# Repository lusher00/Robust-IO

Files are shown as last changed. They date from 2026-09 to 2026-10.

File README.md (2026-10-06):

# Robust IO

A rugged industrial I/O board designed in KiCad 10.

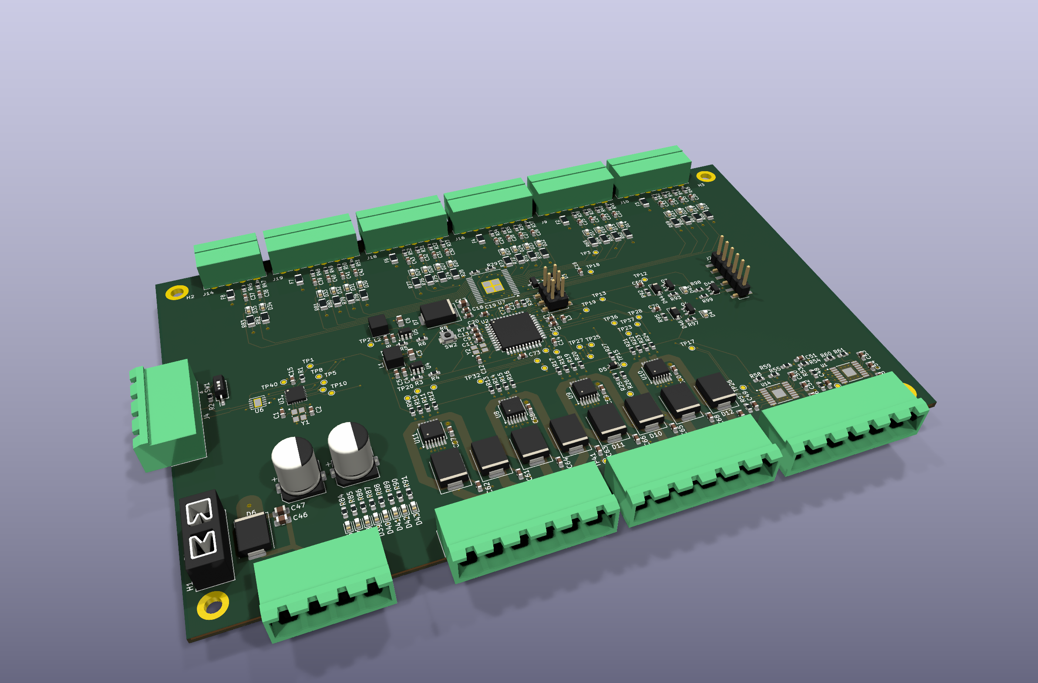
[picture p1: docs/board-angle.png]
Robust IO rev A, 3D render


## Status

- **Rev A:** released to fabrication on 2026-10-05 (JLCPCB, 5 bare boards,
  2 assembled). Not yet powered or tested.
- **Schematic:** complete across four hierarchical sheets. ERC clean.
- **PCB layout:** fully routed. DRC reports 0 errors and 4 library-mismatch
  warnings (J20, U1, U14, U7), which are intentional local footprint edits.

## Board

| Item | Value |
|---|---|
| Size | 160 x 100 mm, four M3 mounting holes |
| Layers | 4: F.Cu signal, In1 GND plane, In2 +24V plane, B.Cu signal |
| Copper | 2 oz outer, 1 oz inner |
| Minimum drill | 0.3 mm |
| Supply | 24 V nominal through a blade fuse (F1) and SMDJ24A TVS |
| Assembly | SMD parts on top side only; through-hole connectors and fuse holder hand-fitted |

## Architecture

| Sheet | Contents |
|---|---|
| `power` | Two TPS560430 buck regulators (+5V, +3.3V), input fuse, TVS, bulk capacitors |
| `processor` | ATmega1284P, MCP2515 + MCP2562 (CAN), crystals, ISP header (J1), UART header (J20), reset button |
| `inputs` | MC33978 22-channel switch detect with fused, filtered inputs and status LEDs |
| `outputs2` | Four BTS7008-2EPA dual high-side switches (8 outputs), two DRV8876 motor drivers |

## Connectors

- **J1:** 2x3 2.54 mm SMD header, AVR ISP (SPI is also on test points).
- **J20:** 1x6 2.54 mm SMD header, 3.3 V TTL UART in FTDI cable pinout.
  RX and TX have series resistors and a TVS array.
- **J14, J19, J18, J16, J9, J10 (top edge):** 3.5 mm pluggable terminal
  headers for the switch inputs, each with a fused supply pin and ground.
- **J15 (bottom edge):** 24 V supply input and ground.
- **J3, J5 (bottom edge):** high-side outputs OUT_0 to OUT_7, with +24V and
  ground.
- **J6 (bottom edge):** two motor driver outputs, with +24V and ground.
- **J4 (left edge):** CAN bus, +5V and ground. SW1 is next to it.

## Test points

41 test points (35 top, 6 bottom) cover the supply rails, SPI, UART, CAN
interrupt, driver control and sense lines, and ground. Positions and nets are
listed in `fab/robust-io-testpoints.csv`.

## Known limits of rev A

- The BTS7008-2EPA is rated for a 28 V maximum supply. Use a regulated 24 V
  supply; do not connect directly to a charging battery system.
- Reverse polarity protection is the fuse and TVS only. There is no series
  reverse-blocking stage.
- The input polyfuses are rated 30 V, which is a small margin over 24 V.
- Y1 load capacitors (22 pF) have not been matched to the crystal's
  specified load capacitance.
- Regulator output tracks are 0.2 mm wide.

## Files

- `robust-io.kicad_pro` - project file
- `robust-io.kicad_sch` - root sheet
- `power.kicad_sch`, `processor.kicad_sch`, `inputs.kicad_sch`, `outputs2.kicad_sch` - schematic sheets
- `robust-io.kicad_pcb` - PCB layout
- `robust-io.kicad_sym`, `sym-lib-table` - project symbol library
- `robust-io.kicad_dru` - custom design rules
- `DRC.rpt`, `ERC.rpt` - latest check reports

## Documentation (`docs/`)

| File | Content |
|---|---|
| [robust-io-schematic.pdf](docs/robust-io-schematic.pdf) | Schematic, all sheets |
| [layout-top.pdf](docs/layout-top.pdf), [layout-bottom.pdf](docs/layout-bottom.pdf) | Copper and silkscreen per side |
| [assembly-top.pdf](docs/assembly-top.pdf) | Assembly drawing with reference designators |
| [board-top.png](docs/board-top.png), [board-bottom.png](docs/board-bottom.png) | 3D renders |

Regenerate with `bash docs/make_docs.sh` after saving the schematic and board.

## Firmware (`firmware/`)

ATmega1284P firmware 0.3: UART service console, CAN protocol with host timeout,
output current trip, motor control, EEPROM settings and a self-test. Not yet run
on hardware. Build with `make` in `firmware/` (avr-gcc); `make fuses` and
`make flash` program the board from a Raspberry Pi wired to J1. See
[firmware/DESIGN.md](firmware/DESIGN.md) for the pin map, console commands,
CAN frame layouts and settings.

## Host tools (`tools/`)

Everything for talking to the board over CAN from a Pi, laptop or robot:
a DBC file, a Python package with the `robustio` command-line tool, a terminal
dashboard, a browser dashboard, a bring-up and end-of-line test runner that
writes a report per board, and a ROS 2 driver node. All of them also run
against the firmware simulator, so they can be used before hardware exists.
See [tools/README.md](tools/README.md).

## Fabrication outputs (`fab/`)

| File | Purpose |
|---|---|
| `make_gerbers.sh` | Plots Gerbers, drill files and the position file with kicad-cli, then zips the Gerbers |
| `gerbers/`, `robust-io-gerbers.zip` | Gerber and Excellon drill files |
| `robust-io-BOM-JLC-smd.csv` | JLCPCB assembly BOM, 50 lines, LCSC part number on every line |
| `robust-io-CPL-JLC.csv` | JLCPCB placement file |
| `cpl_rotation_offsets.json` | Per-part rotation corrections applied to the placement file |
| `kicad-pos.csv` | Raw KiCad position export |
| `robust-io-BOM-tht.csv` | Through-hole parts to fit by hand (fuse holder, terminal headers) |
| `robust-io-testpoints.csv` | Test point list with nets and positions |
| `robust-io-fab-all.zip` | Everything above in one archive |

To regenerate the Gerbers after a board change, save the board in KiCad and run:

    bash fab/make_gerbers.sh

The placement file is not produced by the script. JLCPCB's rotation
convention differs from KiCad's for some packages, so the rotation for each
part in `robust-io-CPL-JLC.csv` is the KiCad rotation plus the offset in
`cpl_rotation_offsets.json`. Regenerate it whenever parts move, and check
the result in JLCPCB's placement preview before ordering.

## Bring-up order

1. Fit F1 and J15. Apply 24 V from a current-limited supply
   with nothing else connected.
2. Check +5V (TP2) and +3.3V (TP1) against ground.
3. Program the ATmega1284P over J1 and confirm the clock and UART on J20.
4. Bring up SPI to the MC33978 and MCP2515.
5. Enable the high-side outputs and motor drivers one channel at a time.

## License

See [LICENSE](LICENSE). Free for personal, educational, and open-source use.
For commercial licensing, contact ryan.lush@gmail.com.

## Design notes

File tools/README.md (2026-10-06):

# Robust IO host tools

Everything here talks to the board over CAN using the protocol in
`firmware/DESIGN.md` section 9.

| Item | What it is |
|---|---|
| `robustio-node0.dbc` | DBC file for node 0. Opens in SavvyCAN, PCAN-View, cantools, Vector tools and most CAN loggers, so every frame decodes to named signals |
| `python/robustio/` | Python package: protocol, `RobustIO` device class, `robustio` command-line tool, terminal dashboard, browser dashboard, bring-up test runner, DBC generator, simulator bus |
| `python/tests/` | Protocol and DBC tests, and end-to-end tests of the tools against the firmware running in the simulator |
| `ros2/robustio_ros/` | ROS 2 driver node: inputs, outputs, currents and motors as topics, services, `/diagnostics` |

## Install

    pip install -e tools/python            # add [test] for pytest and cantools

Needs Python 3.8 or later and python-can, which supports SocketCAN (Raspberry Pi
CAN HATs, most USB adapters on Linux), slcan/CANable, PEAK PCAN, gs_usb and
others.

## Command-line tool

    robustio scan                     list Robust IO nodes on the bus
    robustio status                   one status snapshot
    robustio watch                    live status screen
    robustio dump                     every decoded frame
    robustio out 3 on                 switch output 3 on and hold it (Ctrl-C ends)
    robustio out all off
    robustio motor 0 40               run motor 0 at 40 % and hold it
    robustio motor off
    robustio clear                    clear latched output trips and the motor fault
    robustio cfg                      all settings
    robustio cfg timeout 1000         change one setting
    robustio cfg save                 write settings to EEPROM
    robustio dbc -n 3 -o node3.dbc    DBC file for another node number
    robustio tui                      terminal dashboard
    robustio web                      browser dashboard on http://127.0.0.1:8080/
    robustio bringup --console /dev/serial0 --serial RA-0001
                                      bring-up / end-of-line test with a written report

Global options: `-i` interface (default socketcan), `-c` channel (default can0),
`-b` bitrate (default 250000), `-n` node (default 0). The same values can be set
in the environment as `ROBUSTIO_INTERFACE`, `ROBUSTIO_CHANNEL`,
`ROBUSTIO_BITRATE` and `ROBUSTIO_NODE`.

The board turns everything off when the host goes quiet for the configured
timeout (500 ms by default). `out` and `motor` therefore keep running and repeat
a keepalive frame until Ctrl-C or `--hold SECONDS` ends them; the board then
times out to all off.

SocketCAN on the Pi, once per boot:

    sudo ip link set can0 up type can bitrate 250000

## Terminal dashboard

`robustio tui` shows inputs, outputs with current, motors and CAN state on one
screen. Keys: `0`-`7` toggle an output, `a` all off, `m` set a motor duty (typed),
`s` stop, `c` clear faults, `q` quit. Quitting sends stop.

## Browser dashboard

`robustio web` serves a page with the same view plus every setting, using only
the Python standard library. Motor duty and settings are typed number fields.
The keepalive runs only while a page is polling, so closing the tab, losing the
network or stopping the server lets the board time out to all off.

It listens on 127.0.0.1 by default. `--host 0.0.0.0` makes it reachable from
other machines, for example to open the Pi's dashboard from a laptop. There is
no login: anyone who can reach the port can switch outputs and run motors.

## Bring-up and end-of-line test

    robustio bringup --console /dev/serial0 --serial RA-0001 [--loads] [--report DIR]

Runs `ver` and `selftest` on the J20 console, then checks over CAN: status
frames, matching firmware version, error counters, settings, every output by
command, both motors, and that outputs drop when the host goes quiet. Writes
`bringup-<serial>-<date>.txt` and exits non-zero if anything failed.

Without `--loads` it expects nothing connected to the outputs and motors. With
`--loads` the self-test also pulses each output and runs each motor, and every
output must draw at least `--min-amps` (0.1 A default). `--console` needs
pyserial (`pip install -e "tools/python[bringup]"`); leave it out to run only
the CAN checks.

## ROS 2

See `ros2/robustio_ros/README.md`.

## Python

    import can
    from robustio import RobustIO

    with RobustIO(can.Bus(interface="socketcan", channel="can0"), node=0) as io:
        io.wait_ready()
        io.set_output(3, True)
        io.set_motors(40, 0)
        print(io.inputs.as_dict(), io.currents.amps, io.motors.amps)
        io.config_set("debounce", 30)

`RobustIO` keeps the latest of every status frame (`inputs`, `outputs`,
`currents`, `motors`, `heartbeat`), sends the keepalive in the background once
anything has been commanded, and accepts listeners that are called for each
decoded frame.

## Without hardware

The firmware simulator in `firmware/test` can run in real time with its CAN
traffic on a local UDP port, and every tool here can use it:

    bash firmware/test/run_sim.sh live        terminal 1: the firmware, console on stdin
    robustio -i sim watch                      terminal 2 (or tui, web, cfg, ...)
    robustio bringup --sim                     starts its own simulator and runs the full test

The simulated board has no loads or switches attached; output currents read
zero and inputs stay open unless you drive the console or the models.

## Tests

    cd tools/python && pytest

The end-to-end tests start the simulator themselves and are skipped if
`firmware/build/sim` has not been built (`bash firmware/test/run_sim.sh` builds it).

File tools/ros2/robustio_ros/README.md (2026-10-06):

# robustio_ros

ROS 2 driver for the Robust IO board. It uses the `robustio` Python package in
`tools/python`, so that has to be installed in the same Python environment:

    pip install -e tools/python        # add --break-system-packages on Ubuntu 24.04

Build and run (from a colcon workspace that contains or links this folder):

    colcon build --packages-select robustio_ros
    source install/setup.bash
    ros2 launch robustio_ros robustio.launch.py

Settings are in `config/robustio.yaml`: CAN interface and channel, board node
number, publish rate and command timeout.

## Topics and services

| Name | Type | |
|---|---|---|
| `/robustio/inputs` | std_msgs/UInt32 | bit n = input n closed (0..13 SG0..SG13, 14..21 SP0..SP7) |
| `/robustio/output_states` | std_msgs/UInt8MultiArray | masks: commanded, on, tripped, device fault, off but high |
| `/robustio/output_currents` | std_msgs/Float32MultiArray | 8 values, A |
| `/robustio/motor_duty` | std_msgs/Int8MultiArray | actual duty, % |
| `/robustio/motor_currents` | std_msgs/Float32MultiArray | 2 values, A |
| `/diagnostics` | diagnostic_msgs/DiagnosticArray | 1 Hz, OK / WARN / ERROR with details |
| `/robustio/outputs_cmd` | std_msgs/UInt8MultiArray, subscribed | `[mask, values]` |
| `/robustio/motor_cmd` | std_msgs/Int8MultiArray, subscribed | `[duty0, duty1]`, -100..100 % |
| `/robustio/stop` | std_srvs/Trigger | outputs off, motors 0 |
| `/robustio/clear_faults` | std_srvs/Trigger | clear latched trips and the motor fault |

Examples:

    ros2 topic pub -r 10 /robustio/outputs_cmd std_msgs/UInt8MultiArray "{data: [8, 8]}"     # output 3 on
    ros2 topic pub -r 10 /robustio/motor_cmd std_msgs/Int8MultiArray "{data: [40, 0]}"
    ros2 service call /robustio/stop std_srvs/srv/Trigger

## Safety

The node keeps the board's host timeout satisfied only while commands keep
arriving: if nothing is published on `outputs_cmd` or `motor_cmd` for
`cmd_timeout` seconds (0.5 by default), it stops the keepalive and the board
switches everything off. Publish commands at a steady rate (the `-r 10` above),
not once. If the controlling node crashes, the board turns off.

## Without hardware

Run the firmware simulator (`bash firmware/test/run_sim.sh live`) and set
`interface: sim` and `channel: 127.0.0.1:29536` in the parameters.

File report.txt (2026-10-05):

Info: Processing symbol 'H4:MountingHole:MountingHole_3.2mm_M3_DIN965_Pad_TopBottom'.
Info: Processing symbol 'J1:Connector_PinHeader_2.54mm:PinHeader_2x03_P2.54mm_Vertical_SMD'.
Info: Processing symbol 'C3:Capacitor_SMD:C_0805_2012Metric_Pad1.18x1.45mm_HandSolder'.
Info: Processing symbol 'C4:Capacitor_SMD:C_0603_1608Metric_Pad1.08x0.95mm_HandSolder'.
Info: Processing symbol 'C5:Capacitor_SMD:C_0603_1608Metric_Pad1.08x0.95mm_HandSolder'.
Info: Processing symbol 'C6:Capacitor_SMD:C_0805_2012Metric_Pad1.18x1.45mm_HandSolder'.
Info: Processing symbol 'C7:Capacitor_SMD:C_0603_1608Metric_Pad1.08x0.95mm_HandSolder'.
Info: Processing symbol 'C8:Capacitor_SMD:C_0603_1608Metric_Pad1.08x0.95mm_HandSolder'.
Info: Processing symbol 'C9:Capacitor_SMD:C_0603_1608Metric'.
Info: Processing symbol 'C10:Capacitor_SMD:C_0603_1608Metric'.
Info: Processing symbol 'C11:Capacitor_SMD:C_0603_1608Metric'.
Info: Processing symbol 'C12:Capacitor_SMD:C_0603_1608Metric'.
Info: Processing symbol 'C13:Capacitor_SMD:C_0603_1608Metric'.
Info: Processing symbol 'C14:Capacitor_SMD:C_0603_1608Metric'.
Info: Processing symbol 'C15:Capacitor_SMD:C_0603_1608Metric'.
Info: Processing symbol 'C16:Capacitor_SMD:C_0603_1608Metric'.
Info: Processing symbol 'C17:Capacitor_SMD:C_0603_1608Metric'.
Info: Processing symbol 'C18:Capacitor_SMD:C_0603_1608Metric'.
Info: Processing symbol 'C19:Capacitor_SMD:C_0603_1608Metric'.
Info: Processing symbol 'C20:Capacitor_SMD:C_0603_1608Metric'.
Info: Processing symbol 'C21:Capacitor_SMD:C_0603_1608Metric'.
Info: Processing symbol 'C22:Capacitor_SMD:C_0603_1608Metric'.
Info: Processing symbol 'C23:Capacitor_SMD:C_0603_1608Metric'.
Info: Processing symbol 'C24:Capacitor_SMD:C_0603_1608Metric'.
Info: Processing symbol 'C25:Capacitor_SMD:C_0603_1608Metric'.
Info: Processing symbol 'C26:Capacitor_SMD:C_0603_1608Metric'.
Info: Processing symbol 'C27:Capacitor_SMD:C_0603_1608Metric'.
Info: Processing symbol 'C28:Capacitor_SMD:C_0603_1608Metric'.
Info: Processing symbol 'C29:Capacitor_SMD:C_0603_1608Metric'.
Info: Processing symbol 'C30:Capacitor_SMD:C_0603_1608Metric'.
Info: Processing symbol 'C31:Capacitor_SMD:C_0603_1608Metric'.
Info: Processing symbol 'C32:Capacitor_SMD:C_0603_1608Metric'.
Info: Processing symbol 'C33:Capacitor_SMD:C_0603_1608Metric'.
Info: Processing symbol 'C34:Capacitor_SMD:C_0603_1608Metric'.
Info: Processing symbol 'C35:Capacitor_SMD:C_0603_1608Metric'.
Info: Processing symbol 'C36:Capacitor_SMD:C_0603_1608Metric'.
Info: Processing symbol 'C37:Capacitor_SMD:C_0603_1608Metric'.
Info: Processing symbol 'C38:Capacitor_SMD:C_0603_1608Metric'.
Info: Processing symbol 'C39:Capacitor_SMD:C_0603_1608Metric'.
Info: Processing symbol 'C40:Capacitor_SMD:C_0603_1608Metric'.
Info: Processing symbol 'C41:Capacitor_SMD:C_0603_1608Metric'.
Info: Processing symbol 'C42:Capacitor_SMD:C_0603_1608Metric'.
Info: Processing symbol 'C43:Capacitor_SMD:C_0603_1608Metric'.
Info: Processing symbol 'C44:Capacitor_SMD:C_0805_2012Metric_Pad1.18x1.45mm_HandSolder'.
Info: Processing symbol 'C45:Capacitor_SMD:C_0805_2012Metric_Pad1.18x1.45mm_HandSolder'.
Info: Processing symbol 'C46:Capacitor_SMD:C_0805_2012Metric_Pad1.18x1.45mm_HandSolder'.
Info: Processing symbol 'C47:Capacitor_SMD:C_0805_2012Metric_Pad1.18x1.45mm_HandSolder'.
Info: Processing symbol 'C48:Capacitor_SMD:C_0603_1608Metric_Pad1.08x0.95mm_HandSolder'.
Info: Processing symbol 'C49:Capacitor_SMD:C_0603_1608Metric_Pad1.08x0.95mm_HandSolder'.
Info: Processing symbol 'C50:Capacitor_SMD:C_0603_1608Metric_Pad1.08x0.95mm_HandSolder'.
Info: Processing symbol 'C51:Capacitor_SMD:C_0603_1608Metric_Pad1.08x0.95mm_HandSolder'.
Info: Processing symbol 'C52:Capacitor_SMD:C_0603_1608Metric_Pad1.08x0.95mm_HandSolder'.
Info: Processing symbol 'C53:Capacitor_SMD:C_0603_1608Metric_Pad1.08x0.95mm_HandSolder'.
Info: Processing symbol 'C54:Capacitor_SMD:C_0603_1608Metric_Pad1.08x0.95mm_HandSolder'.
Info: Processing symbol 'C55:Capacitor_SMD:C_0603_1608Metric_Pad1.08x0.95mm_HandSolder'.
Info: Processing symbol 'C56:Capacitor_SMD:C_0603_1608Metric_Pad1.08x0.95mm_HandSolder'.
Info: Processing symbol 'C57:Capacitor_SMD:C_0603_1608Metric_Pad1.08x0.95mm_HandSolder'.
Info: Processing symbol 'C58:Capacitor_SMD:C_0603_1608Metric_Pad1.08x0.95mm_HandSolder'.
Info: Processing symbol 'C59:Capacitor_SMD:C_0603_1608Metric_Pad1.08x0.95mm_HandSolder'.
Info: Processing symbol 'C60:Capacitor_SMD:C_0603_1608Metric_Pad1.08x0.95mm_HandSolder'.
Info: Processing symbol 'C61:Capacitor_SMD:C_0603_1608Metric_Pad1.08x0.95mm_HandSolder'.
Info: Processing symbol 'C62:Capacitor_SMD:C_0603_1608Metric_Pad1.08x0.95mm_HandSolder'.
Info: Processing symbol 'C63:Capacitor_SMD:C_0603_1608Metric_Pad1.08x0.95mm_HandSolder'.
Info: Processing symbol 'C64:Capacitor_SMD:C_0603_1608Metric_Pad1.08x0.95mm_HandSolder'.
Info: Processing symbol 'C65:Capacitor_SMD:C_0603_1608Metric_Pad1.08x0.95mm_HandSolder'.
Info: Processing symbol 'C66:Capacitor_SMD:C_0603_1608Metric_Pad1.08x0.95mm_HandSolder'.
Info: Processing symbol 'C67:Capacitor_SMD:C_0603_1608Metric_Pad1.08x0.95mm_HandSolder'.
Info: Processing symbol 'C68:Capacitor_SMD:C_0603_1608Metric_Pad1.08x0.95mm_HandSolder'.
Info: Processing symbol 'C69:Capacitor_SMD:C_0603_1608Metric'.
Info: Processing symbol 'C70:Capacitor_SMD:C_0603_1608Metric'.
Info: Processing symbol 'C71:Capacitor_SMD:C_0603_1608Metric'.
Info: Processing symbol 'C72:Capacitor_SMD:C_0603_1608Metric'.
Info: Processing symbol 'C73:Capacitor_SMD:C_0603_1608Metric'.
Info: Processing symbol 'D1:Package_TO_SOT_SMD:SOT-23'.
Info: Processing symbol 'D2:Diode_SMD:D_SMC'.
Info: Processing symbol 'D3:Package_TO_SOT_SMD:SOT-23'.
Info: Processing symbol 'D4:Diode_SMD:D_SMC'.
Info: Processing symbol 'D5:Diode_SMD:D_SOD-323'.
Info: Processing symbol 'D6:Diode_SMD:D_SMC'.
Info: Processing symbol 'D7:Diode_SMD:D_SMC'.
Info: Processing symbol 'D8:Diode_SMD:D_SMC'.
Info: Processing symbol 'D9:Diode_SMD:D_SMC'.
Info: Processing symbol 'D10:Diode_SMD:D_SMC'.
Info: Processing symbol 'D11:Diode_SMD:D_SMC'.
Info: Processing symbol 'D12:Diode_SMD:D_SMC'.
Info: Processing symbol 'D13:Diode_SMD:D_SMC'.
Info: Processing symbol 'D14:LED_SMD:LED_0603_1608Metric'.
Info: Processing symbol 'D15:LED_SMD:LED_0603_1608Metric'.
Info: Processing symbol 'D16:LED_SMD:LED_0603_1608Metric'.
Info: Processing symbol 'D17:LED_SMD:LED_0603_1608Metric'.
Info: Processing symbol 'D18:LED_SMD:LED_0603_1608Metric'.
Info: Processing symbol 'D19:LED_SMD:LED_0603_1608Metric'.
Info: Processing symbol 'D20:LED_SMD:LED_0603_1608Metric'.
Info: Processing symbol 'D21:LED_SMD:LED_0603_1608Metric'.
Info: Processing symbol 'D22:LED_SMD:LED_0603_1608Metric'.
Info: Processing symbol 'D23:LED_SMD:LED_0603_1608Metric'.
Info: Processing symbol 'D24:LED_SMD:LED_0603_1608Metric'.
Info: Processing symbol 'D25:LED_SMD:LED_0603_1608Metric'.
Info: Processing symbol 'D26:LED_SMD:LED_0603_1608Metric'.
Info: Processing symbol 'D27:LED_SMD:LED_0603_1608Metric'.
Info: Processing symbol 'D28:LED_SMD:LED_0603_1608Metric'.
Info: Processing symbol 'D29:LED_SMD:LED_0603_1608Metric'.
Info: Processing symbol 'D30:LED_SMD:LED_0603_1608Metric'.
Info: Processing symbol 'D31:LED_SMD:LED_0603_1608Metric'.
Info: Processing symbol 'D32:LED_SMD:LED_0603_1608Metric'.
Info: Processing symbol 'D33:LED_SMD:LED_0603_1608Metric'.
Info: Processing symbol 'D34:LED_SMD:LED_0603_1608Metric'.
Info: Processing symbol 'D35:LED_SMD:LED_0603_1608Metric'.
Info: Processing symbol 'D36:LED_SMD:LED_0603_1608Metric'.
Info: Processing symbol 'D37:LED_SMD:LED_0603_1608Metric'.
Info: Processing symbol 'D38:LED_SMD:LED_0603_1608Metric'.
Info: Processing symbol 'D39:LED_SMD:LED_0603_1608Metric'.
Info: Processing symbol 'D40:LED_SMD:LED_0603_1608Metric'.
Info: Processing symbol 'D41:LED_SMD:LED_0603_1608Metric'.
Info: Processing symbol 'D42:LED_SMD:LED_0603_1608Metric'.
Info: Processing symbol 'D43:LED_SMD:LED_0603_1608Metric'.
Info: Processing symbol 'D44:Diode_SMD:D_SOD-123'.
Info: Processing symbol 'D45:LED_SMD:LED_0603_1608Metric'.
Info: Processing symbol 'D46:Diode_SMD:D_SOD-123'.
Info: Processing symbol 'D47:LED_SMD:LED_0603_1608Metric'.
Info: Processing symbol 'F1:Fuse:Fuseholder_Blade_Mini_Keystone_3568'.
Info: Processing symbol 'F2:Fuse:Fuse_1206_3216Metric'.
Info: Processing symbol 'F3:Fuse:Fuse_1206_3216Metric'.
Info: Processing symbol 'F4:Fuse:Fuse_1206_3216Metric'.
Info: Processing symbol 'F6:Fuse:Fuse_1206_3216Metric'.
Info: Processing symbol 'F7:Fuse:Fuse_1206_3216Metric'.
Info: Processing symbol 'F8:Fuse:Fuse_1206_3216Metric'.
Info: Processing symbol 'H1:MountingHole:MountingHole_3.2mm_M3_DIN965_Pad_TopBottom'.
Info: Processing symbol 'H2:MountingHole:MountingHole_3.2mm_M3_DIN965_Pad_TopBottom'.
Info: Processing symbol 'H3:MountingHole:MountingHole_3.2mm_M3_DIN965_Pad_TopBottom'.
Info: Processing symbol 'C1:Capacitor_SMD:C_0603_1608Metric'.
Info: Processing symbol 'C2:Capacitor_SMD:C_0603_1608Metric'.
Info: Processing symbol 'J3:Connector_Phoenix_MSTB:PhoenixContact_MSTBA_2,5_6-G-5,08_1x06_P5.08mm_Horizontal'.
Info: Processing symbol 'J4:Connector_Phoenix_MSTB:PhoenixContact_MSTBA_2,5_4-G-5,08_1x04_P5.08mm_Horizontal'.
Info: Processing symbol 'J5:Connector_Phoenix_MSTB:PhoenixContact_MSTBA_2,5_6-G-5,08_1x06_P5.08mm_Horizontal'.
Info: Processing symbol 'J6:Connector_Phoenix_MSTB:PhoenixContact_MSTBA_2,5_6-G-5,08_1x06_P5.08mm_Horizontal'.
Info: Processing symbol 'J9:Connector_Phoenix_MC:PhoenixContact_MC_1,5_6-G-3.5_1x06_P3.50mm_Horizontal'.
Info: Processing symbol 'J10:Connector_Phoenix_MC:PhoenixContact_MC_1,5_6-G-3.5_1x06_P3.50mm_Horizontal'.
Info: Processing symbol 'J14:Connector_Phoenix_MC:PhoenixContact_MC_1,5_4-G-3.5_1x04_P3.50mm_Horizontal'.
Info: Processing symbol 'J15:Connector_Phoenix_MSTB:PhoenixContact_MSTBA_2,5_4-G-5,08_1x04_P5.08mm_Horizontal'.
Info: Processing symbol 'J16:Connector_Phoenix_MC:PhoenixContact_MC_1,5_6-G-3.5_1x06_P3.50mm_Horizontal'.
Info: Processing symbol 'J18:Connector_Phoenix_MC:PhoenixContact_MC_1,5_6-G-3.5_1x06_P3.50mm_Horizontal'.
Info: Processing symbol 'J19:Connector_Phoenix_MC:PhoenixContact_MC_1,5_6-G-3.5_1x06_P3.50mm_Horizontal'.
Info: Processing symbol 'L1:Inductor_SMD:L_0805_2012Metric_Pad1.05x1.20mm_HandSolder'.
Info: Processing symbol 'L2:Inductor_SMD:L_0805_2012Metric'.
Info: Processing symbol 'L3:Capacitor_SMD:C_0603_1608Metric'.
Info: Processing symbol 'Q3:Package_TO_SOT_SMD:SOT-23'.
Info: Processing symbol 'Q4:Package_TO_SOT_SMD:SOT-23'.
Info: Processing symbol 'R1:Resistor_SMD:R_0603_1608Metric_Pad0.98x0.95mm_HandSolder'.
Info: Processing symbol 'R2:Resistor_SMD:R_0603_1608Metric_Pad0.98x0.95mm_HandSolder'.
Info: Processing symbol 'R3:Resistor_SMD:R_0603_1608Metric_Pad0.98x0.95mm_HandSolder'.
Info: Processing symbol 'R4:Resistor_SMD:R_0603_1608Metric_Pad0.98x0.95mm_HandSolder'.
Info: Processing symbol 'R5:Resistor_SMD:R_0603_1608Metric_Pad0.98x0.95mm_HandSolder'.
Info: Processing symbol 'R6:Resistor_SMD:R_0603_1608Metric_Pad0.98x0.95mm_HandSolder'.
Info: Processing symbol 'R7:Resistor_SMD:R_0603_1608Metric_Pad0.98x0.95mm_HandSolder'.
Info: Processing symbol 'R8:Resistor_SMD:R_0603_1608Metric_Pad0.98x0.95mm_HandSolder'.
Info: Processing symbol 'R9:Resistor_SMD:R_0603_1608Metric'.
Info: Processing symbol 'R10:Resistor_SMD:R_0603_1608Metric'.
Info: Processing symbol 'R11:Resistor_SMD:R_0603_1608Metric'.
Info: Processing symbol 'R12:Resistor_SMD:R_0603_1608Metric'.
Info: Processing symbol 'R13:Resistor_SMD:R_0603_1608Metric'.
Info: Processing symbol 'R14:Resistor_SMD:R_0603_1608Metric'.
Info: Processing symbol 'R15:Resistor_SMD:R_0603_1608Metric'.
Info: Processing symbol 'R16:Resistor_SMD:R_0603_1608Metric'.
Info: Processing symbol 'R17:Resistor_SMD:R_0603_1608Metric'.
Info: Processing symbol 'R18:Resistor_SMD:R_0603_1608Metric'.
Info: Processing symbol 'R19:Resistor_SMD:R_0603_1608Metric'.
Info: Processing symbol 'R20:Resistor_SMD:R_0603_1608Metric'.
Info: Processing symbol 'R21:Resistor_SMD:R_0603_1608Metric'.
Info: Processing symbol 'R22:Resistor_SMD:R_0603_1608Metric'.
Info: Processing symbol 'R23:Resistor_SMD:R_0603_1608Metric'.
Info: Processing symbol 'R24:Resistor_SMD:R_0603_1608Metric'.
Info: Processing symbol 'R25:Resistor_SMD:R_0603_1608Metric'.
Info: Processing symbol 'R26:Resistor_SMD:R_0603_1608Metric'.
Info: Processing symbol 'R27:Resistor_SMD:R_0603_1608Metric_Pad0.98x0.95mm_HandSolder'.
Info: Processing symbol 'R28:Resistor_SMD:R_0603_1608Metric_Pad0.98x0.95mm_HandSolder'.
Info: Processing symbol 'R29:Resistor_SMD:R_0603_1608Metric_Pad0.98x0.95mm_HandSolder'.
Info: Processing symbol 'R30:Resistor_SMD:R_0603_1608Metric_Pad0.98x0.95mm_HandSolder'.
Info: Processing symbol 'R31:Resistor_SMD:R_0603_1608Metric_Pad0.98x0.95mm_HandSolder'.
Info: Processing symbol 'R32:Resistor_SMD:R_0603_1608Metric_Pad0.98x0.95mm_HandSolder'.
Info: Processing symbol 'R33:Resistor_SMD:R_0603_1608Metric_Pad0.98x0.95mm_HandSolder'.
Info: Processing symbol 'R34:Resistor_SMD:R_0603_1608Metric_Pad0.98x0.95mm_HandSolder'.
Info: Processing symbol 'R35:Resistor_SMD:R_0603_1608Metric_Pad0.98x0.95mm_HandSolder'.
Info: Processing symbol 'R36:Resistor_SMD:R_0603_1608Metric_Pad0.98x0.95mm_HandSolder'.
Info: Processing symbol 'R37:Resistor_SMD:R_0603_1608Metric_Pad0.98x0.95mm_HandSolder'.
Info: Processing symbol 'R38:Resistor_SMD:R_0603_1608Metric_Pad0.98x0.95mm_HandSolder'.
Info: Processing symbol 'R39:Resistor_SMD:R_0603_1608Metric_Pad0.98x0.95mm_HandSolder'.
Info: Processing symbol 'R40:Resistor_SMD:R_0603_1608Metric_Pad0.98x0.95mm_HandSolder'.
Info: Processing symbol 'R41:Resistor_SMD:R_0603_1608Metric_Pad0.98x0.95mm_HandSolder'.
Info: Processing symbol 'R42:Resistor_SMD:R_0603_1608Metric_Pad0.98x0.95mm_HandSolder'.
Info: Processing symbol 'R43:Resistor_SMD:R_0603_1608Metric_Pad0.98x0.95mm_HandSolder'.
Info: Processing symbol 'R44:Resistor_SMD:R_0603_1608Metric_Pad0.98x0.95mm_HandSolder'.
Info: Processing symbol 'R45:Resistor_SMD:R_0603_1608Metric_Pad0.98x0.95mm_HandSolder'.
Info: Processing symbol 'R46:Resistor_SMD:R_0603_1608Metric_Pad0.98x0.95mm_HandSolder'.
Info: Processing symbol 'R47:Resistor_SMD:R_0603_1608Metric_Pad0.98x0.95mm_HandSolder'.
Info: Processing symbol 'R48:Resistor_SMD:R_0603_1608Metric_Pad0.98x0.95mm_HandSolder'.
Info: Processing symbol 'R49:Resistor_SMD:R_0603_1608Metric_Pad0.98x0.95mm_HandSolder'.
Info: Processing symbol 'R50:Resistor_SMD:R_0603_1608Metric_Pad0.98x0.95mm_HandSolder'.
Info: Processing symbol 'R51:Resistor_SMD:R_0603_1608Metric_Pad0.98x0.95mm_HandSolder'.
Info: Processing symbol 'R52:Resistor_SMD:R_0603_1608Metric_Pad0.98x0.95mm_HandSolder'.
Info: Processing symbol 'R53:Resistor_SMD:R_0603_1608Metric_Pad0.98x0.95mm_HandSolder'.
Info: Processing symbol 'R54:Resistor_SMD:R_0603_1608Metric_Pad0.98x0.95mm_HandSolder'.
Info: Processing symbol 'R55:Resistor_SMD:R_0603_1608Metric_Pad0.98x0.95mm_HandSolder'.
Info: Processing symbol 'R56:Resistor_SMD:R_0603_1608Metric_Pad0.98x0.95mm_HandSolder'.
Info: Processing symbol 'R57:Resistor_SMD:R_0603_1608Metric_Pad0.98x0.95mm_HandSolder'.
Info: Processing symbol 'R58:Resistor_SMD:R_0603_1608Metric_Pad0.98x0.95mm_HandSolder'.
Info: Processing symbol 'R59:Resistor_SMD:R_0603_1608Metric_Pad0.98x0.95mm_HandSolder'.
Info: Processing symbol 'R60:Resistor_SMD:R_0603_1608Metric_Pad0.98x0.95mm_HandSolder'.
Info: Processing symbol 'R61:Resistor_SMD:R_0603_1608Metric_Pad0.98x0.95mm_HandSolder'.
Info: Processing symbol 'R62:Resistor_SMD:R_1206_3216Metric'.
Info: Processing symbol 'R63:Resistor_SMD:R_1206_3216Metric'.
Info: Processing symbol 'R64:Resistor_SMD:R_1206_3216Metric'.
Info: Processing symbol 'R65:Resistor_SMD:R_1206_3216Metric'.
Info: Processing symbol 'R66:Resistor_SMD:R_1206_3216Metric'.
Info: Processing symbol 'R67:Resistor_SMD:R_1206_3216Metric'.
Info: Processing symbol 'R68:Resistor_SMD:R_1206_3216Metric'.
Info: Processing symbol 'R69:Resistor_SMD:R_1206_3216Metric'.
Info: Processing symbol 'R70:Resistor_SMD:R_1206_3216Metric'.
Info: Processing symbol 'R71:Resistor_SMD:R_1206_3216Metric'.
Info: Processing symbol 'R72:Resistor_SMD:R_1206_3216Metric'.
Info: Processing symbol 'R73:Resistor_SMD:R_1206_3216Metric'.
Info: Processing symbol 'R74:Resistor_SMD:R_1206_3216Metric'.
Info: Processing symbol 'R75:Resistor_SMD:R_1206_3216Metric'.
Info: Processing symbol 'R76:Resistor_SMD:R_1206_3216Metric'.
Info: Processing symbol 'R77:Resistor_SMD:R_1206_3216Metric'.
Info: Processing symbol 'R78:Resistor_SMD:R_1206_3216Metric'.
Info: Processing symbol 'R79:Resistor_SMD:R_1206_3216Metric'.
Info: Processing symbol 'R80:Resistor_SMD:R_1206_3216Metric'.
Info: Processing symbol 'R81:Resistor_SMD:R_1206_3216Metric'.
Info: Processing symbol 'R82:Resistor_SMD:R_1206_3216Metric'.
Info: Processing symbol 'R83:Resistor_SMD:R_1206_3216Metric'.
Info: Processing symbol 'R84:Resistor_SMD:R_0603_1608Metric_Pad0.98x0.95mm_HandSolder'.
Info: Processing symbol 'R85:Resistor_SMD:R_0603_1608Metric_Pad0.98x0.95mm_HandSolder'.
Info: Processing symbol 'R86:Resistor_SMD:R_0603_1608Metric_Pad0.98x0.95mm_HandSolder'.
Info: Processing symbol 'R87:Resistor_SMD:R_0603_1608Metric_Pad0.98x0.95mm_HandSolder'.
Info: Processing symbol 'R88:Resistor_SMD:R_0603_1608Metric_Pad0.98x0.95mm_HandSolder'.
Info: Processing symbol 'R89:Resistor_SMD:R_0603_1608Metric_Pad0.98x0.95mm_HandSolder'.
Info: Processing symbol 'R90:Resistor_SMD:R_0603_1608Metric_Pad0.98x0.95mm_HandSolder'.
Info: Processing symbol 'R91:Resistor_SMD:R_0603_1608Metric_Pad0.98x0.95mm_HandSolder'.
Info: Processing symbol 'R92:Resistor_SMD:R_0603_1608Metric_Pad0.98x0.95mm_HandSolder'.
Info: Processing symbol 'R93:Resistor_SMD:R_0603_1608Metric_Pad0.98x0.95mm_HandSolder'.
Info: Processing symbol 'R95:Resistor_SMD:R_0603_1608Metric_Pad0.98x0.95mm_HandSolder'.
Info: Processing symbol 'R97:Resistor_SMD:R_0603_1608Metric_Pad0.98x0.95mm_HandSolder'.
Info: Processing symbol 'SW2:rml:KEY-SMD_EVQP9W02W'.
Info: Processing symbol 'U1:rml:IC_DRV8876PWPR'.
Info: Processing symbol 'U2:Package_QFP:TQFP-44_10x10mm_P0.8mm'.
Info: Processing symbol 'U3:Package_DFN_QFN:QFN-20-1EP_4x4mm_P0.5mm_EP2.5x2.5mm'.
Info: Processing symbol 'U4:Package_TO_SOT_SMD:SOT-23-6'.
Info: Processing symbol 'U5:Package_TO_SOT_SMD:SOT-23-6'.
Info: Processing symbol 'U6:Package_SO:SOIC-8-1EP_3.9x4.9mm_P1.27mm_EP2.29x3mm_ThermalVias'.
Info: Processing symbol 'U7:Package_DFN_QFN:QFN-32-1EP_5x5mm_P0.5mm_EP3.7x3.7mm_ThermalVias'.
Info: Processing symbol 'U8:Package_SO:TSSOP-14-1EP_4.4x5mm_P0.65mm'.
Info: Processing symbol 'U9:Package_SO:TSSOP-14-1EP_4.4x5mm_P0.65mm'.
Info: Processing symbol 'U10:Package_SO:TSSOP-14-1EP_4.4x5mm_P0.65mm'.
Info: Processing symbol 'U11:Package_SO:TSSOP-14-1EP_4.4x5mm_P0.65mm'.
Info: Processing symbol 'U14:rml:IC_DRV8876PWPR'.
Info: Processing symbol 'Y1:rml:WE-XTAL_CFPX-180'.
Info: Processing symbol 'Y2:rml:WE-XTAL_CFPX-180'.
Warning: No net found for component U3 pad 19 (no pin 19 in symbol).
Warning: No net found for component U3 pad 21 (no pin 21 in symbol).
Warning: No net found for component U3 pad 20 (no pin 20 in symbol).

Info: Total warnings: 3, errors: 0.

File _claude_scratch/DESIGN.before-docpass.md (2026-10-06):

# Robust IO firmware design

Target: ATmega1284P-AU on Robust IO rev A, 3.3 V, 12 MHz crystal (Y2).
Toolchain: avr-gcc, avr-libc, avrdude, one Makefile. C11, no RTOS, no Arduino core.

Status: firmware 0.3, feature complete for rev A. Compiles without warnings (avr-gcc 7.3). All simulation scenarios in test/ pass against models of the MC33978 and MCP2515. Nothing has run on hardware.

## 1. Goals

1. Prove every subsystem of rev A from a UART console on J20.
2. Use the same drivers for the application, so bring-up code is not thrown away.
3. Fail to a safe state: all outputs off, both motor drivers asleep.

## 2. Pin map

Taken from the rev A netlist (U2 pad nets). The same map is in `src/board.h`.

| Port | Pin | Net | Direction | Function |
|---|---|---|---|---|
| PA0 | 37 | AMUX0 | analog in, ADC0 | MC33978 analog mux output, through 1k, clamped to 3.3 V |
| PA1 | 36 | ISENSE (filtered) | analog in, ADC1 | BTS7008 current sense, shared by all four devices |
| PA2 | 35 | IPROPIM0 | analog in, ADC2 | Motor 0 current, 1.5 V per amp |
| PA3 | 34 | IPROPIM1 | analog in, ADC3 | Motor 1 current, 1.5 V per amp |
| PA4 | 33 | DEN2 | out | Diagnosis enable, U9 (outputs 4, 5) |
| PA5 | 32 | DEN3 | out | Diagnosis enable, U10 (outputs 6, 7) |
| PA6 | 31 | DSELn | out | Sense channel select, shared by all four BTS7008 |
| PA7 | 30 | nSLEEPMn | out | DRV8876 sleep, shared, low = asleep |
| PB0 | 40 | CS_CAN | out | MCP2515 chip select, active low |
| PB1 | 41 | CS_IN0 | out | MC33978 chip select, active low |
| PB2 | 42 | INT_B0 | in, INT2 | MC33978 interrupt, active low, 10k pull-up |
| PB3 | 43 | DEN0 | out | Diagnosis enable, U11 (outputs 0, 1) |
| PB4 | 44 | DEN1 | out | Diagnosis enable, U8 (outputs 2, 3). Also SPI SS: must stay an output |
| PB5 | 1 | MOSI0 | out | SPI, also ISP |
| PB6 | 2 | MISO0 | in | SPI, also ISP |
| PB7 | 3 | SCLK0 | out | SPI, also ISP |
| PC0..PC7 | 19..26 | DRV_OUT0..7 | out | BTS7008 inputs through 4.7k, high = output on |
| PD0 | 9 | RX0 | in | UART0 from J20 pin 4 through 1k |
| PD1 | 10 | TX0 | out | UART0 to J20 pin 5 through 1k |
| PD2 | 11 | INT_CAN0 | in, INT0 | MCP2515 interrupt, active low |
| PD3 | 12 | FAULTMn | in, INT1 | DRV8876 fault, shared, active low, 10k pull-up |
| PD4 | 13 | PH_M0 | out | Motor 0 direction |
| PD5 | 14 | EN_M0 | out, OC1A | Motor 0 PWM |
| PD6 | 15 | PH_M1 | out | Motor 1 direction |
| PD7 | 16 | EN_M1 | out, OC2A | Motor 1 PWM |

Output numbering: DRV_OUTn drives OUT_n on J3 (0 to 3) and J5 (4 to 7).

| BTS7008 | DEN | DSELn low | DSELn high |
|---|---|---|---|
| U11 | DEN0 | OUT_0 | OUT_1 |
| U8 | DEN1 | OUT_2 | OUT_3 |
| U9 | DEN2 | OUT_4 | OUT_5 |
| U10 | DEN3 | OUT_6 | OUT_7 |

Only one DEN may be high at a time, because all four sense pins share R25 (750 ohm).

## 3. Hardware facts that shape the firmware

These come from the netlist and the device datasheets. Items marked CHECK are to be confirmed on hardware.

- **JTAG shares PC2 to PC5 with DRV_OUT2 to DRV_OUT5.** A factory-fresh ATmega1284P has the JTAGEN fuse programmed, which enables pull-ups on TCK, TMS and TDI (PC2, PC3, PC5). The BTS7008 inputs pull down with only 10 to 25 uA and switch between 0.8 V and 2.0 V, so a 20k to 50k pull-up to 3.3 V through the 4.7k series resistor will hold the input high: expect outputs 2, 3 and 5 to be ON on an unprogrammed chip. Program the fuses with JTAG disabled before any load is wired to J3 or J5. The firmware also sets JTD in MCUCR at start as a second guard.
- **CS_CAN has no pull-up.** During ISP the MCU pins are high impedance, so the MCP2515 chip select floats and the MCP2515 can drive MISO. If programming is unreliable, fit 10k from TP8 (CS_CAN) to TP1 (+3.3V); they are next to each other. The MC33978 CS_B has an internal pull-up to VDDQ (datasheet). Add a CS_CAN pull-up in rev B.
- **SPI bus is shared** by the MCP2515 (mode 0) and the MC33978 (32-bit frames, MSB first, up to 8 MHz, response returned in the following frame). The MC33978 datasheet says it latches MOSI on the rising edge, which is mode 0; `MC33978_SPI_MODE` in `board.h` is the switch if the SPI check (expects 0x123456) fails (CHECK). The SPI driver sets the mode per transaction. Clock is F_CPU/4 = 3 MHz.
- **ADC reference is AVCC (3.3 V).** AREF has only a capacitor.
- **ISENSE scaling:** I_load = V_adc / 750 ohm x kILIS. kILIS is 5400 typical: within 4 % at 5.5 A, 13.5 % at 1 A, 30 % at 100 mA. 3.3 V full scale is about 23 A, about 23 mA per count at 10 bits. The fault signal is a sense current of at least 4.4 mA, which is 3.3 V on R25, so a reading above 3.0 V means fault. With the output off, an open load gives 1.9 to 3.5 mA (1.4 to 2.6 V).
- **Motor current limit is set in hardware.** PMODE is tied low (PH/EN mode). VREF = 3.3 V x 16.2k / 26.2k = 2.04 V and IPROPI is 1.5k, so the DRV8876 regulates at about 1.36 A. Firmware reads current at 1.5 V per amp but cannot raise the limit.
- **nSLEEP and nFAULT are shared** between the two DRV8876. A fault cannot be attributed to one motor from the pin alone; the firmware uses the two IPROPI readings and the commanded state to decide.
- **SP0 to SP7 are configured as switch-to-ground.** SG pins are switch-to-ground only; SP pins are programmable as switch-to-ground or switch-to-battery. On rev A every input, SP included, has an indicator LED and 2.2k from +24V to the IC pin. In switch-to-battery mode that path sources about 8 mA into the pin with the switch open, more than the IC's sustain current sinks, so the input would read closed all the time. Switch-to-battery on an SP channel needs its LED removed (D14 to D17 for SP0 to SP3 on J9, D18 to D21 for SP4 to SP7 on J10). The MC33978 powers up with SP pins in switch-to-battery mode (datasheet), so the driver clears device configuration bits 7 to 0 before the first read.
- **Clocks:** MCU 12 MHz, MCP2515 16 MHz (Y1). 115200 baud at 12 MHz with U2X has 0.16 % error.
- **CAN termination** is SW1 (120 ohm). Not readable by firmware.

## 4. Fuses

| Fuse | Value | Meaning |
|---|---|---|
| low | 0xFF | External crystal 8 to 16 MHz, slowest start-up |
| high | 0xD1 | JTAG disabled, SPI programming enabled, EEPROM kept through chip erase, no bootloader |
| extended | 0xFD | Brown-out at 2.7 V |

`make fuses` writes these. EESAVE (in the high fuse) keeps the saved configuration when `make flash` erases the chip.

### Programmer: Raspberry Pi over SPI

The Pi's GPIO is 3.3 V, so it connects to J1 with no level shifting. avrdude uses the `linuxspi` programmer. Build and flash can both run on the Pi, or the hex file can be built on the Mac and copied over.

| Pi header pin | Pi signal | J1 pin | Board net |
|---|---|---|---|
| 19 | GPIO10 MOSI | 4 | MOSI0 |
| 21 | GPIO9 MISO | 1 | MISO0 |
| 23 | GPIO11 SCLK | 3 | SCLK0 |
| 22 | GPIO25 | 5 | RST |
| 25 | GND | 6 | GND |
| - | - | 2 | +3.3V, leave unconnected |

- Power the board from its own supply before connecting, and share only ground. Do not join the Pi's 3.3 V to the board's 3.3 V.
- SPI must be enabled on the Pi (`dtparam=spi=on`), giving `/dev/spidev0.0`.
- Packages on the Pi: `avrdude` (version 7 or later), plus `gcc-avr` and `avr-libc` if building there.
- Port string: `-c linuxspi -P /dev/spidev0.0:/dev/gpiochip0:25`. On a Pi 5 the header GPIO chip is `gpiochip0` or `gpiochip4` depending on the kernel; `gpiodetect` shows which one is `pinctrl-rp1`.
- A new chip runs from its 1 MHz internal clock, so the first connection must be slow: `-b 100000`. After the fuses select the 12 MHz crystal, `-b 1000000` works.
- Keep the wires short (under about 15 cm).

The Pi's UART can also serve as the J20 console: Pi pin 8 (TXD) to J20 pin 4, Pi pin 10 (RXD) to J20 pin 5, ground to J20 pin 1.

## 5. Architecture

Single foreground loop plus short interrupt handlers. No dynamic memory.

    app        console commands, CAN protocol, output/motor state machines
    --------------------------------------------------------------------
    drivers    mc33978   mcp2515   hsd (BTS7008)   motor (DRV8876)
    --------------------------------------------------------------------
    hal        gpio   spi   uart   adc   tick   pwm   eeprom   wdt
    --------------------------------------------------------------------
    board.h    pin map, scaling constants, F_CPU

Rules:

- Only `hal/` touches AVR registers. Drivers call the HAL. This lets the drivers and the protocol code be compiled and unit-tested on the Mac.
- Interrupt handlers only move bytes or set flags: 1 ms tick (Timer0 CTC), UART RX and TX ring buffers, INT0/INT1/INT2 set "service me" flags. All SPI traffic happens in the foreground, so the bus needs no locking.
- Every module has `init()` and a non-blocking `task()` called from the main loop. No `_delay_ms()` after start-up.

Timers:

| Timer | Use |
|---|---|
| Timer0 | 1 ms system tick (CTC). OC0A/OC0B stay disconnected because PB3/PB4 are DEN0/DEN1 |
| Timer1 | Motor 0 PWM on OC1A, phase-correct 8-bit, 23.5 kHz |
| Timer2 | Motor 1 PWM on OC2A, phase-correct, 23.5 kHz |

Main loop schedule:

| Period | Task |
|---|---|
| every pass | UART console, CAN receive, interrupt flags |
| 1 ms | ADC sequencer step |
| 10 ms | Poll MC33978 inputs (also on INT_B0), debounce, output and motor state machines |
| 100 ms | Periodic CAN status frames, watchdog kick, heartbeat |

## 6. Drivers

**mc33978** - 22 switch inputs (SG0 to SG13, SP0 to SP7).
Init: read device ID, set SP pins as switch-to-ground or switch-to-battery, set wetting current and wetting timer, set thresholds, enable interrupts on change. Run time: read switch status (one 32-bit frame returns all 22 bits), select AMUX channel to read an input voltage, battery sense or die temperature on ADC0. Reports SPI error and over-temperature flags.

**mcp2515** - CAN controller.
Init: reset, set bit timing for the 16 MHz crystal (250 kbit/s default; 125k, 500k and 1M tables included), set filters, enter normal mode. Loopback mode is used for the self-test. Run time: receive from both buffers into a software queue, transmit from a software queue using the three TX buffers, track error counters and bus-off, recover from bus-off after a delay.

**hsd** - eight high-side outputs.
On/off only. PWM is provided on the motor drivers, not on these outputs.
Per channel: commanded state, measured current, status (off, on, overcurrent, open load, fault). The ADC sequencer raises one DEN, sets DSELn, waits for the sense output to settle (datasheet worst case 0.4 ms at small load; the design uses 2 ms), samples ADC1, then moves to the next channel. A full scan of eight channels takes about 20 ms. Software overcurrent trip per channel with configurable limit and time, latched until cleared by command. The BTS7008's own protection remains the backstop.

**motor** - two DRV8876 in PH/EN mode.
Signed duty command, slew-rate limited. nSLEEP is raised when either motor is commanded and dropped when both have been idle for a set time. Fault handling: on FAULTMn low, stop both, record currents, pulse nSLEEP to clear, report.

## 7. Safe state and fault handling

Safe state = DRV_OUT0..7 low, EN_M0/EN_M1 low, nSLEEPMn low.

Entered on:

- Reset, before anything else runs (ports are set in `.init3`, before C start-up).
- Watchdog reset (250 ms watchdog, kicked once per main-loop pass).
- Brown-out.
- Loss of host: after a set-outputs or set-motors frame has been received, no further one for the configured timeout (default 500 ms, 0 disables). Console commands do not start the timeout.

Per-device faults stop only what they affect:

- Output over the software limit for the trip time, or the BTS7008 fault level on two consecutive readings: that output off and latched until cleared.
- DRV8876 nFAULT low: both motors stopped and the drivers put to sleep (which also clears them); motor commands refused until cleared. The fault count and the currents at the time are recorded.
- MC33978 SPI check failing (checked every second): inputs flagged invalid on CAN; the chip is set up again when it answers. A device power-on reset seen in the fault status register also triggers a new setup.
- MCP2515 not answering at start: retried every second.

The reset cause (MCUSR) is saved at start and reported on the console and in the CAN heartbeat.

## 8. Console (UART0, 115200 8N1)

Line-based text commands, used for bring-up and service. `help` lists them.

    ver                        version, reset cause, device check, node, uptime
    in                         debounced and raw inputs, MC33978 fault status
    in watch                   print debounced inputs on change (any key stops)
    in raw <cmd-hex>           read one MC33978 register
    amux [code]                select AMUX channel (6 temperature, 7 battery) and read mV
    out <0-7> <0|1>            switch one output
    out all 0                  all outputs off
    out clear                  clear latched trips and faults
    isense                     state, sense voltage, current and limit per output
    limit <0-7|all> <mA> [ms]  trip level and time
    motor <0|1> <-100..100>    command duty in percent, ramped
    motor off                  stop both now, drivers asleep
    motor clear                clear a latched driver fault
    motor                      status
    can                        status and counters
    can loop                   loopback self-test
    can tx <id-hex> [bytes]    send a standard frame
    cfg                        show settings
    cfg <name> <value>         change a setting
    cfg save | cfg default     write to EEPROM | load defaults (not saved)
    selftest                   checks that switch nothing on: SPI devices, CAN loopback,
                               outputs quiet, motor drivers idle
    selftest out               also pulses each output for 200 ms
    selftest motor             also runs each motor at 20 % both ways
    reset

## 9. CAN protocol

Standard 11-bit IDs, node number N (0 to 15) and bit rate from the configuration. Multi-byte values are little-endian.

| ID | Dir | When | DLC | Data |
|---|---|---|---|---|
| 0x100+N | out | on debounced change, and 100 ms | 4 | d0..d2: input bits, bit n = input n (0..13 SG0..SG13, 14..21 SP0..SP7), 1 = closed. d3: bit0 inputs valid, bit1 MC33978 fault flag (UV, OV, temperature, SPI, hash) |
| 0x110+N | out | 100 ms | 5 | d0 commanded mask, d1 on mask, d2 tripped mask, d3 device-fault mask, d4 off-but-high mask (open load or short to supply) |
| 0x120+N | out | 100 ms | 8 | output 0..7 current, 100 mA per count, 255 = 25.5 A or more |
| 0x130+N | out | 100 ms | 6 | d0, d1 motor 0, 1 duty (signed %), d2, d3 current (10 mA per count), d4 bit0 asleep, bit1 fault latched, bit2 nFAULT low, d5 fault count |
| 0x140+N | out | 1 s | 8 | d0 state, d1 reset cause (MCUSR), d2 version major, d3 version minor, d4 TEC, d5 REC, d6 EFLG, d7 frames dropped |
| 0x200+N | in | | 2 | d0 mask, d1 values: for each bit set in d0, output n is set to bit n of d1 |
| 0x210+N | in | | 2 | d0, d1 motor 0, 1 duty, signed percent -100..100, ramped |
| 0x220+N | in | | 1-2 | d0 output mask to clear, d1 bit0 clear motor fault |
| 0x230+N | in | | 2-4 | d0 op (0 read, 1 write, 2 save, 3 load defaults), d1 key, d2-d3 value |
| 0x240+N | out | reply to 0x230 | 5 | d0 op, d1 key, d2-d3 value, d4 result (0 ok, 1 bad key, 2 bad value, 3 EEPROM failed) |

Heartbeat state bits: 0 host active, 1 host timed out (until the next command), 2 inputs valid, 3 configuration from defaults, 4 motor fault latched, 5 an output is latched off.

A set-outputs or set-motors frame makes the host active and restarts the timeout. Commands to a latched output or motor are ignored until a clear frame.

Transmission: status frames are queued in software and loaded into the MCP2515's three transmit buffers. If frames from the previous 100 ms period are still waiting when the next period starts (no other node acknowledging), they are aborted and counted as dropped, so the bus only ever carries current data.

## 10. Configuration (EEPROM)

One struct with a version byte and CRC16, loaded at start; defaults are used when the CRC fails. Changes take effect at once except node and rate, which apply after `cfg save` and a reset.

| Key | Name | Unit, range | Default |
|---|---|---|---|
| 0x00 | node | 0..15 | 0 |
| 0x01 | rate | kbit/s: 125, 250, 500, 1000 | 250 |
| 0x02 | timeout | host timeout ms, 0 = off, up to 60000 | 500 |
| 0x03 | debounce | ms, 0..250 | 20 |
| 0x04 | wet_sp | SP wetting current mA: 2 6 8 10 12 14 16 20 | 16 |
| 0x05 | wet_sg | SG wetting current mA | 16 |
| 0x06 | slew | motor duty change, % per 10 ms, 1..100 | 10 |
| 0x07 | idle | motor driver sleep delay ms, 0..60000 | 1000 |
| 0x10-0x17 | limit0..7 | output trip level mA, 100..30000 | 5000 |
| 0x18-0x1F | trip0..7 | output trip time ms, 0..10000 | 100 |

Wetting current is applied for 20 ms after a switch closes, then drops to the sustain current (MC33978 default, not changed).

## 11. Layout and build

    firmware/
      Makefile
      DESIGN.md
      src/
        board.h          pin map, scaling, defaults
        version.h
        main.c           start-up, main loop
        hal/             tick, uart, spi, adc
        drivers/         mc33978, mcp2515, hsd (BTS7008), motor (DRV8876)
        app/             config, inputs, canproto, console, selftest
      test/
        sim.c            simavr harness with MC33978 and MCP2515 models
        run_sim.sh       builds it and runs the scenarios

Make targets: `all`, `flash`, `fuses`, `size`, `clean`. The programmer settings are Makefile variables (`PROGRAMMER`, `PORT`, `SPI_HZ`), defaulting to the Raspberry Pi `linuxspi` setup above.

Main loop, every pass: console, output sense scan, motor control, inputs, CAN. Each task keeps its own timing from the 1 ms tick: sense scan one channel per 3 ms, inputs every 5 ms or on INT_B, motor ramp every 10 ms, CAN status every 100 ms, heartbeat every 1 s, device checks every 1 s.

Simulation: `bash test/run_sim.sh [boot|selftest|inputs|can|config|protect|noack]` runs the firmware on simavr against simple models of the two SPI devices. It checks the firmware's logic and protocol handling, not the real chips. Needs simavr and libelf.

## 11a. What is implemented

| Area | State |
|---|---|
| Safe-state start-up, reset cause, watchdog, JTAG disable | done |
| HAL: tick, UART (interrupt driven), SPI, ADC | done |
| MC33978: check, SP mode, wetting current, interrupts, AMUX, fault status, re-setup | done |
| Inputs: 5 ms poll and INT_B, per-input debounce | done |
| MCP2515: bit timing, modes, three TX buffers, abort, receive | done |
| High-side outputs: background sense scan, software trip, device fault, latching | done |
| Motors: ramped PWM, wake and idle sleep, fault latch and clear | done |
| CAN protocol and host timeout | done |
| EEPROM configuration over console and CAN | done |
| Console and selftest | done |
| Simulation scenarios | done; all pass |
| Run on hardware | not yet |

Firmware 0.3: about 19 KB flash, 0.7 KB RAM.

## 12. Bring-up sequence

Each step is one console command and is what `selftest` automates.

1. Fuses, then flash. Heartbeat line appears on J20.
2. `ver` shows the reset cause as power-on.
3. `in`: MC33978 ID reads correctly; shorting an input to ground changes its bit.
4. `can loop` passes; then `can tx` is seen by a second node with SW1 set as needed.
5. `out n 1` with a resistive load on each output in turn; `isense` matches a meter.
6. `motor 0 20`, `motor 0 -20`, same for motor 1; `motor stat` current matches a meter.
7. Remove the host: outputs drop after the timeout.

## 13. Open questions

None blocking. Decisions taken as defaults, all changeable in configuration:

- CAN runs at 250 kbit/s with the IDs in section 9. No existing bus is assumed.
- SP0 to SP7 are switch-to-ground.
- The high-side outputs are on/off only; PWM is on the motor drivers.
- The programmer is a Raspberry Pi over SPI.

To confirm on hardware:

- MC33978 SPI mode (see section 3).
- Which of each BTS7008's two channels reaches which connector pin. The firmware assumes DRV_OUTn switches OUT_n; `out n 1` at bring-up confirms it, and a swap within a pair is a one-line table change.
- The layout of the MC33978 device configuration register above bit 7. The driver reads the register and writes it back with only bits 7 to 0 cleared.

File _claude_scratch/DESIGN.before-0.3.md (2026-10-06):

# Robust IO firmware design

Target: ATmega1284P-AU on Robust IO rev A, 3.3 V, 12 MHz crystal (Y2).
Toolchain: avr-gcc, avr-libc, avrdude, one Makefile. C11, no RTOS, no Arduino core.

Status: bring-up build written. It compiles without warnings (avr-gcc 7.3). In simavr, with console input and the sense voltage injected, the console, selftest, software trip and device-fault paths behave as designed; the SPI devices are not simulated. Nothing has run on hardware.

## 1. Goals

1. Prove every subsystem of rev A from a UART console on J20.
2. Use the same drivers for the application, so bring-up code is not thrown away.
3. Fail to a safe state: all outputs off, both motor drivers asleep.

## 2. Pin map

Taken from the rev A netlist (U2 pad nets). The same map is in `src/board.h`.

| Port | Pin | Net | Direction | Function |
|---|---|---|---|---|
| PA0 | 37 | AMUX0 | analog in, ADC0 | MC33978 analog mux output, through 1k, clamped to 3.3 V |
| PA1 | 36 | ISENSE (filtered) | analog in, ADC1 | BTS7008 current sense, shared by all four devices |
| PA2 | 35 | IPROPIM0 | analog in, ADC2 | Motor 0 current, 1.5 V per amp |
| PA3 | 34 | IPROPIM1 | analog in, ADC3 | Motor 1 current, 1.5 V per amp |
| PA4 | 33 | DEN2 | out | Diagnosis enable, U9 (outputs 4, 5) |
| PA5 | 32 | DEN3 | out | Diagnosis enable, U10 (outputs 6, 7) |
| PA6 | 31 | DSELn | out | Sense channel select, shared by all four BTS7008 |
| PA7 | 30 | nSLEEPMn | out | DRV8876 sleep, shared, low = asleep |
| PB0 | 40 | CS_CAN | out | MCP2515 chip select, active low |
| PB1 | 41 | CS_IN0 | out | MC33978 chip select, active low |
| PB2 | 42 | INT_B0 | in, INT2 | MC33978 interrupt, active low, 10k pull-up |
| PB3 | 43 | DEN0 | out | Diagnosis enable, U11 (outputs 0, 1) |
| PB4 | 44 | DEN1 | out | Diagnosis enable, U8 (outputs 2, 3). Also SPI SS: must stay an output |
| PB5 | 1 | MOSI0 | out | SPI, also ISP |
| PB6 | 2 | MISO0 | in | SPI, also ISP |
| PB7 | 3 | SCLK0 | out | SPI, also ISP |
| PC0..PC7 | 19..26 | DRV_OUT0..7 | out | BTS7008 inputs through 4.7k, high = output on |
| PD0 | 9 | RX0 | in | UART0 from J20 pin 4 through 1k |
| PD1 | 10 | TX0 | out | UART0 to J20 pin 5 through 1k |
| PD2 | 11 | INT_CAN0 | in, INT0 | MCP2515 interrupt, active low |
| PD3 | 12 | FAULTMn | in, INT1 | DRV8876 fault, shared, active low, 10k pull-up |
| PD4 | 13 | PH_M0 | out | Motor 0 direction |
| PD5 | 14 | EN_M0 | out, OC1A | Motor 0 PWM |
| PD6 | 15 | PH_M1 | out | Motor 1 direction |
| PD7 | 16 | EN_M1 | out, OC2A | Motor 1 PWM |

Output numbering: DRV_OUTn drives OUT_n on J3 (0 to 3) and J5 (4 to 7).

| BTS7008 | DEN | DSELn low | DSELn high |
|---|---|---|---|
| U11 | DEN0 | OUT_0 | OUT_1 |
| U8 | DEN1 | OUT_2 | OUT_3 |
| U9 | DEN2 | OUT_4 | OUT_5 |
| U10 | DEN3 | OUT_6 | OUT_7 |

Only one DEN may be high at a time, because all four sense pins share R25 (750 ohm).

## 3. Hardware facts that shape the firmware

These come from the netlist and the device datasheets. Items marked CHECK are to be confirmed on hardware.

- **JTAG shares PC2 to PC5 with DRV_OUT2 to DRV_OUT5.** A factory-fresh ATmega1284P has the JTAGEN fuse programmed, which enables pull-ups on TCK, TMS and TDI (PC2, PC3, PC5). The BTS7008 inputs pull down with only 10 to 25 uA and switch between 0.8 V and 2.0 V, so a 20k to 50k pull-up to 3.3 V through the 4.7k series resistor will hold the input high: expect outputs 2, 3 and 5 to be ON on an unprogrammed chip. Program the fuses with JTAG disabled before any load is wired to J3 or J5. The firmware also sets JTD in MCUCR at start as a second guard.
- **CS_CAN has no pull-up.** During ISP the MCU pins are high impedance, so the MCP2515 chip select floats and the MCP2515 can drive MISO. If programming is unreliable, fit 10k from TP8 (CS_CAN) to TP1 (+3.3V); they are next to each other. The MC33978 CS_B has an internal pull-up to VDDQ (datasheet). Add a CS_CAN pull-up in rev B.
- **SPI bus is shared** by the MCP2515 (mode 0) and the MC33978 (32-bit frames, MSB first, up to 8 MHz, response returned in the following frame). The MC33978 datasheet says it latches MOSI on the rising edge, which is mode 0; `MC33978_SPI_MODE` in `board.h` is the switch if the SPI check (expects 0x123456) fails (CHECK). The SPI driver sets the mode per transaction. Clock is F_CPU/4 = 3 MHz.
- **ADC reference is AVCC (3.3 V).** AREF has only a capacitor.
- **ISENSE scaling:** I_load = V_adc / 750 ohm x kILIS. kILIS is 5400 typical: within 4 % at 5.5 A, 13.5 % at 1 A, 30 % at 100 mA. 3.3 V full scale is about 23 A, about 23 mA per count at 10 bits. The fault signal is a sense current of at least 4.4 mA, which is 3.3 V on R25, so a reading above 3.0 V means fault. With the output off, an open load gives 1.9 to 3.5 mA (1.4 to 2.6 V).
- **Motor current limit is set in hardware.** PMODE is tied low (PH/EN mode). VREF = 3.3 V x 16.2k / 26.2k = 2.04 V and IPROPI is 1.5k, so the DRV8876 regulates at about 1.36 A. Firmware reads current at 1.5 V per amp but cannot raise the limit.
- **nSLEEP and nFAULT are shared** between the two DRV8876. A fault cannot be attributed to one motor from the pin alone; the firmware uses the two IPROPI readings and the commanded state to decide.
- **SP0 to SP7 are configured as switch-to-ground.** SG pins are switch-to-ground only; SP pins are programmable as switch-to-ground or switch-to-battery. On rev A every input, SP included, has an indicator LED and 2.2k from +24V to the IC pin. In switch-to-battery mode that path sources about 8 mA into the pin with the switch open, more than the IC's sustain current sinks, so the input would read closed all the time. Switch-to-battery on an SP channel needs its LED removed (D14 to D17 for SP0 to SP3 on J9, D18 to D21 for SP4 to SP7 on J10). The MC33978 powers up with SP pins in switch-to-battery mode (datasheet), so the driver clears device configuration bits 7 to 0 before the first read.
- **Clocks:** MCU 12 MHz, MCP2515 16 MHz (Y1). 115200 baud at 12 MHz with U2X has 0.16 % error.
- **CAN termination** is SW1 (120 ohm). Not readable by firmware.

## 4. Fuses

| Fuse | Value | Meaning |
|---|---|---|
| low | 0xFF | External crystal 8 to 16 MHz, slowest start-up |
| high | 0xD9 | JTAG disabled, SPI programming enabled, no bootloader |
| extended | 0xFD | Brown-out at 2.7 V |

`make fuses` writes these.

### Programmer: Raspberry Pi over SPI

The Pi's GPIO is 3.3 V, so it connects to J1 with no level shifting. avrdude uses the `linuxspi` programmer. Build and flash can both run on the Pi, or the hex file can be built on the Mac and copied over.

| Pi header pin | Pi signal | J1 pin | Board net |
|---|---|---|---|
| 19 | GPIO10 MOSI | 4 | MOSI0 |
| 21 | GPIO9 MISO | 1 | MISO0 |
| 23 | GPIO11 SCLK | 3 | SCLK0 |
| 22 | GPIO25 | 5 | RST |
| 25 | GND | 6 | GND |
| - | - | 2 | +3.3V, leave unconnected |

- Power the board from its own supply before connecting, and share only ground. Do not join the Pi's 3.3 V to the board's 3.3 V.
- SPI must be enabled on the Pi (`dtparam=spi=on`), giving `/dev/spidev0.0`.
- Packages on the Pi: `avrdude` (version 7 or later), plus `gcc-avr` and `avr-libc` if building there.
- Port string: `-c linuxspi -P /dev/spidev0.0:/dev/gpiochip0:25`. On a Pi 5 the header GPIO chip is `gpiochip0` or `gpiochip4` depending on the kernel; `gpiodetect` shows which one is `pinctrl-rp1`.
- A new chip runs from its 1 MHz internal clock, so the first connection must be slow: `-b 100000`. After the fuses select the 12 MHz crystal, `-b 1000000` works.
- Keep the wires short (under about 15 cm).

The Pi's UART can also serve as the J20 console: Pi pin 8 (TXD) to J20 pin 4, Pi pin 10 (RXD) to J20 pin 5, ground to J20 pin 1.

## 5. Architecture

Single foreground loop plus short interrupt handlers. No dynamic memory.

    app        console commands, CAN protocol, output/motor state machines
    --------------------------------------------------------------------
    drivers    mc33978   mcp2515   hsd (BTS7008)   motor (DRV8876)
    --------------------------------------------------------------------
    hal        gpio   spi   uart   adc   tick   pwm   eeprom   wdt
    --------------------------------------------------------------------
    board.h    pin map, scaling constants, F_CPU

Rules:

- Only `hal/` touches AVR registers. Drivers call the HAL. This lets the drivers and the protocol code be compiled and unit-tested on the Mac.
- Interrupt handlers only move bytes or set flags: 1 ms tick (Timer0 CTC), UART RX and TX ring buffers, INT0/INT1/INT2 set "service me" flags. All SPI traffic happens in the foreground, so the bus needs no locking.
- Every module has `init()` and a non-blocking `task()` called from the main loop. No `_delay_ms()` after start-up.

Timers:

| Timer | Use |
|---|---|
| Timer0 | 1 ms system tick (CTC). OC0A/OC0B stay disconnected because PB3/PB4 are DEN0/DEN1 |
| Timer1 | Motor 0 PWM on OC1A, phase-correct 8-bit, 23.5 kHz |
| Timer2 | Motor 1 PWM on OC2A, phase-correct, 23.5 kHz |

Main loop schedule:

| Period | Task |
|---|---|
| every pass | UART console, CAN receive, interrupt flags |
| 1 ms | ADC sequencer step |
| 10 ms | Poll MC33978 inputs (also on INT_B0), debounce, output and motor state machines |
| 100 ms | Periodic CAN status frames, watchdog kick, heartbeat |

## 6. Drivers

**mc33978** - 22 switch inputs (SG0 to SG13, SP0 to SP7).
Init: read device ID, set SP pins as switch-to-ground or switch-to-battery, set wetting current and wetting timer, set thresholds, enable interrupts on change. Run time: read switch status (one 32-bit frame returns all 22 bits), select AMUX channel to read an input voltage, battery sense or die temperature on ADC0. Reports SPI error and over-temperature flags.

**mcp2515** - CAN controller.
Init: reset, set bit timing for the 16 MHz crystal (250 kbit/s default; 125k, 500k and 1M tables included), set filters, enter normal mode. Loopback mode is used for the self-test. Run time: receive from both buffers into a software queue, transmit from a software queue using the three TX buffers, track error counters and bus-off, recover from bus-off after a delay.

**hsd** - eight high-side outputs.
On/off only. PWM is provided on the motor drivers, not on these outputs.
Per channel: commanded state, measured current, status (off, on, overcurrent, open load, fault). The ADC sequencer raises one DEN, sets DSELn, waits for the sense output to settle (datasheet worst case 0.4 ms at small load; the design uses 2 ms), samples ADC1, then moves to the next channel. A full scan of eight channels takes about 20 ms. Software overcurrent trip per channel with configurable limit and time, latched until cleared by command. The BTS7008's own protection remains the backstop.

**motor** - two DRV8876 in PH/EN mode.
Signed duty command, slew-rate limited. nSLEEP is raised when either motor is commanded and dropped when both have been idle for a set time. Fault handling: on FAULTMn low, stop both, record currents, pulse nSLEEP to clear, report.

## 7. Safe state and fault handling

Safe state = DRV_OUT0..7 low, EN_M0/EN_M1 low, nSLEEPMn low.

Entered on:

- Reset, before anything else runs (ports are set in `.init3`, before C start-up).
- Watchdog reset (250 ms watchdog, kicked only from the main loop when all tasks have run).
- Brown-out.
- Loss of host: no valid command frame for the configured timeout (default 500 ms, 0 disables).
- MC33978 or MCP2515 failing its ID check or reporting an SPI fault.

The reset cause (MCUSR) is saved at start and reported on the console and on CAN.

## 8. Console (UART0, 115200 8N1)

Line-based text commands, used for bring-up and service.

    help
    ver                       firmware version, reset cause
    in                        22 input bits, raw and debounced
    in watch                  print on change
    amux <ch>                 MC33978 analog channel in mV
    out <0-7> <0|1>           switch one output
    out all 0                 all outputs off
    isense                    eight channel currents in mA and status
    motor <0|1> <-100..100>   signed duty in percent
    motor stat                currents, fault, sleep state
    can stat                  mode, error counters, rx/tx counts
    can loop                  loopback self-test
    can tx <id> <bytes...>    send a frame
    cfg show | set <k> <v> | save
    out clear                 clear latched trips and faults
    limit <0-7|all> <mA> [ms] software trip level and time
    selftest                  checks that switch nothing on: SPI devices, CAN loopback,
                              outputs quiet, motor drivers idle
    selftest out              also pulses each output for 200 ms
    selftest motor            also runs each motor at 20 % both ways
    reset

## 9. CAN protocol (proposal)

Standard 11-bit IDs, 250 kbit/s, node number N (0 to 15) stored in EEPROM.

| ID | Dir | Period | Data |
|---|---|---|---|
| 0x100 + N | out | on change and 100 ms | Inputs: 3 bytes, bit n = input n, then 1 byte status |
| 0x110 + N | out | 100 ms | Outputs: commanded mask, on mask, fault mask, open-load mask |
| 0x120 + N | out | 100 ms | Output currents: 8 bytes, 100 mA per count |
| 0x130 + N | out | 100 ms | Motors: duty 0, duty 1, current 0, current 1 (10 mA per count), flags |
| 0x140 + N | out | 1 s | Heartbeat: state, reset cause, firmware version, error count |
| 0x200 + N | in | - | Set outputs: mask, value |
| 0x210 + N | in | - | Set motors: signed duty 0, signed duty 1 |
| 0x220 + N | in | - | Clear faults: output mask, motor flag |
| 0x230 + N | in | - | Config read/write: key, value |

Any valid 0x200 or 0x210 frame restarts the host timeout.

## 10. Configuration (EEPROM)

One struct with a version byte and CRC16: node number, CAN bit rate, host timeout, input debounce time, SP pin mode, wetting current, per-output current limit and trip time, motor slew rate. Defaults are used if the CRC fails.

## 11. Layout and build

    firmware/
      Makefile
      DESIGN.md
      src/
        board.h
        main.c
        hal/      gpio.h spi.c uart.c adc.c tick.c pwm.c eeprom.c wdt.c
        drivers/  mc33978.c mcp2515.c hsd.c motor.c
        app/      console.c canproto.c config.c selftest.c
      test/       host-built unit tests for drivers and protocol

Make targets: `all`, `flash`, `fuses`, `size`, `clean`, `test`. The programmer settings are Makefile variables (`PROGRAMMER`, `PORT`, `BITCLOCK`), defaulting to the Raspberry Pi `linuxspi` setup above.

## 11a. What is implemented

| Area | State |
|---|---|
| Safe-state start-up, reset cause, watchdog, JTAG disable | done |
| HAL: tick, UART (interrupt driven), SPI, ADC | done |
| MC33978: SPI check, SP mode, read inputs, raw register read | done |
| MCP2515: reset, bit timing, modes, send, receive, status | done |
| High-side outputs: on/off, background sense scan (about 25 ms for 8 channels) | done |
| Output protection: software trip (default 5 A for 100 ms), device fault detection, latched until `out clear` | done |
| Motors: PWM, direction, sleep, fault pin, current | done |
| Console: ver, in, amux, out, isense, limit, motor, can, selftest, reset | done |
| Motor fault handling (stop, record, clear) | not started |
| CAN protocol, host timeout, EEPROM configuration | not started |
| MC33978 wetting current, thresholds, interrupts, AMUX select | not started |
| selftest command | done |
| Host unit tests | not started |

## 12. Bring-up sequence

Each step is one console command and is what `selftest` automates.

1. Fuses, then flash. Heartbeat line appears on J20.
2. `ver` shows the reset cause as power-on.
3. `in`: MC33978 ID reads correctly; shorting an input to ground changes its bit.
4. `can loop` passes; then `can tx` is seen by a second node with SW1 set as needed.
5. `out n 1` with a resistive load on each output in turn; `isense` matches a meter.
6. `motor 0 20`, `motor 0 -20`, same for motor 1; `motor stat` current matches a meter.
7. Remove the host: outputs drop after the timeout.

## 13. Open questions

None blocking. Decisions taken as defaults, all changeable in configuration:

- CAN runs at 250 kbit/s with the IDs in section 9. No existing bus is assumed.
- SP0 to SP7 are switch-to-ground.
- The high-side outputs are on/off only; PWM is on the motor drivers.
- The programmer is a Raspberry Pi over SPI.

To confirm on hardware:

- MC33978 SPI mode (see section 3).
- Which of each BTS7008's two channels reaches which connector pin. The firmware assumes DRV_OUTn switches OUT_n; `out n 1` at bring-up confirms it, and a swap within a pair is a one-line table change.
- The layout of the MC33978 device configuration register above bit 7. The driver reads the register and writes it back with only bits 7 to 0 cleared.

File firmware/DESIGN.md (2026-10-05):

# Robust IO firmware design

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

Status: design only. Nothing here has run on hardware.

## 1. Goals

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

## 2. Pin map

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

Output numbering: DRV_OUTn drives OUT_n on J3 (0 to 3) and J5 (4 to 7).

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

## 3. Hardware facts that shape the firmware

These come from the netlist. Items marked CHECK need the datasheet value confirmed before the constant is trusted.

- **JTAG shares PC2 to PC5 with DRV_OUT2 to DRV_OUT5.** A factory-fresh ATmega1284P has the JTAGEN fuse programmed, which enables pull-ups on TCK, TMS and TDI (PC2, PC3, PC5). Through the 4.7k series resistors these may be enough to switch outputs 2, 3 and 5 on. Program the fuses with JTAG disabled before any load is wired to J3 or J5. The firmware also sets JTD in MCUCR at start as a second guard.
- **CS_CAN has no pull-up.** During ISP the MCU pins are high impedance, so the MCP2515 chip select floats and the MCP2515 can drive MISO. If programming is unreliable, fit 10k from TP8 (CS_CAN) to TP1 (+3.3V); they are next to each other. The MC33978 CS_B has an internal pull-up (CHECK). Add both pull-ups in rev B.
- **SPI bus is shared** by the MCP2515 (mode 0) and the MC33978 (mode 1, 32-bit frames, CHECK). The SPI driver sets the mode per transaction. Clock is F_CPU/4 = 3 MHz.
- **ADC reference is AVCC (3.3 V).** AREF has only a capacitor.
- **ISENSE scaling:** I_load = V_adc / 750 ohm x kILIS. kILIS for the BTS7008-2EPA is about 5400 (CHECK). 3.3 V full scale is about 23 A, about 23 mA per count at 10 bits. A reading near full scale with the output commanded on is the device's fault signal.
- **Motor current limit is set in hardware.** PMODE is tied low (PH/EN mode). VREF = 3.3 V x 16.2k / 26.2k = 2.04 V and IPROPI is 1.5k, so the DRV8876 regulates at about 1.36 A. Firmware reads current at 1.5 V per amp but cannot raise the limit.
- **nSLEEP and nFAULT are shared** between the two DRV8876. A fault cannot be attributed to one motor from the pin alone; the firmware uses the two IPROPI readings and the commanded state to decide.
- **SP0 to SP7 are configured as switch-to-ground.** SG pins are switch-to-ground only; SP pins are programmable as switch-to-ground or switch-to-battery. On rev A every input, SP included, has an indicator LED and 2.2k from +24V to the IC pin. In switch-to-battery mode that path sources about 8 mA into the pin with the switch open, more than the IC's sustain current sinks, so the input would read closed all the time. Switch-to-battery on an SP channel needs its LED removed (D14 to D17 for SP0 to SP3 on J9, D18 to D21 for SP4 to SP7 on J10). The MC33978 powers up with SP pins in switch-to-battery mode (CHECK), so the driver must write the configuration before the first read.
- **Clocks:** MCU 12 MHz, MCP2515 16 MHz (Y1). 115200 baud at 12 MHz with U2X has 0.16 % error.
- **CAN termination** is SW1 (120 ohm). Not readable by firmware.

## 4. Fuses

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

`make fuses` writes these.

### Programmer: Raspberry Pi over SPI

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

## 5. Architecture

Single foreground loop plus short interrupt handlers. No dynamic memory.

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

Rules:

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

Timers:

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

Main loop schedule:

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

## 6. Drivers

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

**hsd** - eight high-side outputs.
On/off only. PWM is provided on the motor drivers, not on these outputs.
Per channel: commanded state, measured current, status (off, on, overcurrent, open load, fault). The ADC sequencer raises one DEN, sets DSELn, waits for the sense output to settle (CHECK, a few hundred microseconds; the design uses 2 ms), samples ADC1, then moves to the next channel. A full scan of eight channels takes about 20 ms. Software overcurrent trip per channel with configurable limit and time, latched until cleared by command. The BTS7008's own protection remains the backstop.

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

## 7. Safe state and fault handling

Safe state = DRV_OUT0..7 low, EN_M0/EN_M1 low, nSLEEPMn low.

Entered on:

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

The reset cause (MCUSR) is saved at start and reported on the console and on CAN.

## 8. Console (UART0, 115200 8N1)

Line-based text commands, used for bring-up and service.

    help
    ver                       firmware version, reset cause
    in                        22 input bits, raw and debounced
    in watch                  print on change
    amux <ch>                 MC33978 analog channel in mV
    out <0-7> <0|1>           switch one output
    out all 0                 all outputs off
    isense                    eight channel currents in mA and status
    motor <0|1> <-100..100>   signed duty in percent
    motor stat                currents, fault, sleep state
    can stat                  mode, error counters, rx/tx counts
    can loop                  loopback self-test
    can tx <id> <bytes...>    send a frame
    cfg show | set <k> <v> | save
    selftest                  runs the bring-up sequence and prints pass/fail per step
    reset

## 9. CAN protocol (proposal)

Standard 11-bit IDs, 250 kbit/s, node number N (0 to 15) stored in EEPROM.

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

Any valid 0x200 or 0x210 frame restarts the host timeout.

## 10. Configuration (EEPROM)

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

## 11. Layout and build

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

## 12. Bring-up sequence

Each step is one console command and is what `selftest` automates.

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

## 13. Open questions

- CAN bit rate and whether the IDs above must fit an existing bus.

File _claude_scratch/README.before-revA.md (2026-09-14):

# Robust IO

A rugged industrial I/O board designed in KiCad.

## Status

- **Schematic:** Complete across four hierarchical sheets — power regulation,
  ATmega1284P processor/CAN interface, multi-switch input detection, and
  high-side/motor-driver outputs.
- **PCB layout:** All footprints placed; routing in progress (not yet complete).

## Architecture

| Sheet | Contents |
|---|---|
| `power` | TPS5604 regulation, inductors, input fusing/protection |
| `processor` | ATmega1284P MCU, MCP2515 + MCP2562 (CAN), crystal, ISP header |
| `inputs` | MC33978 multi-switch detect, protected/fused input channels |
| `outputs2` | BTS7008 high-side switches, DRV8876 motor drivers, TC4427 gate drivers |

## Files

- `robust-io.kicad_pro` — project file
- `robust-io.kicad_sch` — root/hierarchical sheet
- `power.kicad_sch`, `processor.kicad_sch`, `inputs.kicad_sch`, `outputs2.kicad_sch` — schematic sheets
- `robust-io.kicad_pcb` — PCB layout

## License

See [LICENSE](LICENSE). Free for personal, educational, and open-source use.
For commercial licensing, contact ryan.lush@gmail.com.

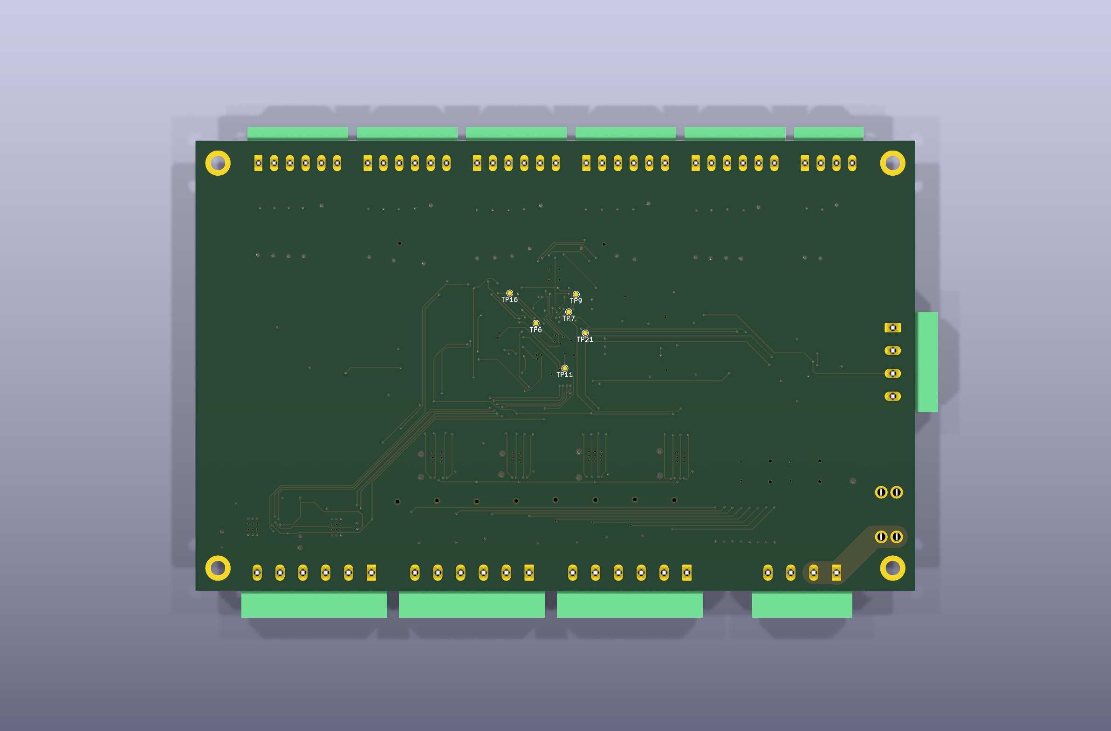
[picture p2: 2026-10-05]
docs/board-bottom.png

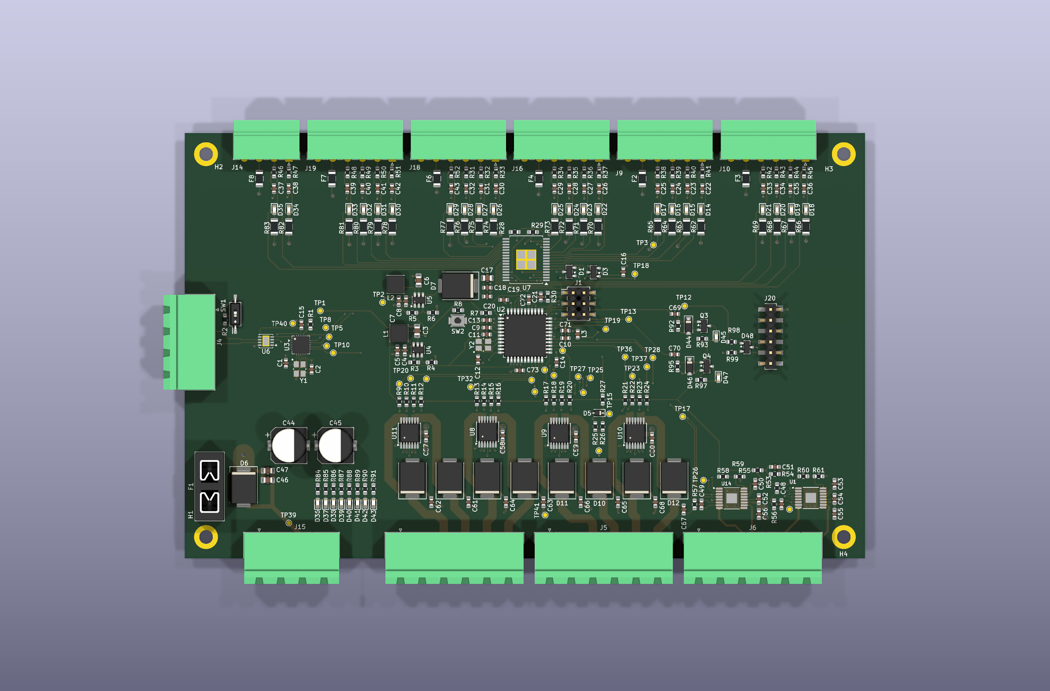
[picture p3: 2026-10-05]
docs/board-top.png

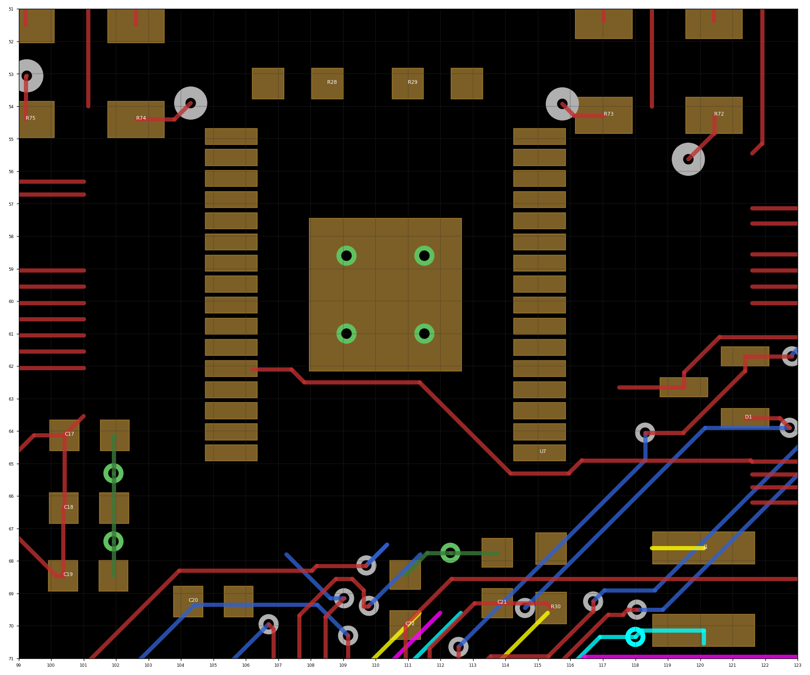
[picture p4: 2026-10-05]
_claude_scratch/u7r8.png

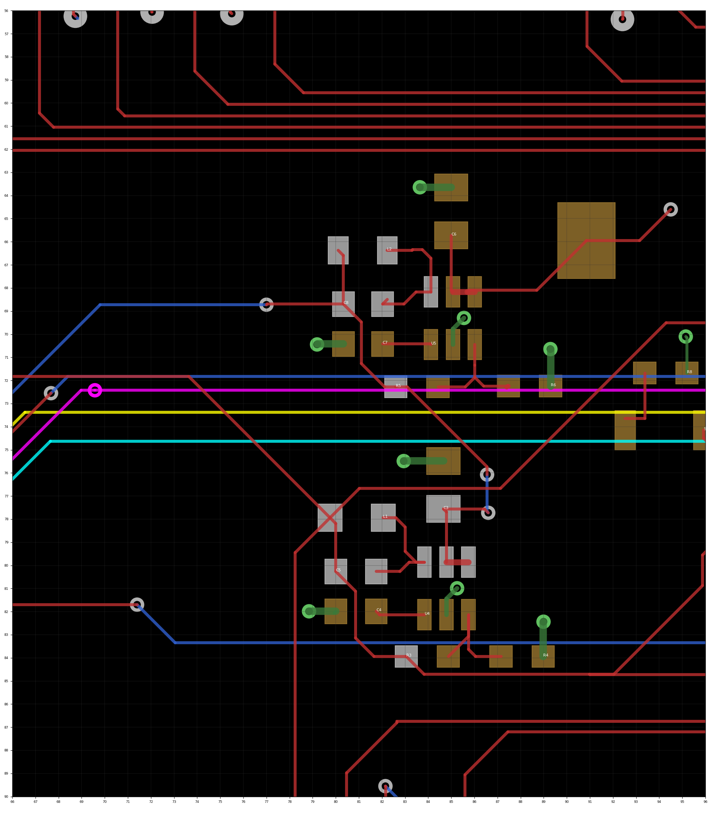
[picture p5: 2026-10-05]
_claude_scratch/buck_region.png

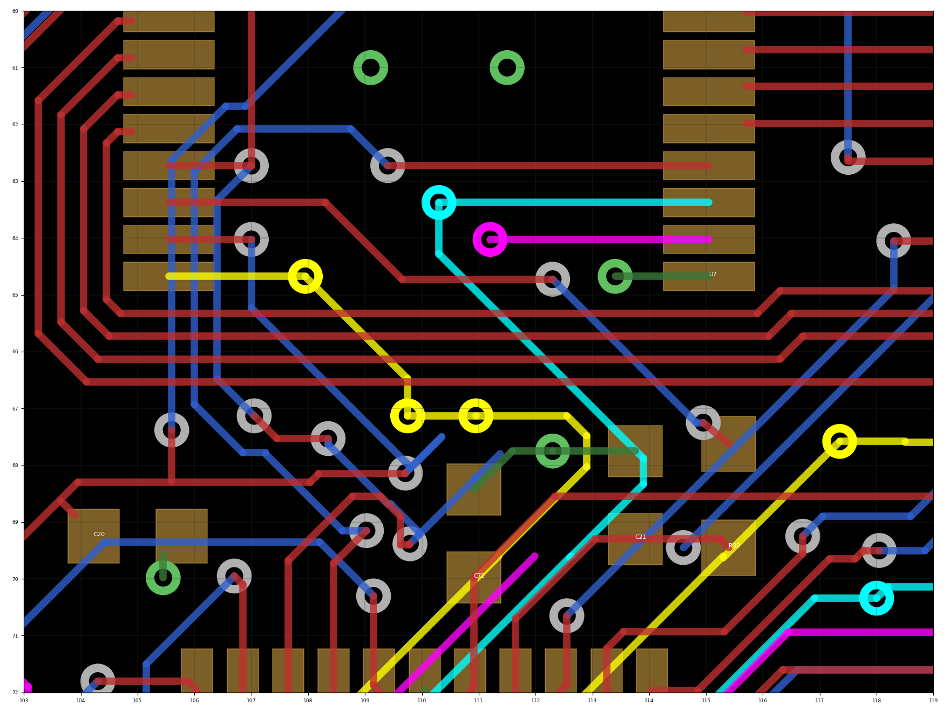
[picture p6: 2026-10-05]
_claude_scratch/u7r12.png

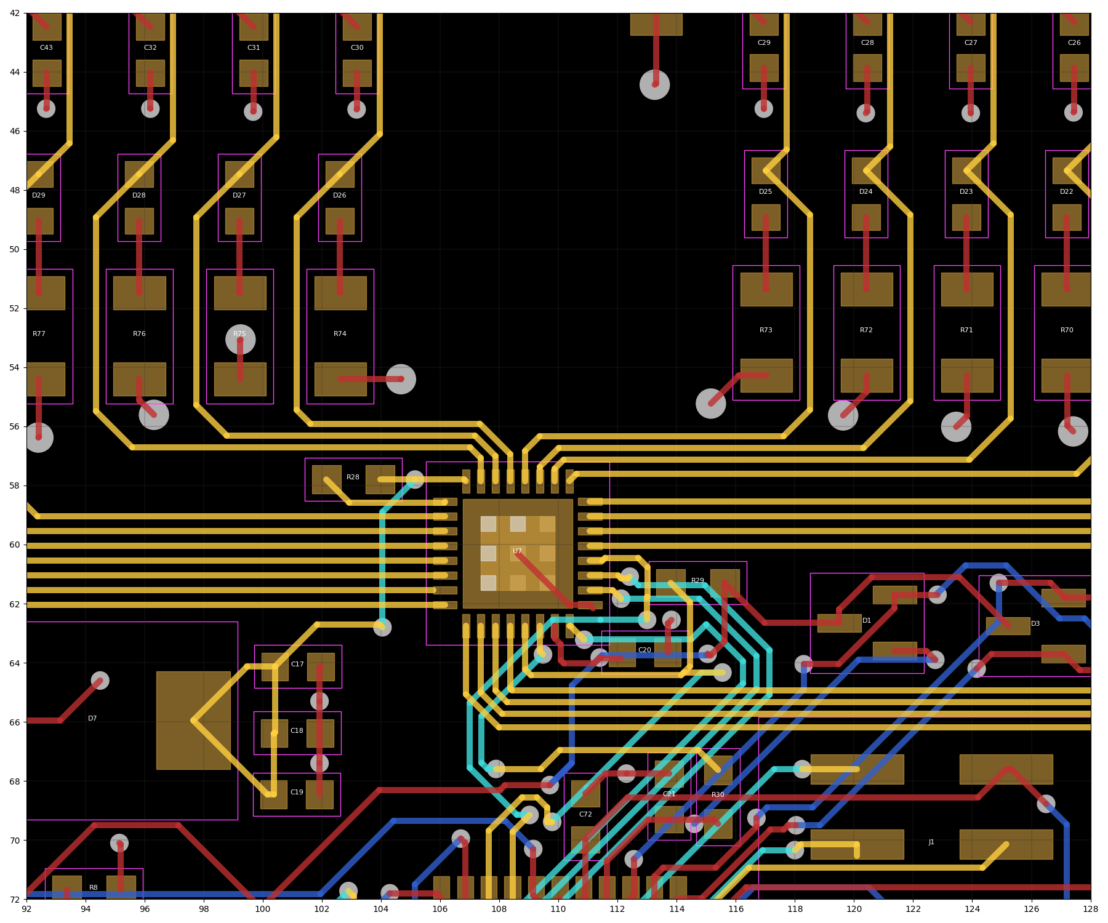
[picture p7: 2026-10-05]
_claude_scratch/u7area.png

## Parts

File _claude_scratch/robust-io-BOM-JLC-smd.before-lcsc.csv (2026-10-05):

Comment | Designator | Footprint | LCSC Part #
22pF | C1,C2,C11,C12 | C_0603_1608Metric | C1653
2.2uF 50V | C3,C6,C46 | C_0805_2012Metric | C377773
100nF 50V | C4,C7,C9,C10,C13,C14,C15,C18,C20,C21,C22,C23,C24,C25,C26,C27,C28,C29,C30,C31,C32,C33,C34,C35,C36,C37,C38,C39,C40,C41,C42,C43,C48,C49,C51,C52,C54,C55,C56,C57,C58,C59,C60,C61,C62,C63,C64,C65,C66,C67,C68,C71,C72,C73 | C_0603_1608Metric | C14663
22uF | C5,C8 | C_0603_1608Metric
1nF | C16,C19 | C_0603_1608Metric | C1588
10uF 50V | C17 | C_0805_2012Metric | C440198
100uF 50V | C44,C45 | CP_Elec_8x10
100nF 50V | C47 | C_0805_2012Metric
22nF | C50,C53 | C_0603_1608Metric | C21122
10nF | C69,C70 | C_0603_1608Metric | C57112
BAT54C | D1,D3 | SOT-23
B560C | D2,D4,D8,D9,D10,D11,D12,D13 | D_SMC
BZX384C6V8 | D5 | D_SOD-323
SMDJ24A | D6 | D_SMC
B340 | D7 | D_SMC
LED | D14,D15,D16,D17,D18,D19,D20,D21,D22,D23,D24,D25,D26,D27,D28,D29,D30,D31,D32,D33,D34,D35,D36,D37,D38,D39,D40,D41,D42,D43,D45,D47 | LED_0603_1608Metric
1N4148W | D44,D46 | D_SOD-123
SP0502BAHT | D48 | SOT-23
Polyfuse | F2,F3,F4,F6,F7,F8 | Fuse_1206_3216Metric
AVR-ISP-6 | J1 | PinHeader_2x03_P2.54mm_Vertical_SMD
6.8uH | L1 | L_0805_2012Metric
18uH | L2 | L_0805_2012Metric
10uH | L3 | C_0603_1608Metric
2N7002 | Q3,Q4 | SOT-23
10k | R1,R7,R28,R29,R53 | R_0603_1608Metric
120 | R2 | R_0603_1608Metric
51k | R3 | R_0603_1608Metric
22.1k | R4,R6 | R_0603_1608Metric
88.7k | R5 | R_0603_1608Metric
330 | R8,R93,R97 | R_0603_1608Metric
4.7k | R9,R10,R11,R12,R13,R14,R15,R16,R17,R18,R19,R20,R21,R22,R23,R24,R26,R27 | R_0603_1608Metric
750 | R25 | R_0603_1608Metric
1k | R30,R98,R99 | R_0603_1608Metric
100 | R31,R32,R33,R34,R35,R36,R37,R38,R39,R40,R41,R42,R43,R44,R45,R46,R47,R48,R49,R50,R51,R52 | R_0603_1608Metric
16.2k 1% | R54 | R_0603_1608Metric
10k 1% | R55 | R_0603_1608Metric
1.5k 1% | R56,R57 | R_0603_1608Metric
0 | R59,R61 | R_0603_1608Metric
2.2k | R62,R63,R64,R65,R66,R67,R68,R69,R70,R71,R72,R73,R74,R75,R76,R77,R78,R79,R80,R81,R82,R83 | R_1206_3216Metric
2.2k | R84,R85,R86,R87,R88,R89,R90,R91 | R_0603_1608Metric
100k | R92,R95 | R_0603_1608Metric
CHS-01TB | SW1 | SW_DIP_SPSTx01_Slide_Copal_CHS-01B_W7.62mm_P1.27mm
B3U-1000P | SW2 | SW_SPST_B3U-1000P
DRV8876 | U1,U14 | IC_DRV8876PWPR
ATmega1284P-A | U2 | TQFP-44_10x10mm_P0.8mm
MCP2515 | U3 | QFN-20-1EP_4x4mm_P0.5mm_EP2.5x2.5mm
TPS5604 | U4,U5 | SOT-23-6
MCP2562-E-MF | U6 | DFN-8-1EP_3x3mm_P0.65mm_EP1.6x2.56mm
MC33978 | U7 | HSOP-32-1EP_7.5x11mm_P0.65mm_EP4.7x4.7mm
BTS7008 | U8,U9,U10,U11 | TSSOP-14-1EP_4.4x5mm_P0.65mm
16MHz | Y1 | WE-XTAL_CFPX-180
12MHz | Y2 | WE-XTAL_CFPX-180

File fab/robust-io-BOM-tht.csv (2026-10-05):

Comment | Designator | Footprint | LCSC Part #
10-20A | F1 | Fuseholder_Blade_Mini_Keystone_3568
Screw_Terminal_01x06 | J3,J5,J6 | PhoenixContact_MSTBA_2,5_6-G-5,08_1x06_P5.08mm_Horizontal
Screw_Terminal_01x04 | J4,J15 | PhoenixContact_MSTBA_2,5_4-G-5,08_1x04_P5.08mm_Horizontal
Screw_Terminal_01x06 | J9,J10,J16,J18,J19 | PhoenixContact_MC_1,5_6-G-3.5_1x06_P3.50mm_Horizontal
Screw_Terminal_01x04 | J14 | PhoenixContact_MC_1,5_4-G-3.5_1x04_P3.50mm_Horizontal

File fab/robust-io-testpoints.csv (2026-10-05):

Test point | Net | Side | X from left edge (mm) | Y from top edge (mm) | Silkscreen label
TP1 | +3.3V | Top | 31.89 | 41.83 | yes
TP2 | +5V | Top | 46.54 | 39.83 | yes
TP3 | +24V | Top | 110.25 | 26.35 | yes
TP4 | SCLK0 | Top | 33.38 | 50.08 | no
TP5 | MOSI0 | Top | 33.94 | 47.95 | yes
TP6 | MISO0 | Bottom | 84.31 | 40.59 | yes
TP7 | CS_IN0 | Bottom | 77.03 | 38.05 | yes
TP8 | CS_CAN | Top | 33.19 | 45.76 | yes
TP9 | INT_B0 | Bottom | 75.36 | 34.17 | yes
TP10 | INT_CAN0 | Top | 34.94 | 51.70 | yes
TP11 | RST | Bottom | 77.90 | 50.58 | yes
TP12 | RX0 | Top | 117.56 | 40.70 | yes
TP13 | TX0 | Top | 104.43 | 43.83 | yes
TP14 | ISENSE | Top | 97.39 | 74.72 | no
TP15 | ISENSE_PROT | Top | 99.90 | 66.03 | yes
TP16 | AMUX0 | Bottom | 90.15 | 33.90 | yes
TP17 | IPROPIM0 | Top | 117.12 | 66.69 | yes
TP18 | IPROPIM1 | Top | 105.85 | 33.14 | yes
TP19 | DSELn | Top | 99.04 | 46.13 | yes
TP20 | DEN0 | Top | 53.12 | 57.72 | yes
TP21 | DEN1 | Bottom | 73.35 | 42.75 | yes
TP22 | DEN2 | Top | 86.84 | 56.99 | no
TP23 | DEN3 | Top | 105.29 | 57.17 | yes
TP24 | EN_M0 | Top | 93.75 | 61.05 | no
TP25 | EN_M1 | Top | 95.42 | 57.59 | yes
TP26 | PH_M0 | Top | 122.00 | 81.65 | yes
TP27 | PH_M1 | Top | 92.54 | 57.29 | yes
TP28 | nSLEEPMn | Top | 110.10 | 52.83 | yes
TP29 | FAULTMn | Top | 82.33 | 60.83 | no
TP30 | DRV_OUT0 | Top | 50.47 | 58.98 | no
TP31 | DRV_OUT1 | Top | 56.83 | 57.82 | no
TP32 | DRV_OUT2 | Top | 67.23 | 59.71 | yes
TP33 | DRV_OUT3 | Top | 81.60 | 58.10 | no
TP34 | DRV_OUT4 | Top | 84.64 | 55.72 | no
TP35 | DRV_OUT5 | Top | 88.87 | 51.17 | no
TP36 | DRV_OUT6 | Top | 103.58 | 52.68 | yes
TP37 | DRV_OUT7 | Top | 108.68 | 54.98 | yes
TP38 | GND | Top | 142.27 | 88.48 | no
TP39 | GND | Top | 24.49 | 91.69 | yes
TP40 | GND | Top | 25.42 | 44.76 | yes
TP41 | GND | Top | 84.77 | 89.84 | yes

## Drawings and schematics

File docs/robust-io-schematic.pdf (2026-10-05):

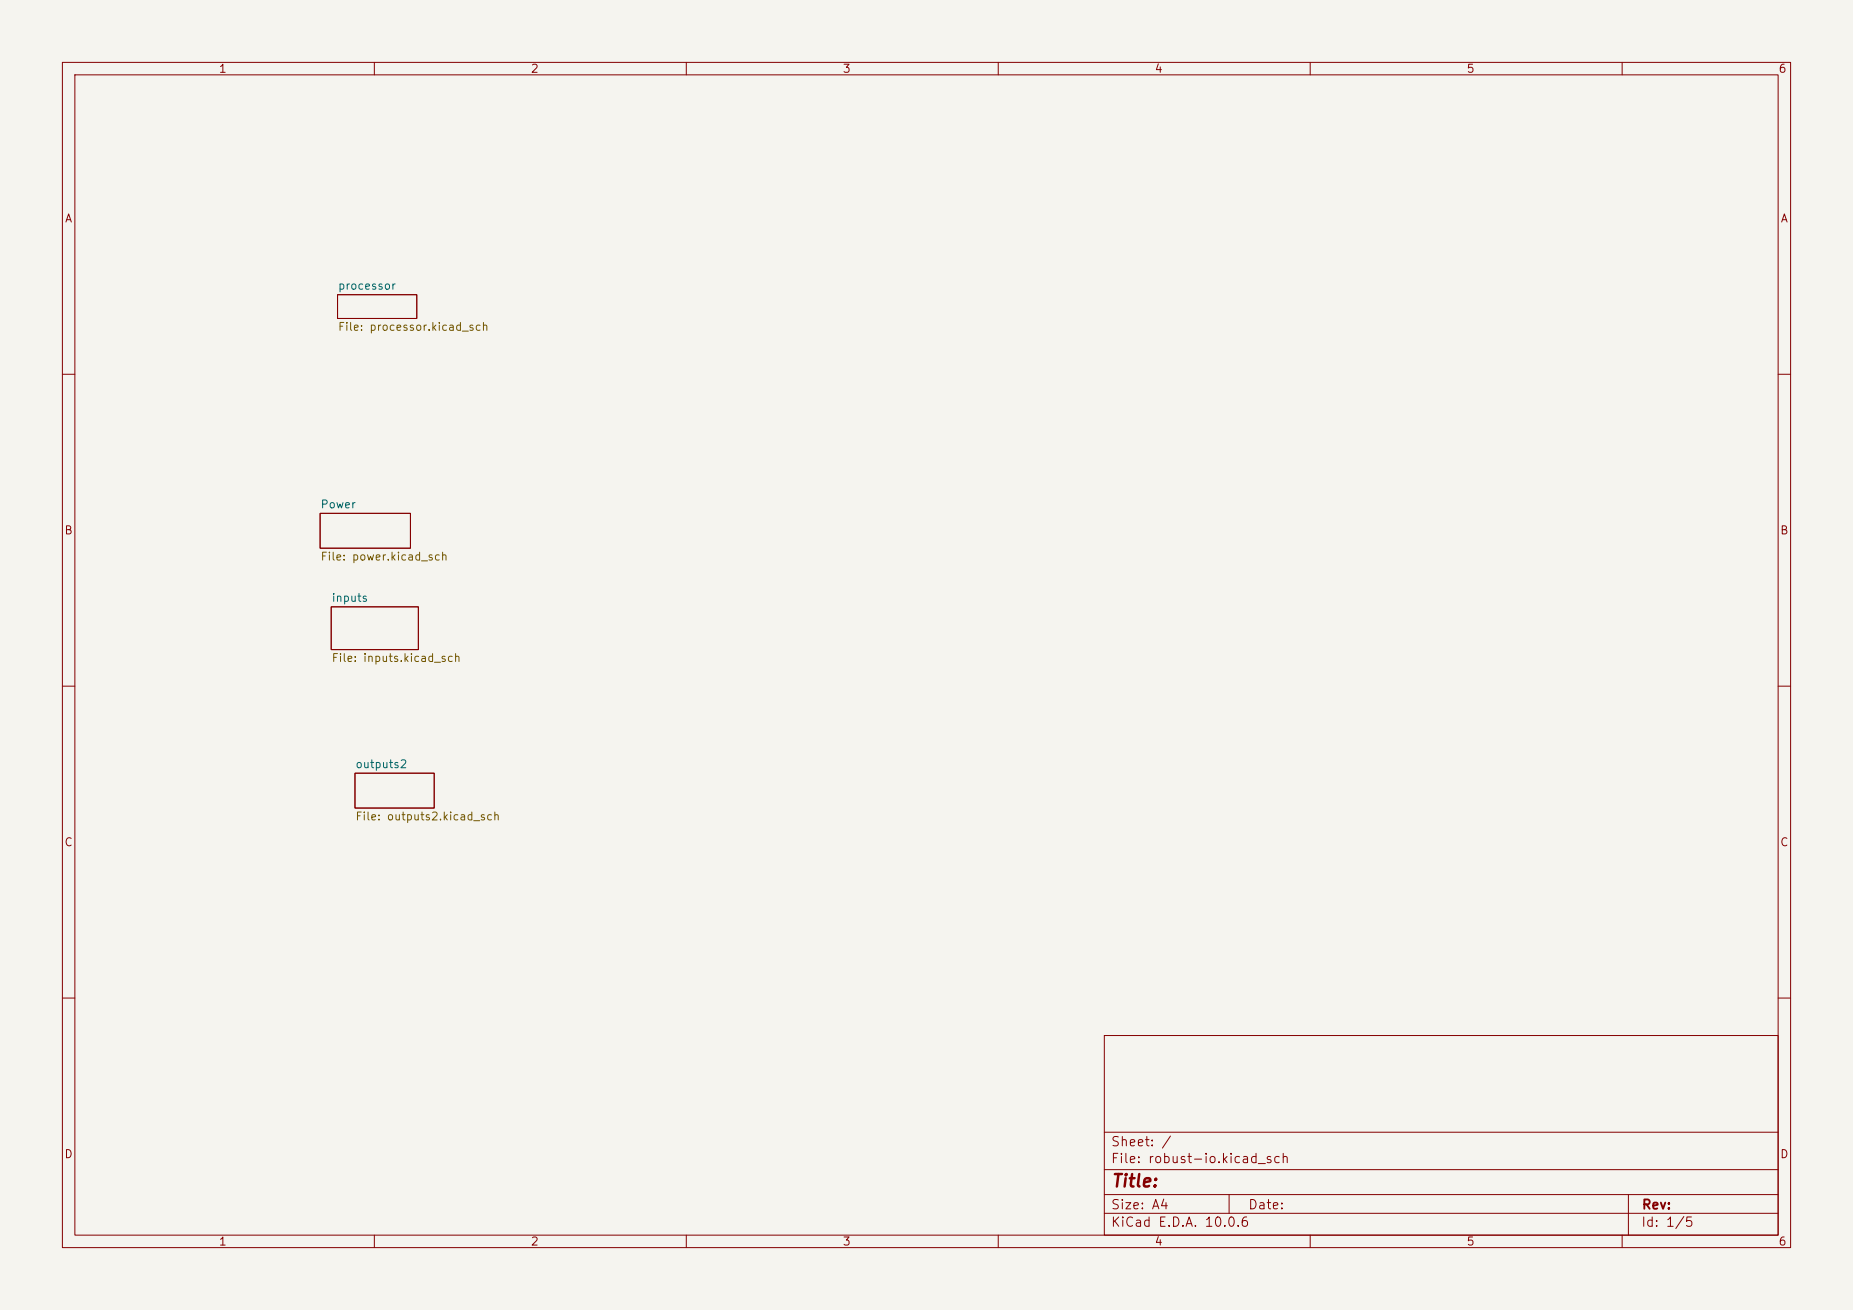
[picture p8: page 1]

inputs File: inputs.kicad_sch Power File: power.kicad_sch

Size: A4 | Rev:
KiCad E.D.A. 10.0.6 | Id: 1/5

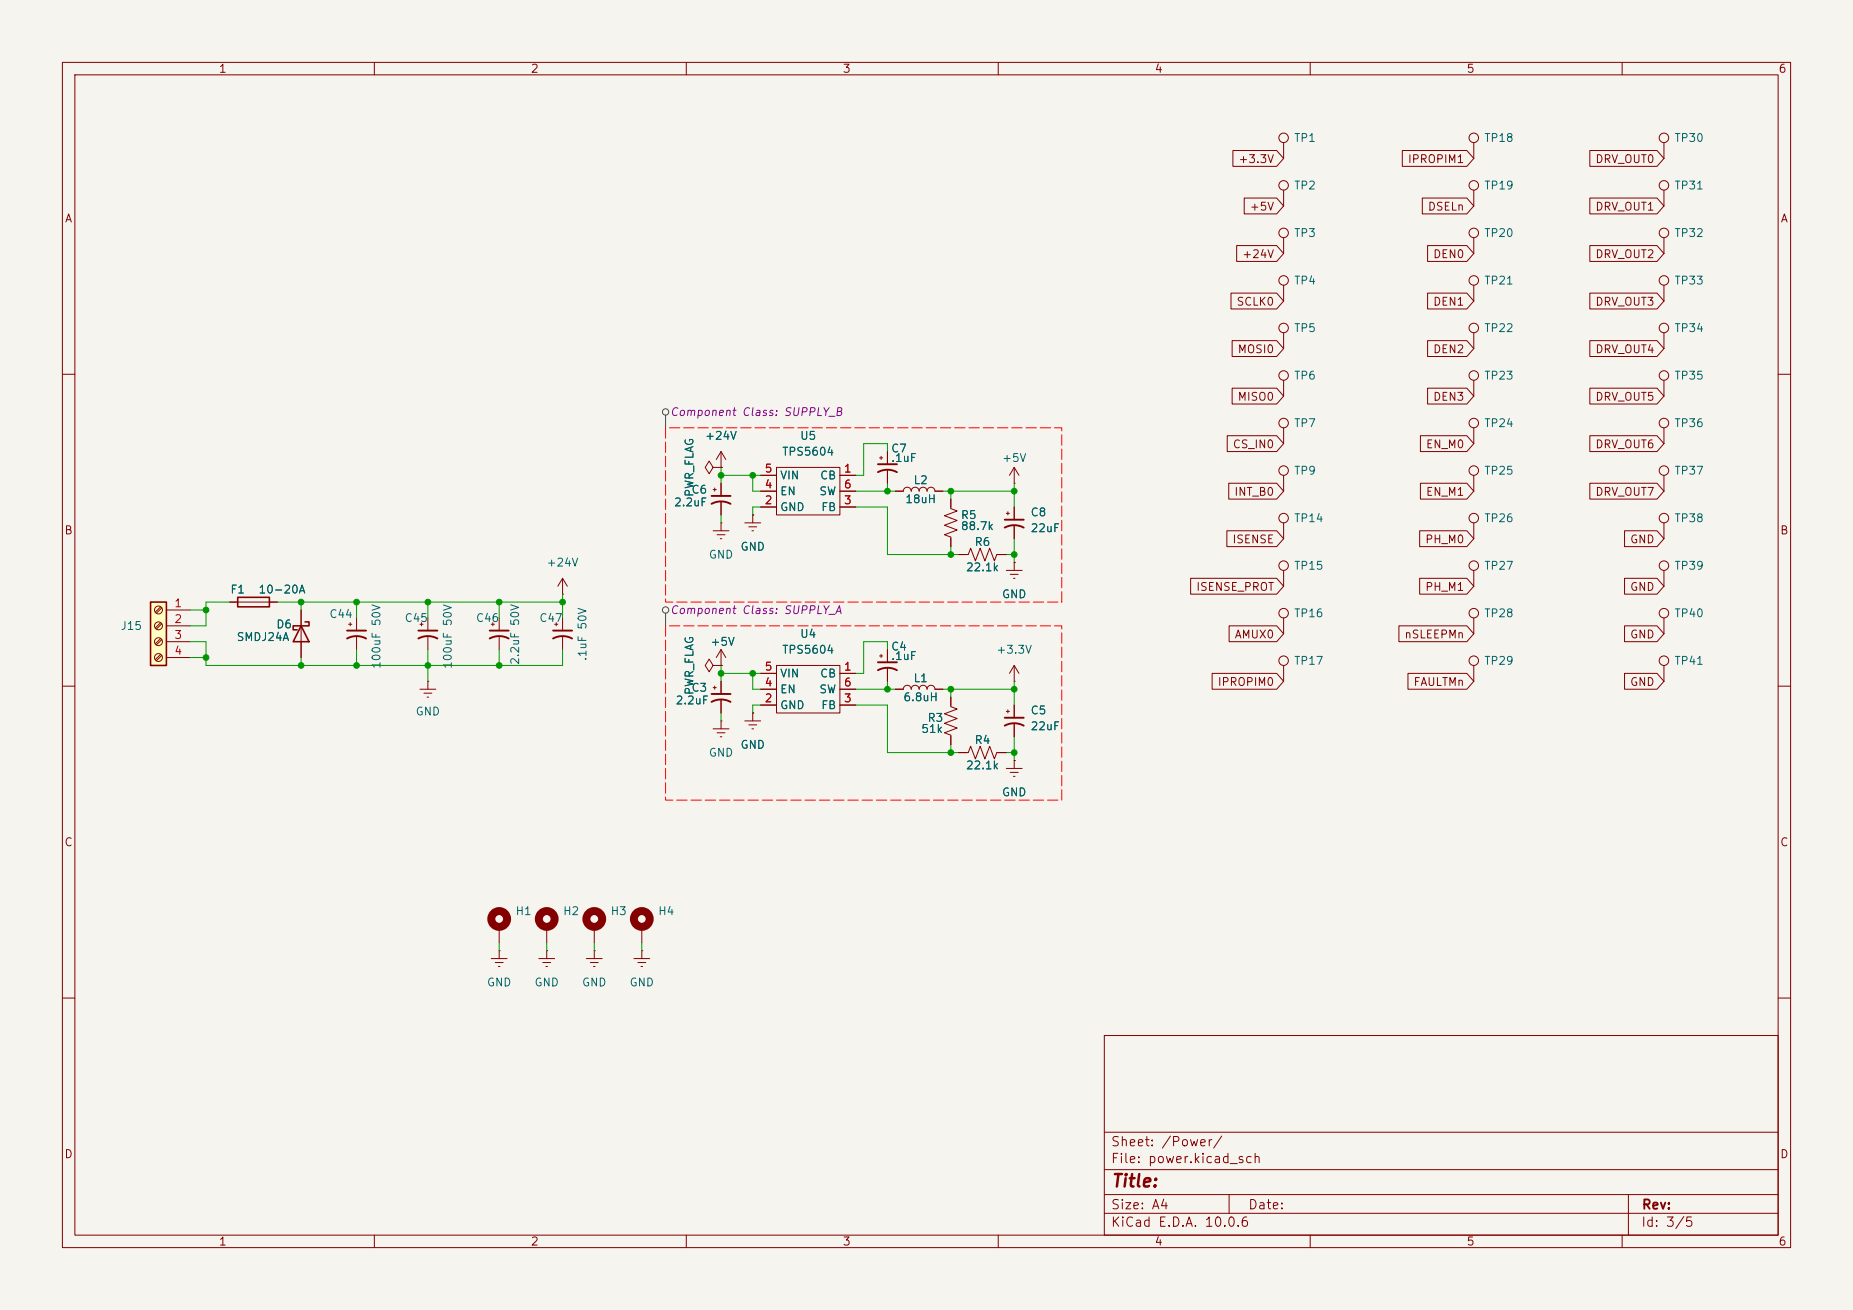
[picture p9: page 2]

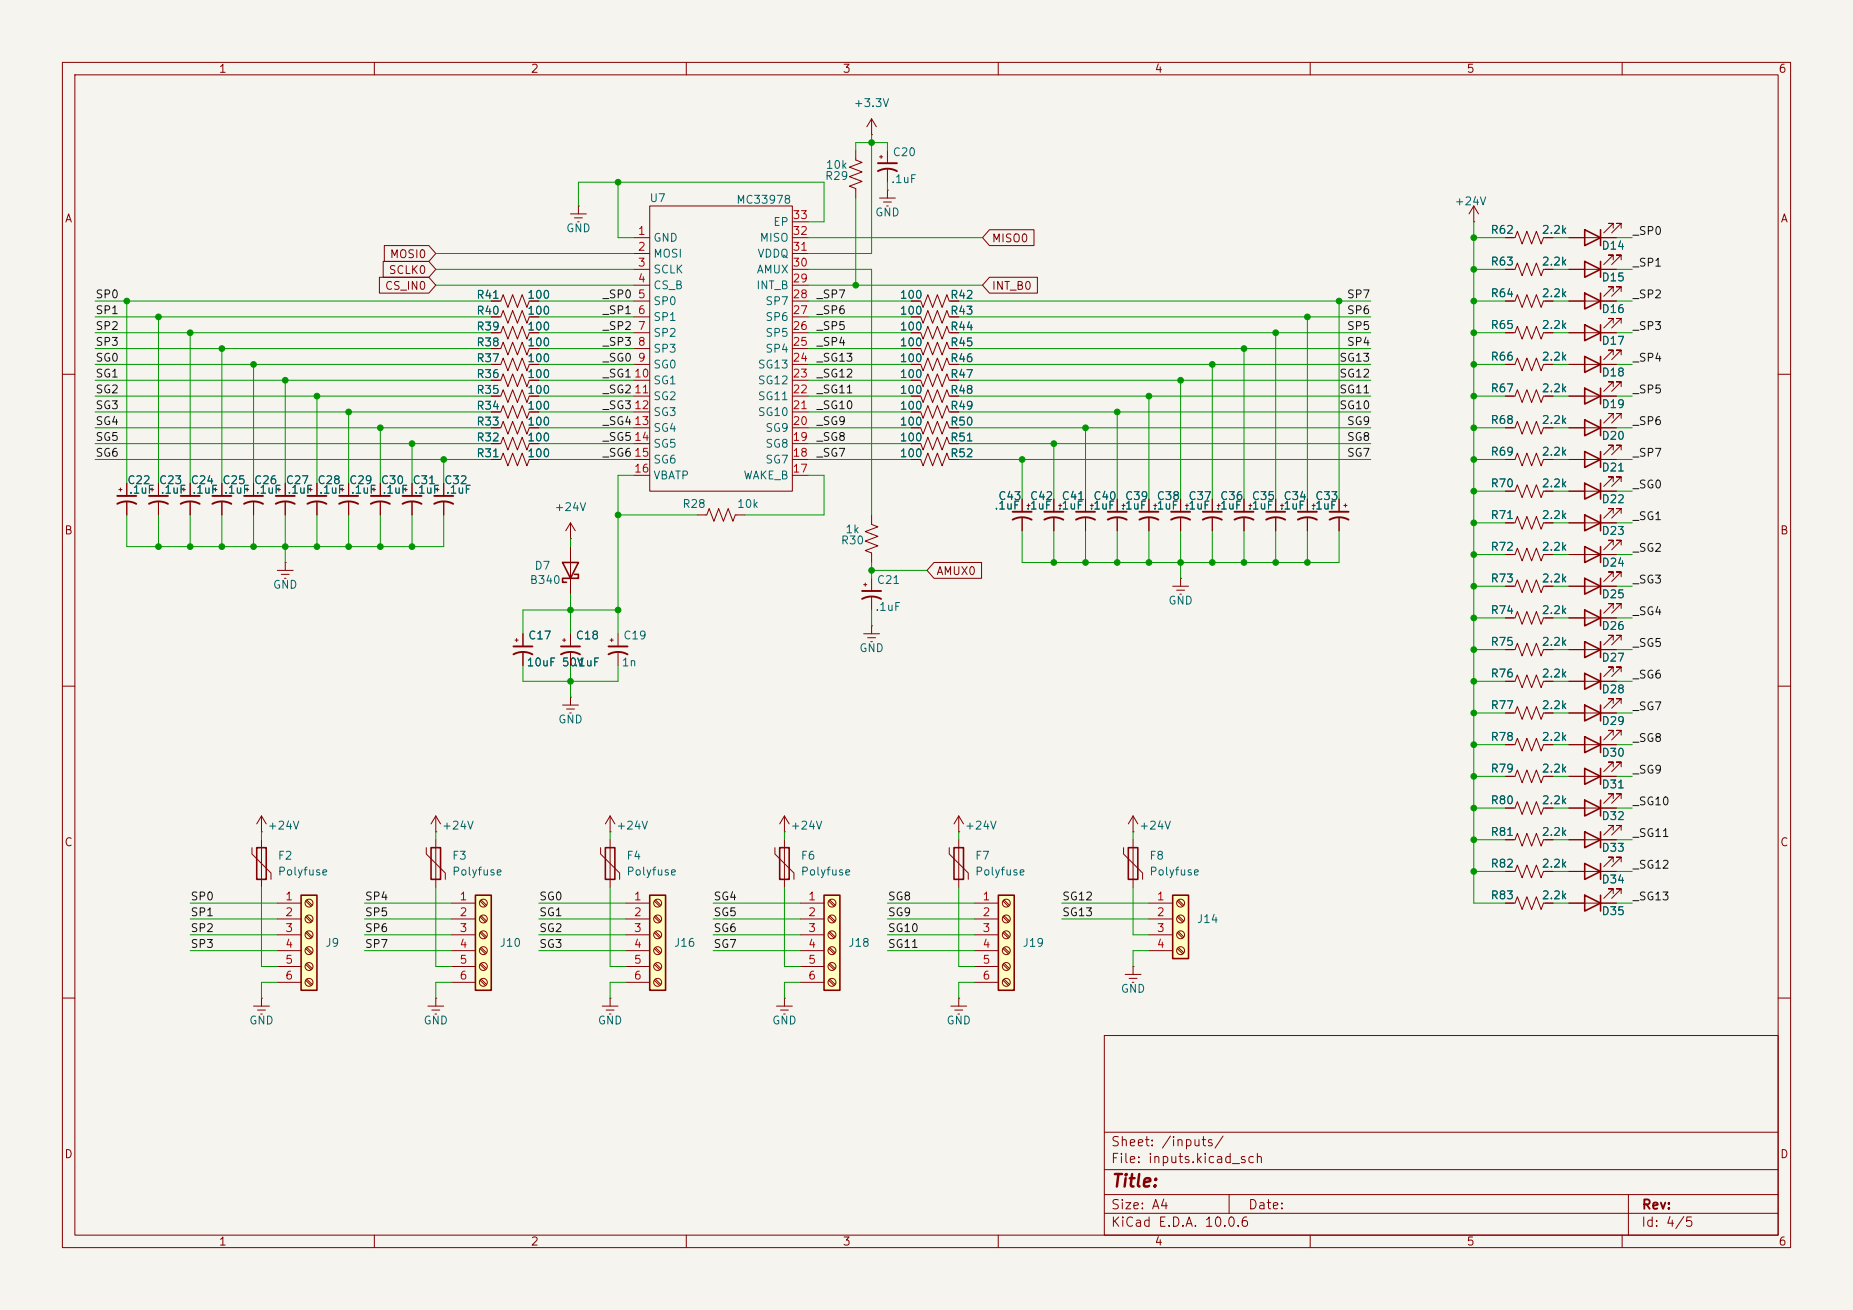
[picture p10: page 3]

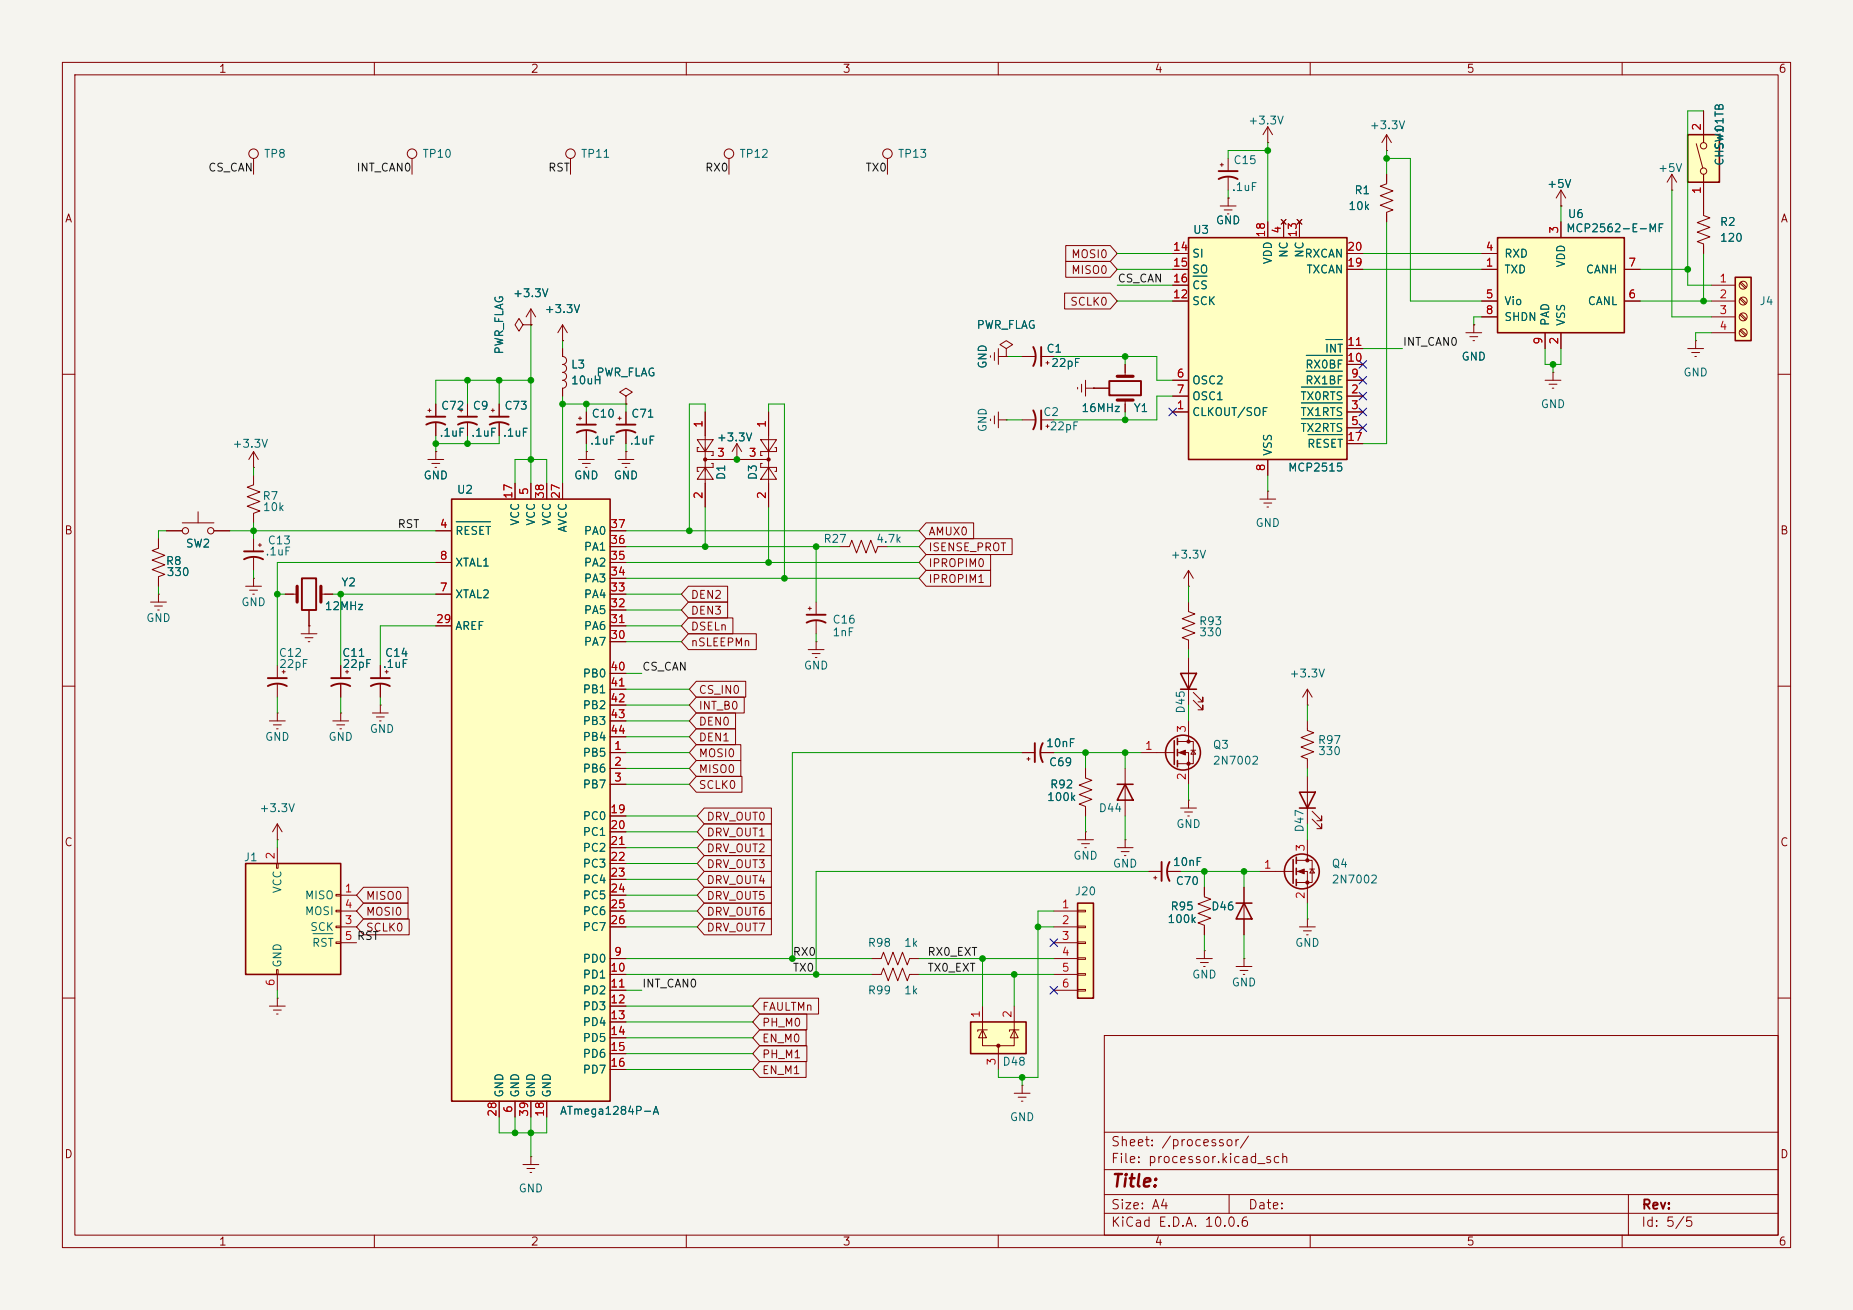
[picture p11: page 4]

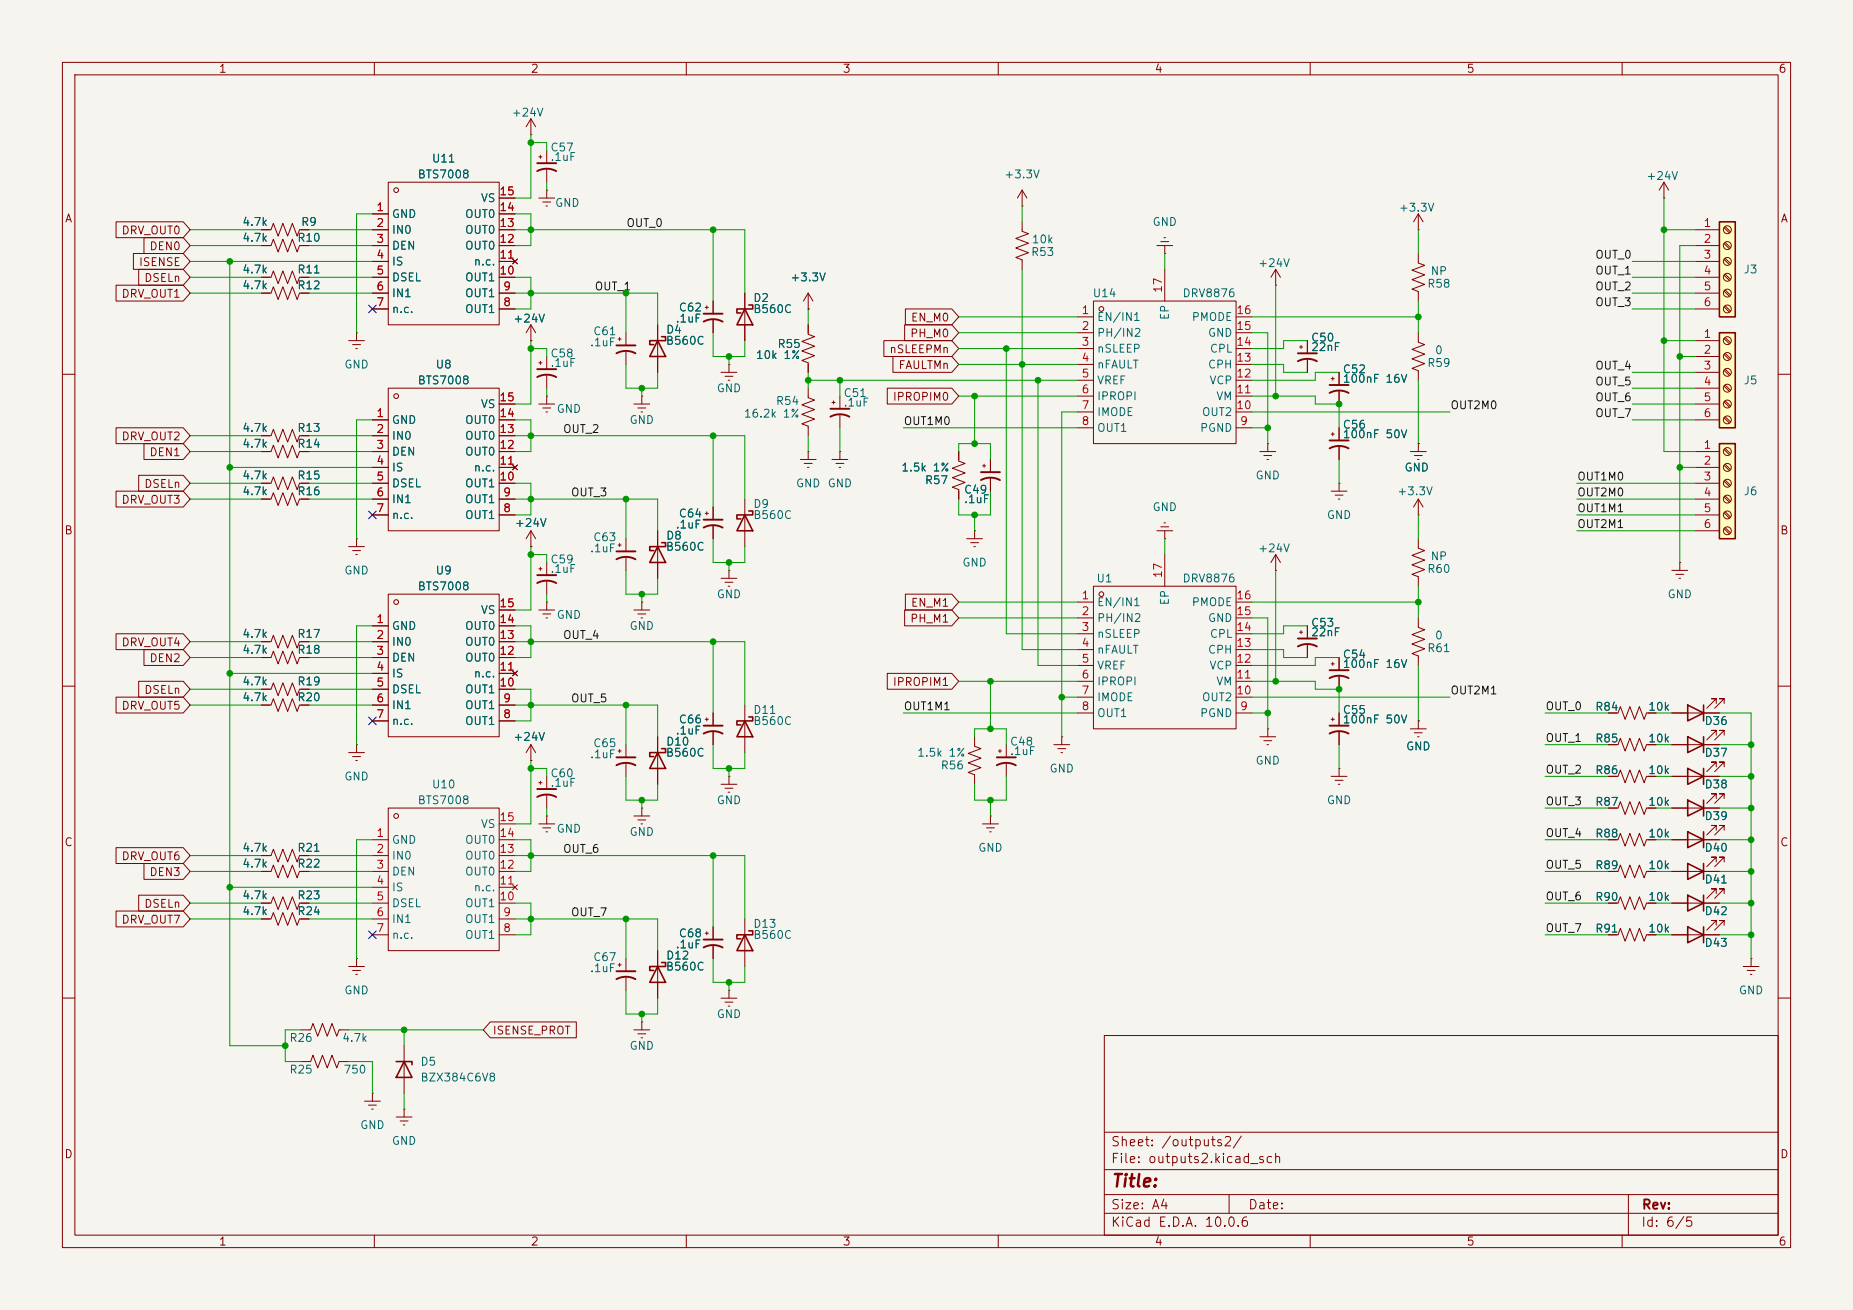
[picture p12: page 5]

nSLEEP 3
nFAULT 4
VREF 5
IPROPI 6

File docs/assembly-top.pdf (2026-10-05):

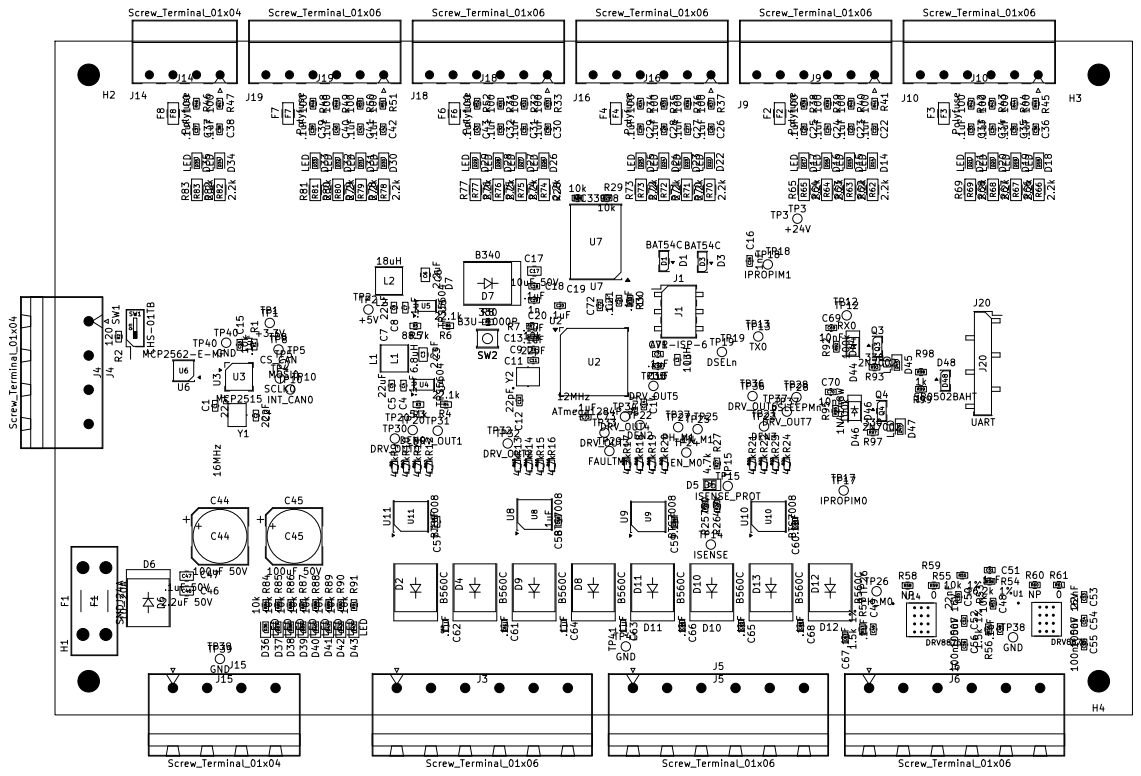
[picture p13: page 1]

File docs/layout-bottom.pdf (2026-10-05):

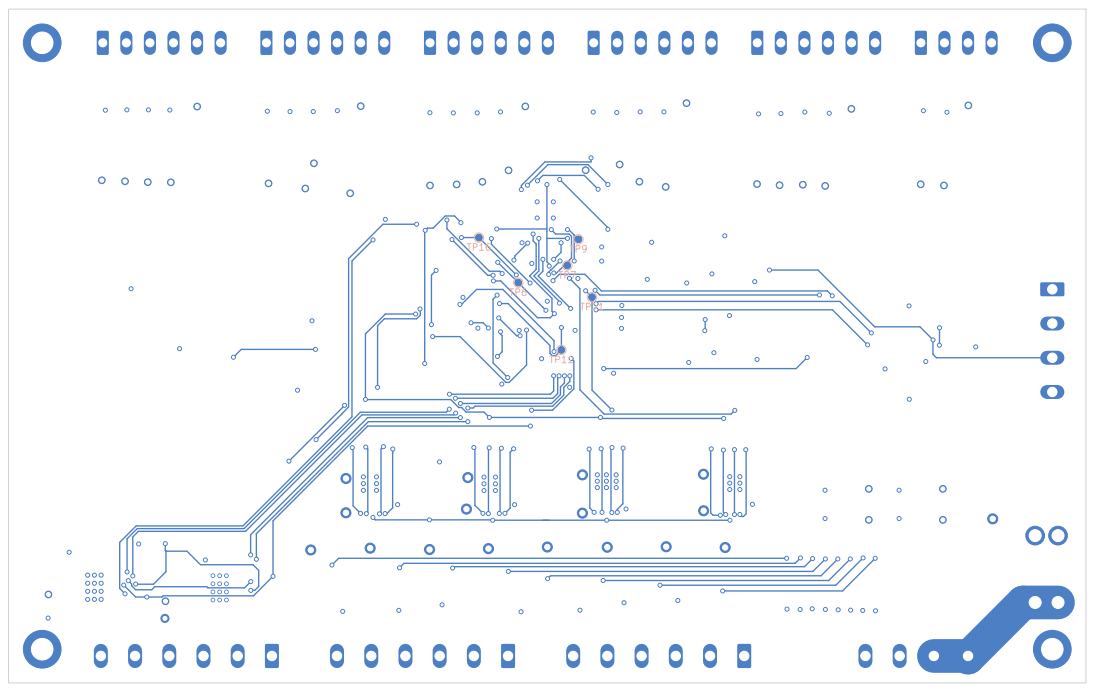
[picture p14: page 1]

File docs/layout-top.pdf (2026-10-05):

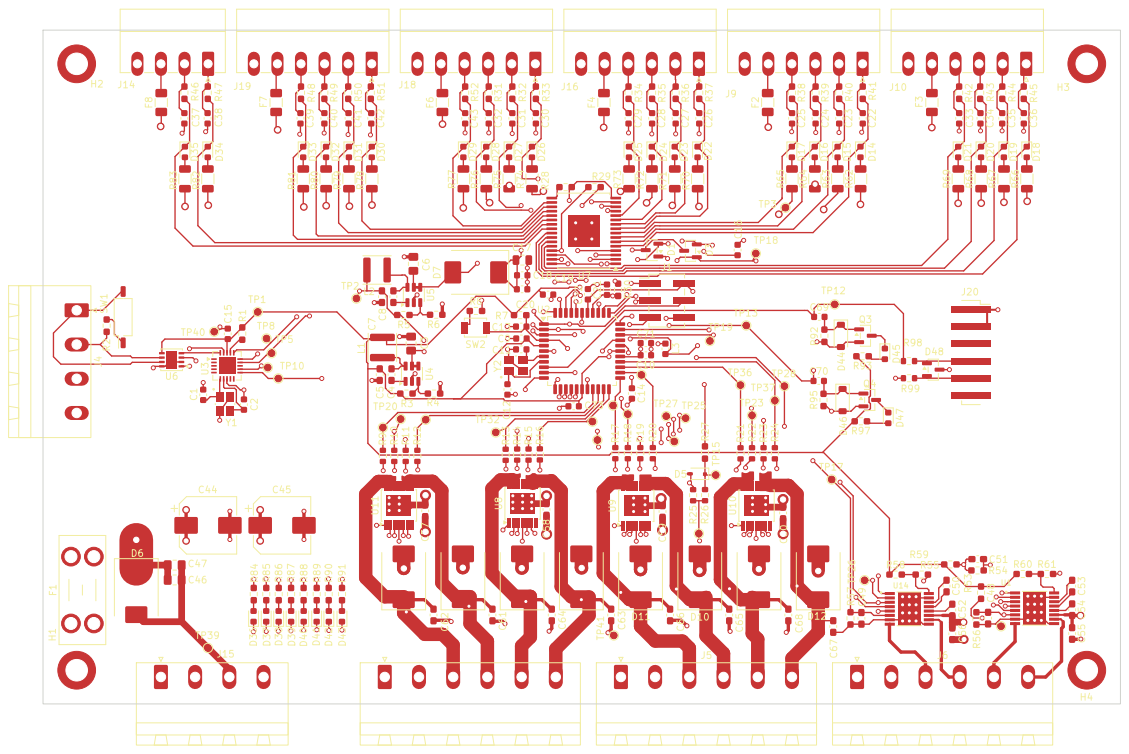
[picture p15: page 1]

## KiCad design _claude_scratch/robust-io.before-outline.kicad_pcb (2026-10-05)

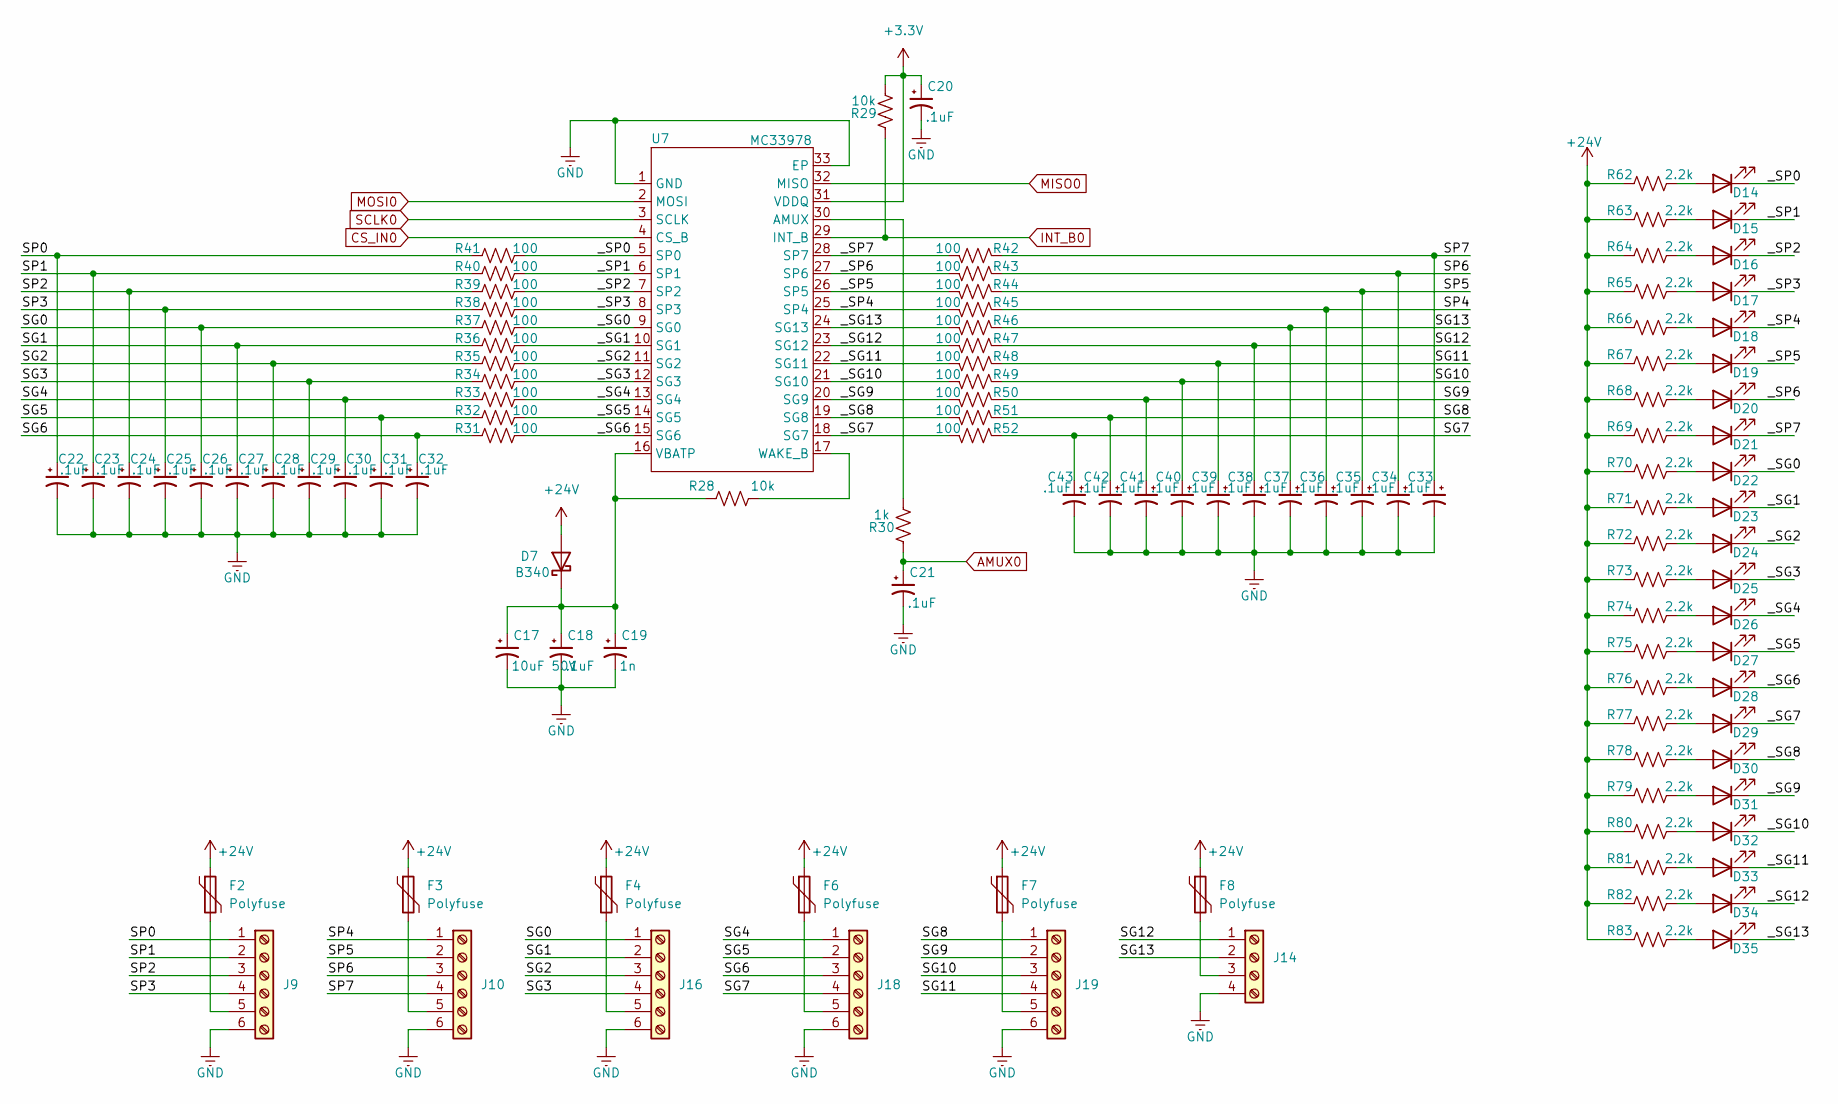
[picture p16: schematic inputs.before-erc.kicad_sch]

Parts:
C17: 10uF 50V; C_0805_2012Metric
C18, C20, C21, C22, C23, C24, C25, C26, C27, C28, C29, C30, C31, C32, C33, C34, C35, C36, C37, C38, C39, C40, C41, C42, C43: .1uF; C_0603_1608Metric
C19: 1n; C_0603_1608Metric
D7: B340; D_SMC
D14, D15, D16, D17, D18, D19, D20, D21, D22, D23, D24, D25, D26, D27, D28, D29, D30, D31, D32, D33, D34, D35: LED; LED_0603_1608Metric
F2, F3, F4, F6, F7, F8: Polyfuse; Fuse_1206_3216Metric
J9, J10, J16, J18, J19: Screw_Terminal_01x06; PhoenixContact_MC_1,5_6-G-3.5_1x06_P3.50mm_Horizontal
J14: Screw_Terminal_01x04; PhoenixContact_MC_1,5_4-G-3.5_1x04_P3.50mm_Horizontal
R28, R29: 10k; R_0603_1608Metric_Pad0.98x0.95mm_HandSolder
R30: 1k; R_0603_1608Metric_Pad0.98x0.95mm_HandSolder
R31, R32, R33, R34, R35, R36, R37, R38, R39, R40, R41, R42, R43, R44, R45, R46, R47, R48, R49, R50, R51, R52: 100; R_0603_1608Metric_Pad0.98x0.95mm_HandSolder
R62, R63, R64, R65, R66, R67, R68, R69, R70, R71, R72, R73, R74, R75, R76, R77, R78, R79, R80, R81, R82, R83: 2.2k; R_1206_3216Metric
U7: MC33978; HSOP-32-1EP_7.5x11mm_P0.65mm_EP4.7x4.7mm; Manufacturer Part MC33978AEKR2; LCSC Part Name MC33978AEKR2

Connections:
+3.3V: C20.1, R29.2, U7.31 (VDDQ); also elsewhere on the board
+24V: D7.2 (A), F2.1, F3.1, F4.1, F6.1, F7.1, F8.1, R62.1, R63.1, R64.1, R65.1, R66.1, R67.1, R68.1, R69.1, R70.1, R71.1, R72.1, R73.1, R74.1, R75.1, R76.1, R77.1, R78.1, R79.1, R80.1, R81.1, R82.1, R83.1; also elsewhere on the board
/inputs/SG0: C26.1, J16.1, R37.1
/inputs/SG1: C27.1, J16.2, R36.1
/inputs/SG2: C28.1, J16.3, R35.1
/inputs/SG3: C29.1, J16.4, R34.1
/inputs/SG4: C30.1, J18.1, R33.1
/inputs/SG5: C31.1, J18.2, R32.1
/inputs/SG6: C32.1, J18.3, R31.1
/inputs/SG7: C43.1, J18.4, R52.1
/inputs/SG8: C42.1, J19.1, R51.1
/inputs/SG9: C41.1, J19.2, R50.1
/inputs/SG10: C40.1, J19.3, R49.1
/inputs/SG11: C39.1, J19.4, R48.1
/inputs/SG12: C38.1, J14.1, R47.1
/inputs/SG13: C37.1, J14.2, R46.1
/inputs/SP0: C22.1, J9.1, R41.1
/inputs/SP1: C23.1, J9.2, R40.1
/inputs/SP2: C24.1, J9.3, R39.1
/inputs/SP3: C25.1, J9.4, R38.1
/inputs/SP4: C36.1, J10.1, R45.1
/inputs/SP5: C35.1, J10.2, R44.1
/inputs/SP6: C34.1, J10.3, R43.1
/inputs/SP7: C33.1, J10.4, R42.1
/inputs/_SG0: D22.1 (K), R37.2, U7.9 (SG0)
/inputs/_SG1: D23.1 (K), R36.2, U7.10 (SG1)
/inputs/_SG2: D24.1 (K), R35.2, U7.11 (SG2)
/inputs/_SG3: D25.1 (K), R34.2, U7.12 (SG3)
/inputs/_SG4: D26.1 (K), R33.2, U7.13 (SG4)
/inputs/_SG5: D27.1 (K), R32.2, U7.14 (SG5)
/inputs/_SG6: D28.1 (K), R31.2, U7.15 (SG6)
/inputs/_SG7: D29.1 (K), R52.2, U7.18 (SG7)
/inputs/_SG8: D30.1 (K), R51.2, U7.19 (SG8)
/inputs/_SG9: D31.1 (K), R50.2, U7.20 (SG9)
/inputs/_SG10: D32.1 (K), R49.2, U7.21 (SG10)
/inputs/_SG11: D33.1 (K), R48.2, U7.22 (SG11)
/inputs/_SG12: D34.1 (K), R47.2, U7.23 (SG12)
/inputs/_SG13: D35.1 (K), R46.2, U7.24 (SG13)
/inputs/_SP0: D14.1 (K), R41.2, U7.5 (SP0)
/inputs/_SP1: D15.1 (K), R40.2, U7.6 (SP1)
/inputs/_SP2: D16.1 (K), R39.2, U7.7 (SP2)
/inputs/_SP3: D17.1 (K), R38.2, U7.8 (SP3)
/inputs/_SP4: D18.1 (K), R45.2, U7.25 (SP4)
/inputs/_SP5: D19.1 (K), R44.2, U7.26 (SP5)
/inputs/_SP6: D20.1 (K), R43.2, U7.27 (SP6)
/inputs/_SP7: D21.1 (K), R42.2, U7.28 (SP7)
AMUX0: C21.1, R30.1; also elsewhere on the board
CS_IN0: U7.4 (CS_B); also elsewhere on the board
GND: C17.2, C18.2, C19.2, C20.2, C21.2, C22.2, C23.2, C24.2, C25.2, C26.2, C27.2, C28.2, C29.2, C30.2, C31.2, C32.2, C33.2, C34.2, C35.2, C36.2, C37.2, C38.2, C39.2, C40.2, C41.2, C42.2, C43.2, J9.6, J10.6, J14.4, J16.6, J18.6, J19.6, U7.1 (GND), U7.33 (EP); also elsewhere on the board
INT_B0: R29.1, U7.29 (INT_B); also elsewhere on the board
MISO0: U7.32 (MISO); also elsewhere on the board
MOSI0: U7.2 (MOSI); also elsewhere on the board
unnamed: C17.1, C18.1, C19.1, D7.1 (K), R28.1, U7.16 (VBATP)
unnamed: D14.2 (A), R62.2
unnamed: D15.2 (A), R63.2
unnamed: D16.2 (A), R64.2
unnamed: D17.2 (A), R65.2
unnamed: D18.2 (A), R66.2
unnamed: D19.2 (A), R67.2
unnamed: D20.2 (A), R68.2
unnamed: D21.2 (A), R69.2
unnamed: D22.2 (A), R70.2
unnamed: D23.2 (A), R71.2
unnamed: D24.2 (A), R72.2
unnamed: D25.2 (A), R73.2
unnamed: D26.2 (A), R74.2
unnamed: D27.2 (A), R75.2
unnamed: D28.2 (A), R76.2
unnamed: D29.2 (A), R77.2
unnamed: D30.2 (A), R78.2
unnamed: D31.2 (A), R79.2
unnamed: D32.2 (A), R80.2
unnamed: D33.2 (A), R81.2
unnamed: D34.2 (A), R82.2
unnamed: D35.2 (A), R83.2
unnamed: F2.2, J9.5
unnamed: F3.2, J10.5
unnamed: F8.2, J14.3
unnamed: F4.2, J16.5
unnamed: F6.2, J18.5
unnamed: F7.2, J19.5
unnamed: R30.2, U7.30 (AMUX)
unnamed: R28.2, U7.17 (WAKE_B)
SCLK0: U7.3 (SCLK); also elsewhere on the board

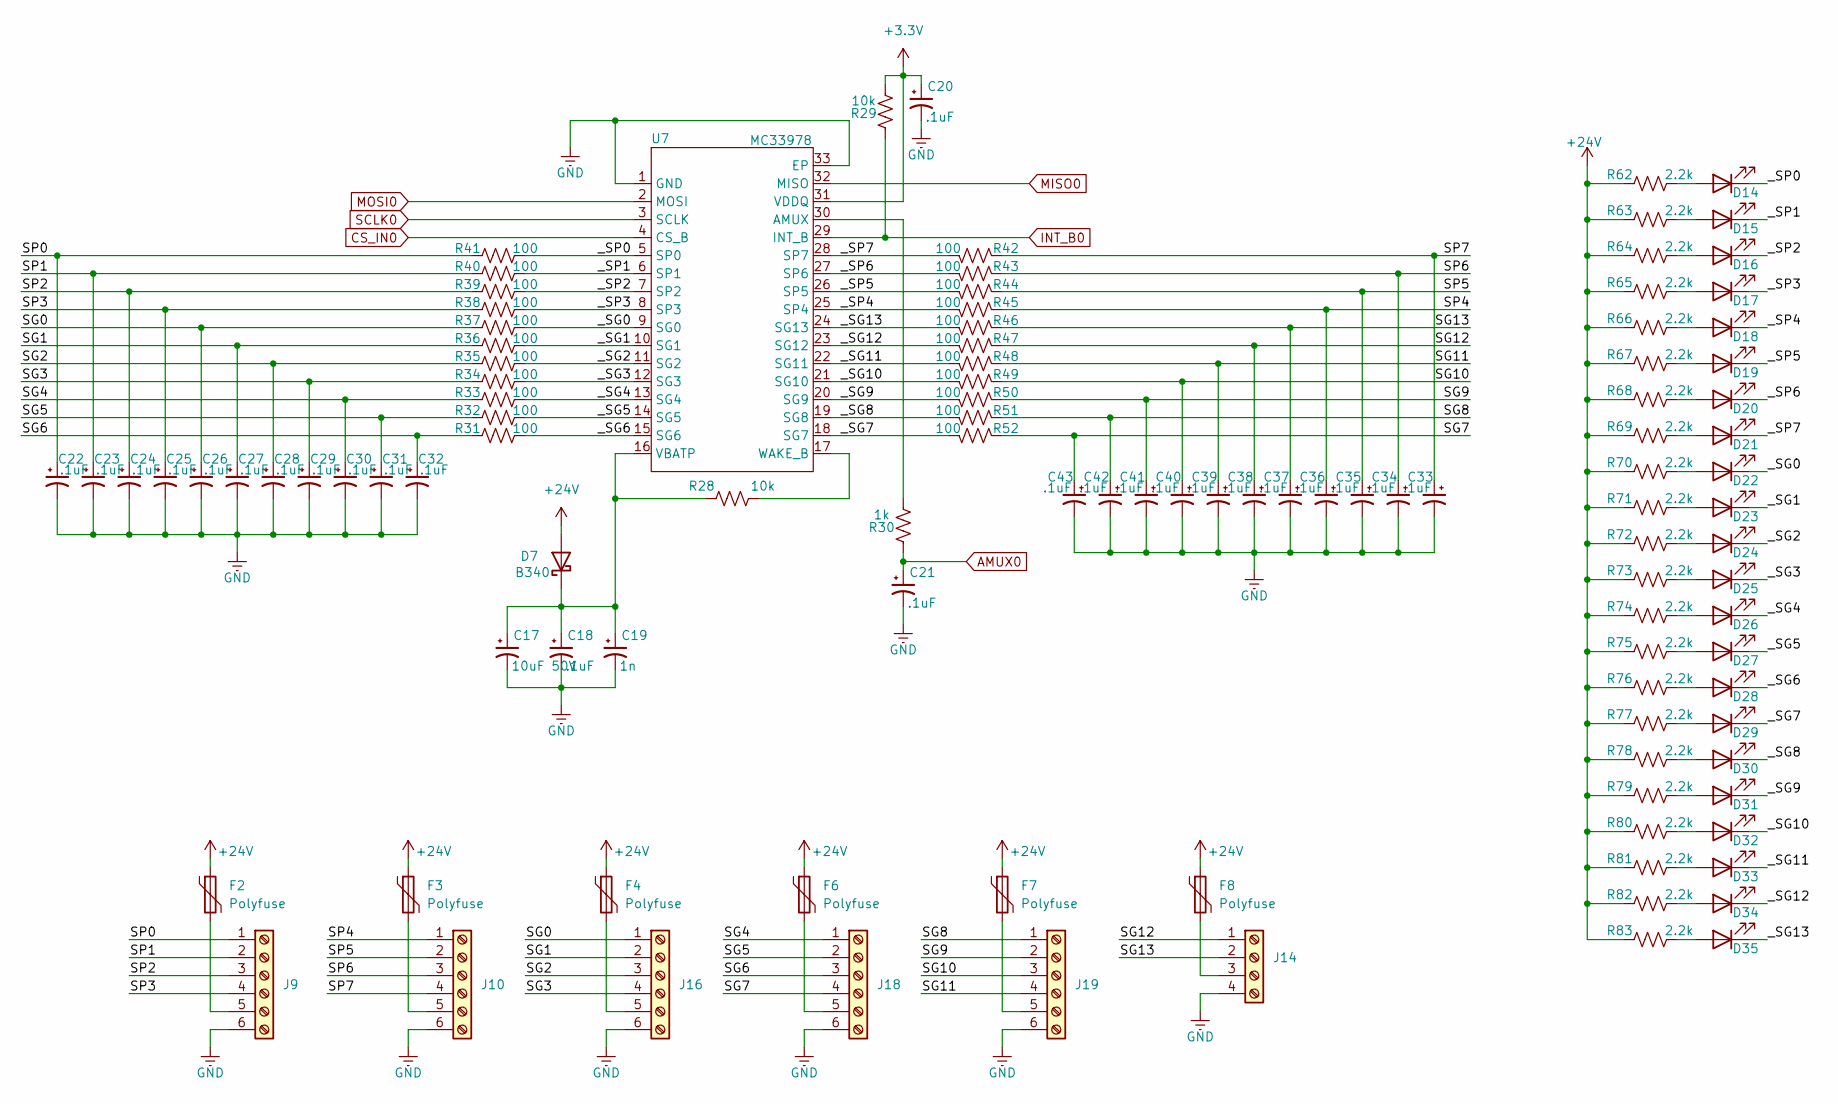
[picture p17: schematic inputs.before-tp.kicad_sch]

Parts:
C17: 10uF 50V; C_0805_2012Metric
C18, C20, C21, C22, C23, C24, C25, C26, C27, C28, C29, C30, C31, C32, C33, C34, C35, C36, C37, C38, C39, C40, C41, C42, C43: .1uF; C_0603_1608Metric
C19: 1n; C_0603_1608Metric
D7: B340; D_SMC
D14, D15, D16, D17, D18, D19, D20, D21, D22, D23, D24, D25, D26, D27, D28, D29, D30, D31, D32, D33, D34, D35: LED; LED_0603_1608Metric
F2, F3, F4, F6, F7, F8: Polyfuse; Fuse_1206_3216Metric
J9, J10, J16, J18, J19: Screw_Terminal_01x06; PhoenixContact_MC_1,5_6-G-3.5_1x06_P3.50mm_Horizontal
J14: Screw_Terminal_01x04; PhoenixContact_MC_1,5_4-G-3.5_1x04_P3.50mm_Horizontal
R28, R29: 10k; R_0603_1608Metric_Pad0.98x0.95mm_HandSolder
R30: 1k; R_0603_1608Metric_Pad0.98x0.95mm_HandSolder
R31, R32, R33, R34, R35, R36, R37, R38, R39, R40, R41, R42, R43, R44, R45, R46, R47, R48, R49, R50, R51, R52: 100; R_0603_1608Metric_Pad0.98x0.95mm_HandSolder
R62, R63, R64, R65, R66, R67, R68, R69, R70, R71, R72, R73, R74, R75, R76, R77, R78, R79, R80, R81, R82, R83: 2.2k; R_1206_3216Metric
U7: MC33978; HSOP-32-1EP_7.5x11mm_P0.65mm_EP4.7x4.7mm; Manufacturer Part MC33978AEKR2; LCSC Part Name MC33978AEKR2

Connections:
+3.3V: C20.1, R29.2, U7.31 (VDDQ); also elsewhere on the board
+24V: D7.2 (A), F2.1, F3.1, F4.1, F6.1, F7.1, F8.1, R62.1, R63.1, R64.1, R65.1, R66.1, R67.1, R68.1, R69.1, R70.1, R71.1, R72.1, R73.1, R74.1, R75.1, R76.1, R77.1, R78.1, R79.1, R80.1, R81.1, R82.1, R83.1; also elsewhere on the board
/inputs/SG0: C26.1, J16.1, R37.1
/inputs/SG1: C27.1, J16.2, R36.1
/inputs/SG2: C28.1, J16.3, R35.1
/inputs/SG3: C29.1, J16.4, R34.1
/inputs/SG4: C30.1, J18.1, R33.1
/inputs/SG5: C31.1, J18.2, R32.1
/inputs/SG6: C32.1, J18.3, R31.1
/inputs/SG7: C43.1, J18.4, R52.1
/inputs/SG8: C42.1, J19.1, R51.1
/inputs/SG9: C41.1, J19.2, R50.1
/inputs/SG10: C40.1, J19.3, R49.1
/inputs/SG11: C39.1, J19.4, R48.1
/inputs/SG12: C38.1, J14.1, R47.1
/inputs/SG13: C37.1, J14.2, R46.1
/inputs/SP0: C22.1, J9.1, R41.1
/inputs/SP1: C23.1, J9.2, R40.1
/inputs/SP2: C24.1, J9.3, R39.1
/inputs/SP3: C25.1, J9.4, R38.1
/inputs/SP4: C36.1, J10.1, R45.1
/inputs/SP5: C35.1, J10.2, R44.1
/inputs/SP6: C34.1, J10.3, R43.1
/inputs/SP7: C33.1, J10.4, R42.1
/inputs/_SG0: D22.1 (K), R37.2, U7.9 (SG0)
/inputs/_SG1: D23.1 (K), R36.2, U7.10 (SG1)
/inputs/_SG2: D24.1 (K), R35.2, U7.11 (SG2)
/inputs/_SG3: D25.1 (K), R34.2, U7.12 (SG3)
/inputs/_SG4: D26.1 (K), R33.2, U7.13 (SG4)
/inputs/_SG5: D27.1 (K), R32.2, U7.14 (SG5)
/inputs/_SG6: D28.1 (K), R31.2, U7.15 (SG6)
/inputs/_SG7: D29.1 (K), R52.2, U7.18 (SG7)
/inputs/_SG8: D30.1 (K), R51.2, U7.19 (SG8)
/inputs/_SG9: D31.1 (K), R50.2, U7.20 (SG9)
/inputs/_SG10: D32.1 (K), R49.2, U7.21 (SG10)
/inputs/_SG11: D33.1 (K), R48.2, U7.22 (SG11)
/inputs/_SG12: D34.1 (K), R47.2, U7.23 (SG12)
/inputs/_SG13: D35.1 (K), R46.2, U7.24 (SG13)
/inputs/_SP0: D14.1 (K), R41.2, U7.5 (SP0)
/inputs/_SP1: D15.1 (K), R40.2, U7.6 (SP1)
/inputs/_SP2: D16.1 (K), R39.2, U7.7 (SP2)
/inputs/_SP3: D17.1 (K), R38.2, U7.8 (SP3)
/inputs/_SP4: D18.1 (K), R45.2, U7.25 (SP4)
/inputs/_SP5: D19.1 (K), R44.2, U7.26 (SP5)
/inputs/_SP6: D20.1 (K), R43.2, U7.27 (SP6)
/inputs/_SP7: D21.1 (K), R42.2, U7.28 (SP7)
AMUX0: C21.1, R30.1; also elsewhere on the board
CS_IN0: U7.4 (CS_B); also elsewhere on the board
GND: C17.2, C18.2, C19.2, C20.2, C21.2, C22.2, C23.2, C24.2, C25.2, C26.2, C27.2, C28.2, C29.2, C30.2, C31.2, C32.2, C33.2, C34.2, C35.2, C36.2, C37.2, C38.2, C39.2, C40.2, C41.2, C42.2, C43.2, J9.6, J10.6, J14.4, J16.6, J18.6, J19.6, U7.1 (GND), U7.33 (EP); also elsewhere on the board
INT_B0: R29.1, U7.29 (INT_B); also elsewhere on the board
MISO0: U7.32 (MISO); also elsewhere on the board
MOSI0: U7.2 (MOSI); also elsewhere on the board
unnamed: C17.1, C18.1, C19.1, D7.1 (K), R28.1, U7.16 (VBATP)
unnamed: D14.2 (A), R62.2
unnamed: D15.2 (A), R63.2
unnamed: D16.2 (A), R64.2
unnamed: D17.2 (A), R65.2
unnamed: D18.2 (A), R66.2
unnamed: D19.2 (A), R67.2
unnamed: D20.2 (A), R68.2
unnamed: D21.2 (A), R69.2
unnamed: D22.2 (A), R70.2
unnamed: D23.2 (A), R71.2
unnamed: D24.2 (A), R72.2
unnamed: D25.2 (A), R73.2
unnamed: D26.2 (A), R74.2
unnamed: D27.2 (A), R75.2
unnamed: D28.2 (A), R76.2
unnamed: D29.2 (A), R77.2
unnamed: D30.2 (A), R78.2
unnamed: D31.2 (A), R79.2
unnamed: D32.2 (A), R80.2
unnamed: D33.2 (A), R81.2
unnamed: D34.2 (A), R82.2
unnamed: D35.2 (A), R83.2
unnamed: F2.2, J9.5
unnamed: F3.2, J10.5
unnamed: F8.2, J14.3
unnamed: F4.2, J16.5
unnamed: F6.2, J18.5
unnamed: F7.2, J19.5
unnamed: R30.2, U7.30 (AMUX)
unnamed: R28.2, U7.17 (WAKE_B)
SCLK0: U7.3 (SCLK); also elsewhere on the board

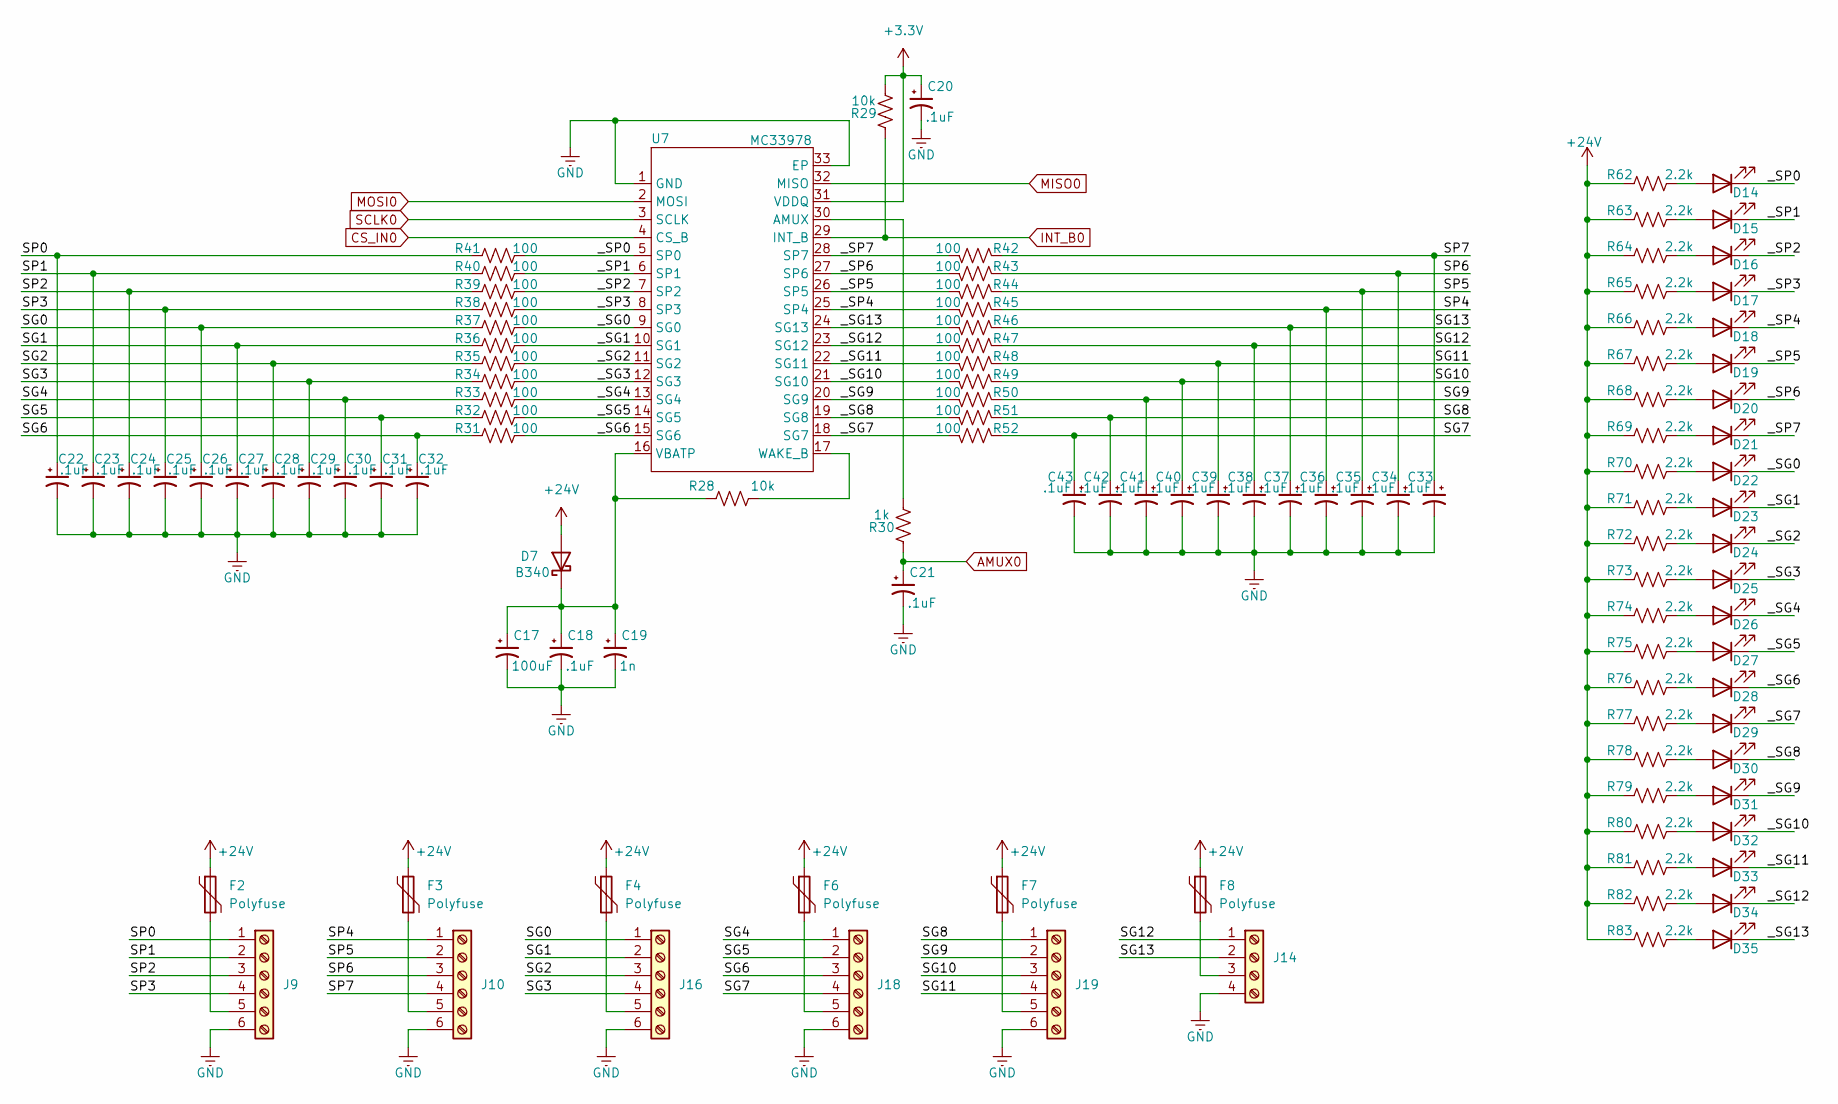
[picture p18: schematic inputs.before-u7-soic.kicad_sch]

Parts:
C17: 100uF; C_0603_1608Metric
C18, C20, C21, C22, C23, C24, C25, C26, C27, C28, C29, C30, C31, C32, C33, C34, C35, C36, C37, C38, C39, C40, C41, C42, C43: .1uF; C_0603_1608Metric
C19: 1n; C_0603_1608Metric
D7: B340; D_SMC
D14, D15, D16, D17, D18, D19, D20, D21, D22, D23, D24, D25, D26, D27, D28, D29, D30, D31, D32, D33, D34, D35: LED; LED_0603_1608Metric
F2, F3, F4, F6, F7, F8: Polyfuse; Fuse_1206_3216Metric
J9, J10, J16, J18, J19: Screw_Terminal_01x06; PhoenixContact_MC_1,5_6-G-3.5_1x06_P3.50mm_Horizontal
J14: Screw_Terminal_01x04; PhoenixContact_MC_1,5_4-G-3.5_1x04_P3.50mm_Horizontal
R28, R29: 10k; R_0603_1608Metric_Pad0.98x0.95mm_HandSolder
R30: 1k; R_0603_1608Metric_Pad0.98x0.95mm_HandSolder
R31, R32, R33, R34, R35, R36, R37, R38, R39, R40, R41, R42, R43, R44, R45, R46, R47, R48, R49, R50, R51, R52: 100; R_0603_1608Metric_Pad0.98x0.95mm_HandSolder
R62, R63, R64, R65, R66, R67, R68, R69, R70, R71, R72, R73, R74, R75, R76, R77, R78, R79, R80, R81, R82, R83: 2.2k; R_1206_3216Metric
U7: MC33978; QFN-32-1EP_5x5mm_P0.5mm_EP3.7x3.7mm_ThermalVias; Manufacturer Part MC33978AEKR2; LCSC Part Name MC33978AEKR2

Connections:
+3.3V: C20.1, R29.2, U7.31 (VDDQ); also elsewhere on the board
+24V: D7.2 (A), F2.1, F3.1, F4.1, F6.1, F7.1, F8.1, R62.1, R63.1, R64.1, R65.1, R66.1, R67.1, R68.1, R69.1, R70.1, R71.1, R72.1, R73.1, R74.1, R75.1, R76.1, R77.1, R78.1, R79.1, R80.1, R81.1, R82.1, R83.1; also elsewhere on the board
/inputs/SG0: C26.1, J16.1, R37.1
/inputs/SG1: C27.1, J16.2, R36.1
/inputs/SG2: C28.1, J16.3, R35.1
/inputs/SG3: C29.1, J16.4, R34.1
/inputs/SG4: C30.1, J18.1, R33.1
/inputs/SG5: C31.1, J18.2, R32.1
/inputs/SG6: C32.1, J18.3, R31.1
/inputs/SG7: C43.1, J18.4, R52.1
/inputs/SG8: C42.1, J19.1, R51.1
/inputs/SG9: C41.1, J19.2, R50.1
/inputs/SG10: C40.1, J19.3, R49.1
/inputs/SG11: C39.1, J19.4, R48.1
/inputs/SG12: C38.1, J14.1, R47.1
/inputs/SG13: C37.1, J14.2, R46.1
/inputs/SP0: C22.1, J9.1, R41.1
/inputs/SP1: C23.1, J9.2, R40.1
/inputs/SP2: C24.1, J9.3, R39.1
/inputs/SP3: C25.1, J9.4, R38.1
/inputs/SP4: C36.1, J10.1, R45.1
/inputs/SP5: C35.1, J10.2, R44.1
/inputs/SP6: C34.1, J10.3, R43.1
/inputs/SP7: C33.1, J10.4, R42.1
/inputs/_SG0: D22.1 (K), R37.2, U7.9 (SG0)
/inputs/_SG1: D23.1 (K), R36.2, U7.10 (SG1)
/inputs/_SG2: D24.1 (K), R35.2, U7.11 (SG2)
/inputs/_SG3: D25.1 (K), R34.2, U7.12 (SG3)
/inputs/_SG4: D26.1 (K), R33.2, U7.13 (SG4)
/inputs/_SG5: D27.1 (K), R32.2, U7.14 (SG5)
/inputs/_SG6: D28.1 (K), R31.2, U7.15 (SG6)
/inputs/_SG7: D29.1 (K), R52.2, U7.18 (SG7)
/inputs/_SG8: D30.1 (K), R51.2, U7.19 (SG8)
/inputs/_SG9: D31.1 (K), R50.2, U7.20 (SG9)
/inputs/_SG10: D32.1 (K), R49.2, U7.21 (SG10)
/inputs/_SG11: D33.1 (K), R48.2, U7.22 (SG11)
/inputs/_SG12: D34.1 (K), R47.2, U7.23 (SG12)
/inputs/_SG13: D35.1 (K), R46.2, U7.24 (SG13)
/inputs/_SP0: D14.1 (K), R41.2, U7.5 (SP0)
/inputs/_SP1: D15.1 (K), R40.2, U7.6 (SP1)
/inputs/_SP2: D16.1 (K), R39.2, U7.7 (SP2)
/inputs/_SP3: D17.1 (K), R38.2, U7.8 (SP3)
/inputs/_SP4: D18.1 (K), R45.2, U7.25 (SP4)
/inputs/_SP5: D19.1 (K), R44.2, U7.26 (SP5)
/inputs/_SP6: D20.1 (K), R43.2, U7.27 (SP6)
/inputs/_SP7: D21.1 (K), R42.2, U7.28 (SP7)
AMUX0: C21.1, R30.1; also elsewhere on the board
CS_IN0: U7.4 (CS_B); also elsewhere on the board
GND: C17.2, C18.2, C19.2, C20.2, C21.2, C22.2, C23.2, C24.2, C25.2, C26.2, C27.2, C28.2, C29.2, C30.2, C31.2, C32.2, C33.2, C34.2, C35.2, C36.2, C37.2, C38.2, C39.2, C40.2, C41.2, C42.2, C43.2, J9.6, J10.6, J14.4, J16.6, J18.6, J19.6, U7.1 (GND), U7.33 (EP); also elsewhere on the board
INT_B0: R29.1, U7.29 (INT_B); also elsewhere on the board
MISO0: U7.32 (MISO); also elsewhere on the board
MOSI0: U7.2 (MOSI); also elsewhere on the board
unnamed: C17.1, C18.1, C19.1, D7.1 (K), R28.1, U7.16 (VBATP)
unnamed: D14.2 (A), R62.2
unnamed: D15.2 (A), R63.2
unnamed: D16.2 (A), R64.2
unnamed: D17.2 (A), R65.2
unnamed: D18.2 (A), R66.2
unnamed: D19.2 (A), R67.2
unnamed: D20.2 (A), R68.2
unnamed: D21.2 (A), R69.2
unnamed: D22.2 (A), R70.2
unnamed: D23.2 (A), R71.2
unnamed: D24.2 (A), R72.2
unnamed: D25.2 (A), R73.2
unnamed: D26.2 (A), R74.2
unnamed: D27.2 (A), R75.2
unnamed: D28.2 (A), R76.2
unnamed: D29.2 (A), R77.2
unnamed: D30.2 (A), R78.2
unnamed: D31.2 (A), R79.2
unnamed: D32.2 (A), R80.2
unnamed: D33.2 (A), R81.2
unnamed: D34.2 (A), R82.2
unnamed: D35.2 (A), R83.2
unnamed: F2.2, J9.5
unnamed: F3.2, J10.5
unnamed: F8.2, J14.3
unnamed: F4.2, J16.5
unnamed: F6.2, J18.5
unnamed: F7.2, J19.5
unnamed: R30.2, U7.30 (AMUX)
unnamed: R28.2, U7.17 (WAKE_B)
SCLK0: U7.3 (SCLK); also elsewhere on the board

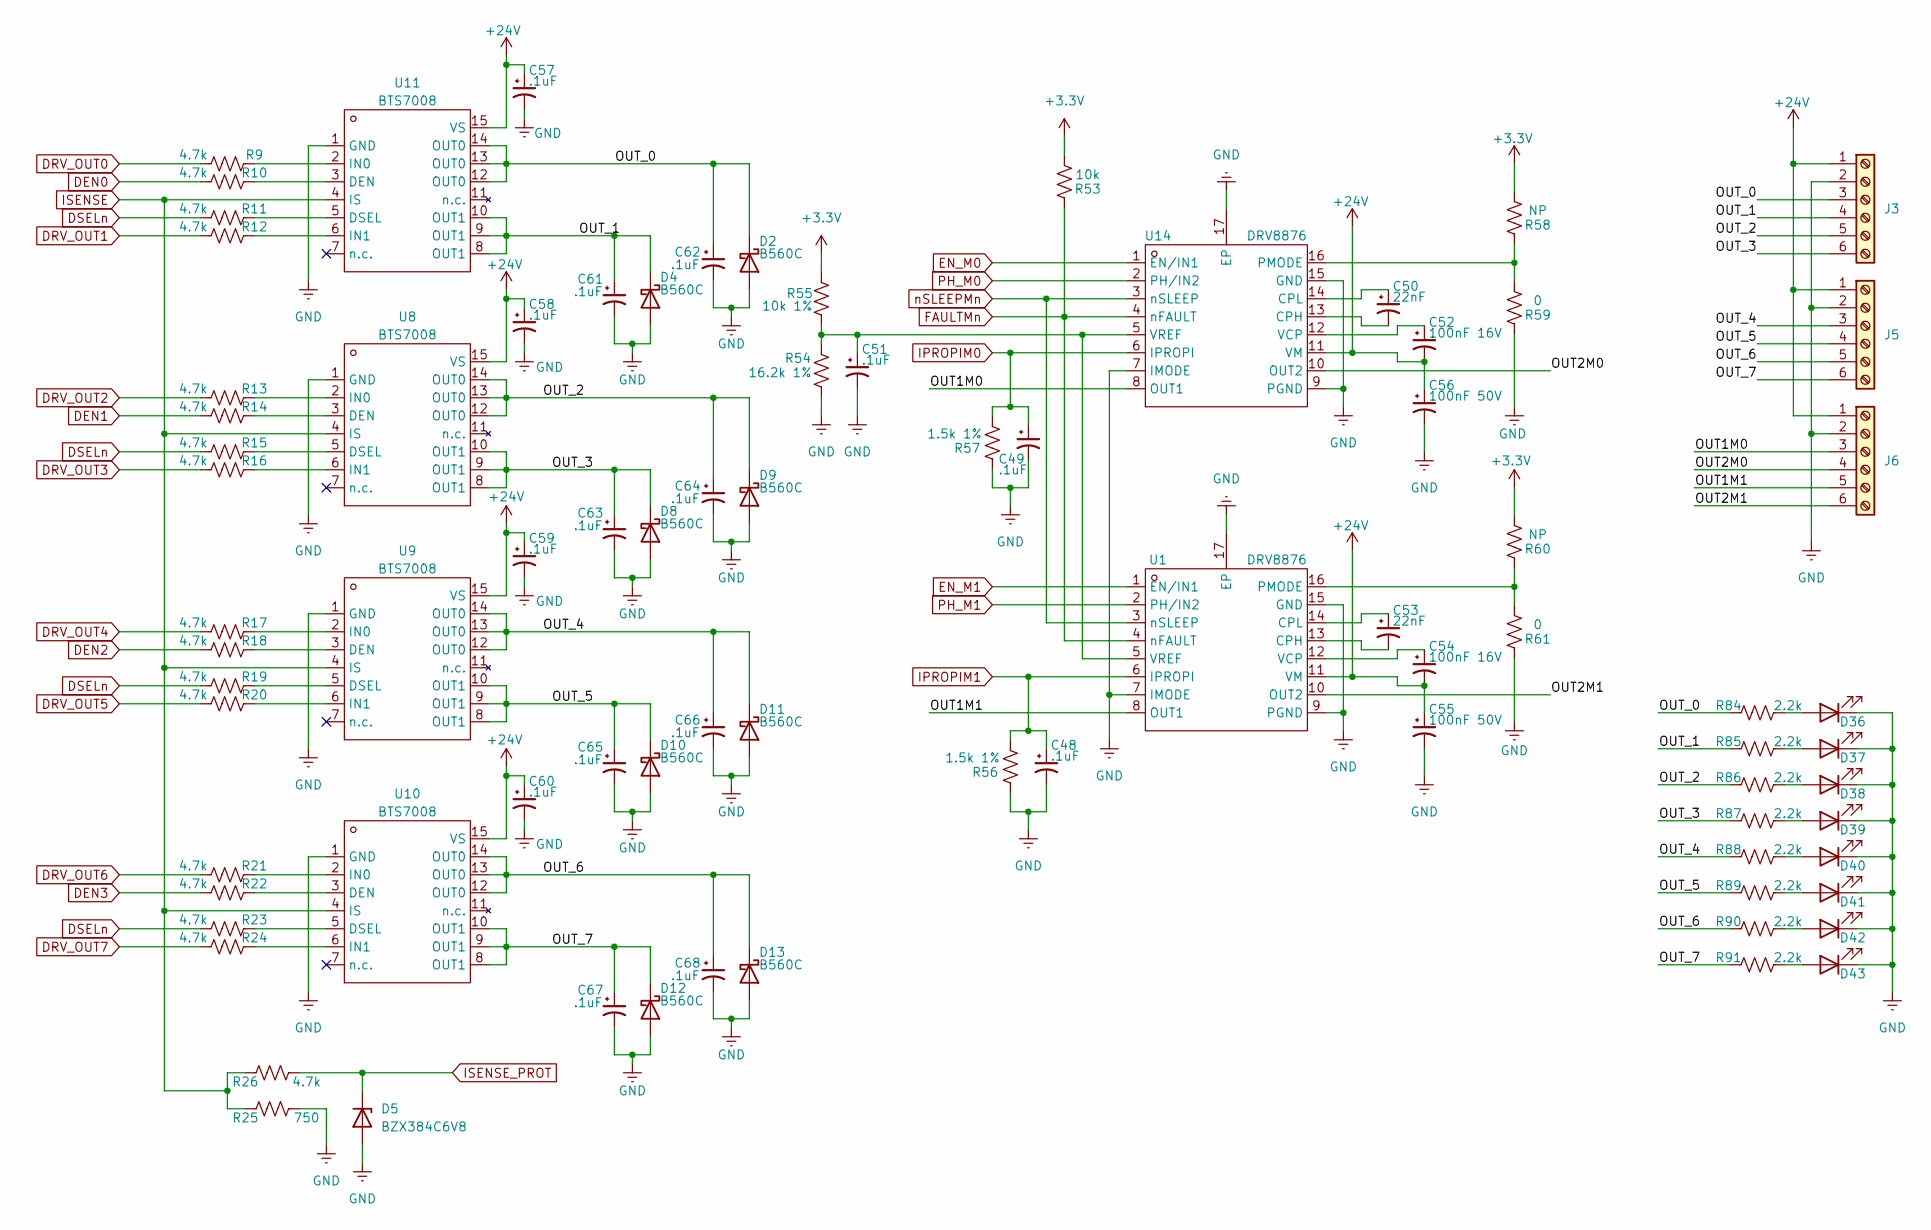
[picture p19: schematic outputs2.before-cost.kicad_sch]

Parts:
C48, C49, C51, C57, C58, C59, C60, C61, C62, C63, C64, C65, C66, C67, C68: .1uF; C_0603_1608Metric_Pad1.08x0.95mm_HandSolder
C50, C53: 22nF; C_0603_1608Metric_Pad1.08x0.95mm_HandSolder
C52, C54: 100nF 16V; C_0603_1608Metric_Pad1.08x0.95mm_HandSolder
C55, C56: 100nF 50V; C_0603_1608Metric_Pad1.08x0.95mm_HandSolder
D2, D4, D8, D9, D10, D11, D12, D13: B560C; D_SMC
D5: BZX384C6V8; D_SOD-323
D36, D37, D38, D39, D40, D41, D42, D43: LED; LED_0603_1608Metric
J3, J5, J6: Screw_Terminal_01x06; PhoenixContact_MSTBA_2,5_6-G-5,08_1x06_P5.08mm_Horizontal
R9, R10, R11, R12, R13, R14, R15, R16, R17, R18, R19, R20, R21, R22, R23, R24, R26: 4.7k; R_0603_1608Metric
R25: 750; R_0603_1608Metric
R53: 10k; R_0603_1608Metric_Pad0.98x0.95mm_HandSolder
R54: 16.2k 1%; R_0603_1608Metric_Pad0.98x0.95mm_HandSolder
R55: 10k 1%; R_0603_1608Metric_Pad0.98x0.95mm_HandSolder
R56, R57: 1.5k 1%; R_0603_1608Metric_Pad0.98x0.95mm_HandSolder
R58, R60: NP; R_0603_1608Metric_Pad0.98x0.95mm_HandSolder
R59, R61: 0; R_0603_1608Metric_Pad0.98x0.95mm_HandSolder
R84, R85, R86, R87, R88, R89, R90, R91: 2.2k; R_0603_1608Metric_Pad0.98x0.95mm_HandSolder
U1, U14: DRV8876; IC_DRV8876PWPR; Manufacturer Part DRV8876PWPR; LCSC Part Name 3.5A 有刷直流电机驱动芯片 5.5V
U8, U9, U10, U11: BTS7008; TSSOP-14-1EP_4.4x5mm_P0.65mm; Manufacturer Part BTS7008-2EPA; LCSC Part Name 12V智能高端功率开关

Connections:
+3.3V: R53.1, R55.1, R58.1, R60.1; also elsewhere on the board
+24V: C52.2, C54.2, C55.1, C56.1, C57.1, C58.1, C59.1, C60.1, J3.1, J5.1, J6.1, U1.11 (VM), U8.15 (VS), U9.15 (VS), U10.15 (VS), U11.15 (VS), U14.11 (VM); also elsewhere on the board
/outputs2/OUT1M0: J6.3, U14.8 (OUT1)
/outputs2/OUT1M1: J6.5, U1.8 (OUT1)
/outputs2/OUT2M0: J6.4, U14.10 (OUT2)
/outputs2/OUT2M1: J6.6, U1.10 (OUT2)
/outputs2/OUT_0: C62.1, D2.1 (K), J3.3, R84.1, U11.12 (OUT0), U11.13 (OUT0), U11.14 (OUT0)
/outputs2/OUT_1: C61.1, D4.1 (K), J3.4, R85.1, U11.8 (OUT1), U11.9 (OUT1), U11.10 (OUT1)
/outputs2/OUT_2: C64.1, D9.1 (K), J3.5, R86.1, U8.12 (OUT0), U8.13 (OUT0), U8.14 (OUT0)
/outputs2/OUT_3: C63.1, D8.1 (K), J3.6, R87.1, U8.8 (OUT1), U8.9 (OUT1), U8.10 (OUT1)
/outputs2/OUT_4: C66.1, D11.1 (K), J5.3, R88.1, U9.12 (OUT0), U9.13 (OUT0), U9.14 (OUT0)
/outputs2/OUT_5: C65.1, D10.1 (K), J5.4, R89.1, U9.8 (OUT1), U9.9 (OUT1), U9.10 (OUT1)
/outputs2/OUT_6: C68.1, D13.1 (K), J5.5, R90.1, U10.12 (OUT0), U10.13 (OUT0), U10.14 (OUT0)
/outputs2/OUT_7: C67.1, D12.1 (K), J5.6, R91.1, U10.8 (OUT1), U10.9 (OUT1), U10.10 (OUT1)
DEN0: R10.1; also elsewhere on the board
DEN1: R14.1; also elsewhere on the board
DEN2: R18.1; also elsewhere on the board
DEN3: R22.1; also elsewhere on the board
DRV_OUT0: R9.1; also elsewhere on the board
DRV_OUT1: R12.1; also elsewhere on the board
DRV_OUT2: R13.1; also elsewhere on the board
DRV_OUT3: R16.1; also elsewhere on the board
DRV_OUT4: R17.1; also elsewhere on the board
DRV_OUT5: R20.1; also elsewhere on the board
DRV_OUT6: R21.1; also elsewhere on the board
DRV_OUT7: R24.1; also elsewhere on the board
DSELn: R11.1, R15.1, R19.1, R23.1; also elsewhere on the board
EN_M0: U14.1 (EN/IN1); also elsewhere on the board
EN_M1: U1.1 (EN/IN1); also elsewhere on the board
FAULTMn: R53.2, U1.4 (nFAULT), U14.4 (nFAULT); also elsewhere on the board
GND: C48.2, C49.2, C51.2, C55.2, C56.2, C57.2, C58.2, C59.2, C60.2, C61.2, C62.2, C63.2, C64.2, C65.2, C66.2, C67.2, C68.2, D2.2 (A), D4.2 (A), D5.2 (A), D8.2 (A), D9.2 (A), D10.2 (A), D11.2 (A), D12.2 (A), D13.2 (A), D36.1 (K), D37.1 (K), D38.1 (K), D39.1 (K), D40.1 (K), D41.1 (K), D42.1 (K), D43.1 (K), J3.2, J5.2, J6.2, R25.1, R54.2, R56.2, R57.2, R59.2, R61.2, U1.7 (IMODE), U1.9 (PGND), U1.15 (GND), U1.17 (EP), U8.1 (GND), U9.1 (GND), U10.1 (GND), U11.1 (GND), U14.7 (IMODE), U14.9 (PGND), U14.15 (GND), U14.17 (EP); also elsewhere on the board
IPROPIM0: C49.1, R57.1, U14.6 (IPROPI); also elsewhere on the board
IPROPIM1: C48.1, R56.1, U1.6 (IPROPI); also elsewhere on the board
ISENSE: R25.2, R26.2, U8.4 (IS), U9.4 (IS), U10.4 (IS), U11.4 (IS)
ISENSE_PROT: D5.1 (K), R26.1; also elsewhere on the board
unnamed: D36.2 (A), R84.2
unnamed: D37.2 (A), R85.2
unnamed: D38.2 (A), R86.2
unnamed: D39.2 (A), R87.2
unnamed: D40.2 (A), R88.2
unnamed: D41.2 (A), R89.2
unnamed: D42.2 (A), R90.2
unnamed: D43.2 (A), R91.2
unnamed: C53.2, U1.13 (CPH)
unnamed: C53.1, U1.14 (CPL)
unnamed: R60.2, R61.1, U1.16 (PMODE)
unnamed: C54.1, U1.12 (VCP)
unnamed: C51.1, R54.1, R55.2, U1.5 (VREF), U14.5 (VREF)
unnamed: R14.2, U8.3 (DEN)
unnamed: R15.2, U8.5 (DSEL)
unnamed: R13.2, U8.2 (IN0)
unnamed: R16.2, U8.6 (IN1)
unnamed: R18.2, U9.3 (DEN)
unnamed: R19.2, U9.5 (DSEL)
unnamed: R17.2, U9.2 (IN0)
unnamed: R20.2, U9.6 (IN1)
unnamed: R22.2, U10.3 (DEN)
unnamed: R23.2, U10.5 (DSEL)
unnamed: R21.2, U10.2 (IN0)
unnamed: R24.2, U10.6 (IN1)
unnamed: R10.2, U11.3 (DEN)
unnamed: R11.2, U11.5 (DSEL)
unnamed: R9.2, U11.2 (IN0)
unnamed: R12.2, U11.6 (IN1)
unnamed: C50.2, U14.13 (CPH)
unnamed: C50.1, U14.14 (CPL)
unnamed: R58.2, R59.1, U14.16 (PMODE)
unnamed: C52.1, U14.12 (VCP)
PH_M0: U14.2 (PH/IN2); also elsewhere on the board
PH_M1: U1.2 (PH/IN2); also elsewhere on the board
nSLEEPMn: U1.3 (nSLEEP), U14.3 (nSLEEP); also elsewhere on the board

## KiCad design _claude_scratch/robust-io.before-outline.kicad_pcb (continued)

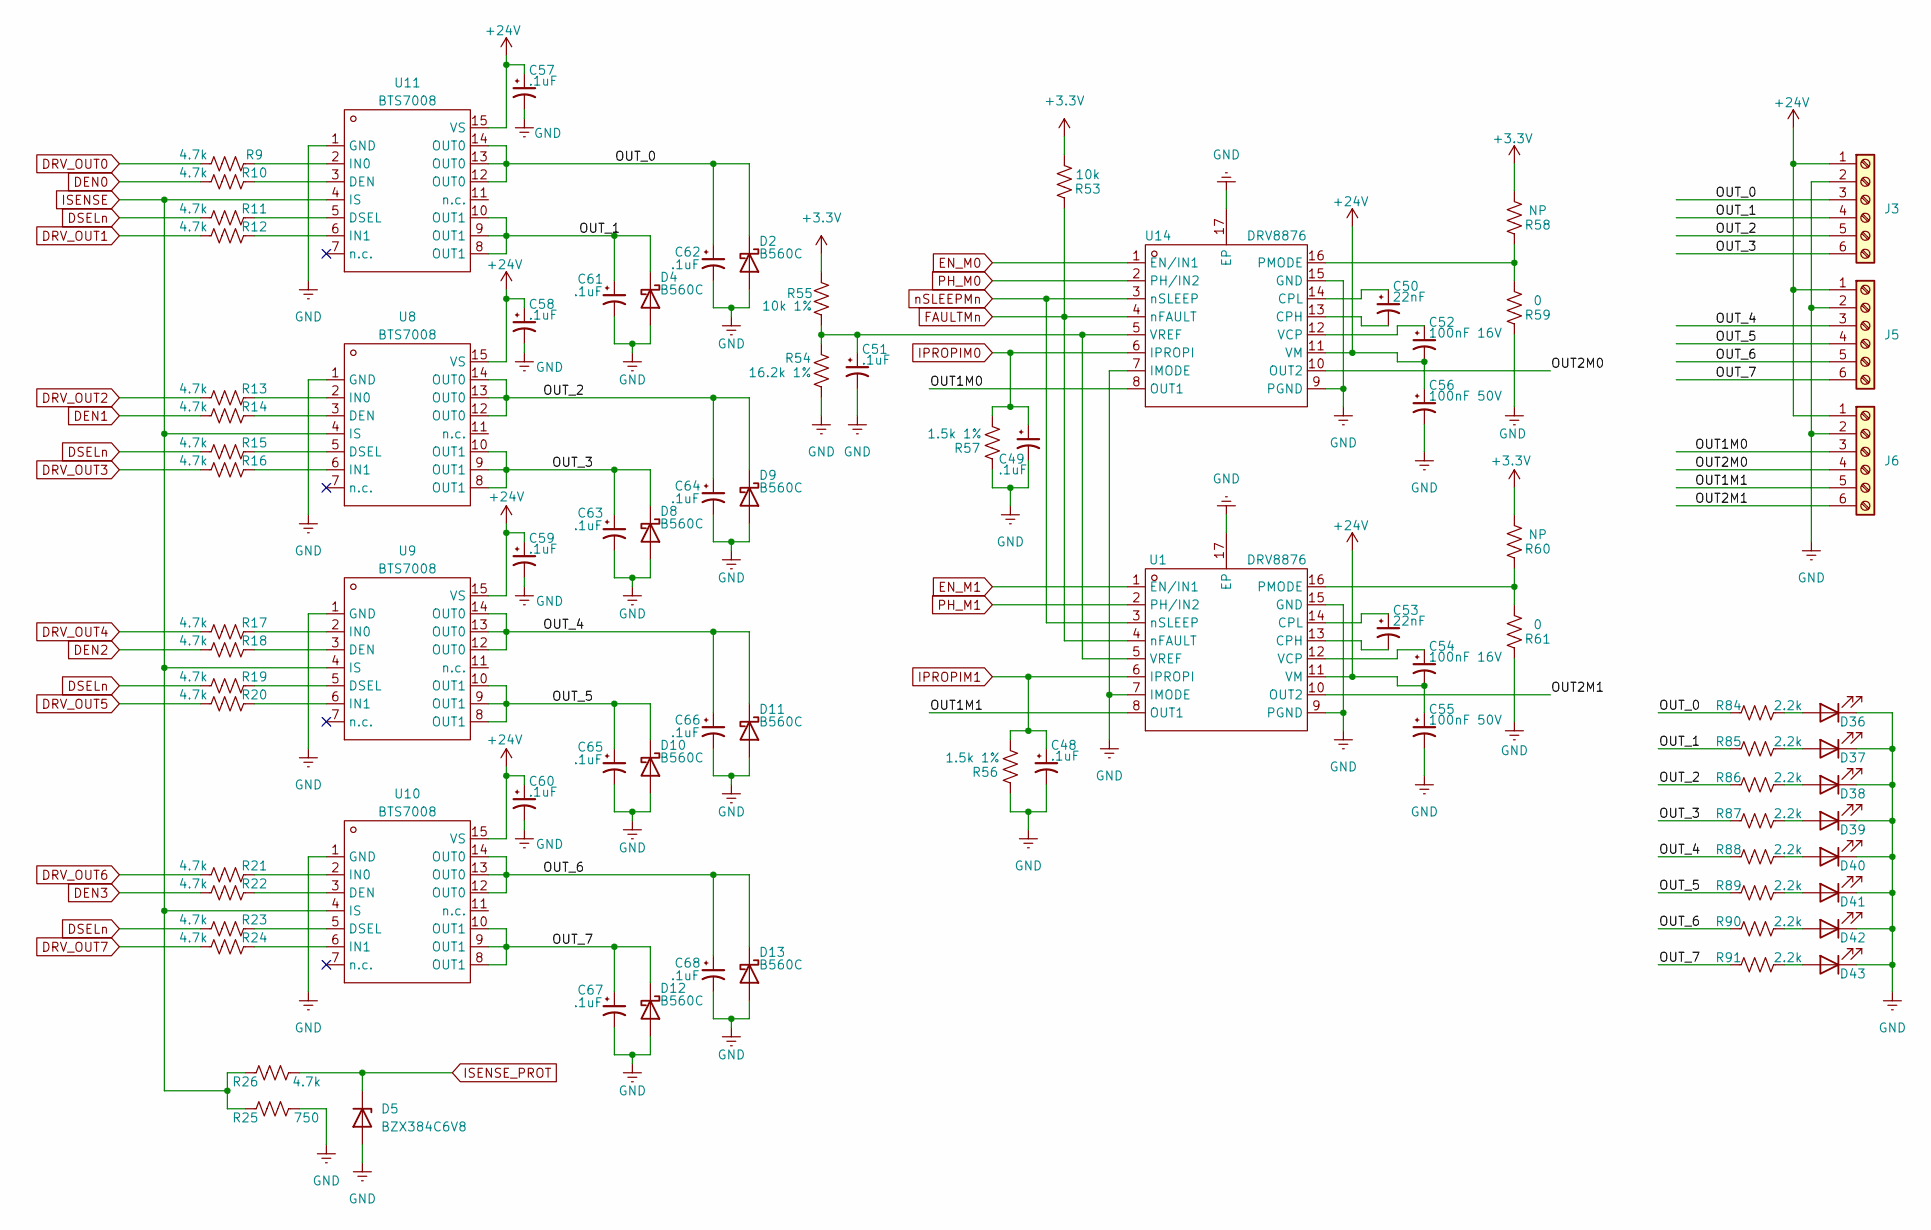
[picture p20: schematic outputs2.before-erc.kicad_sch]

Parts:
C48, C49, C51, C57, C58, C59, C60, C61, C62, C63, C64, C65, C66, C67, C68: .1uF; C_0603_1608Metric_Pad1.08x0.95mm_HandSolder
C50, C53: 22nF; C_0603_1608Metric_Pad1.08x0.95mm_HandSolder
C52, C54: 100nF 16V; C_0603_1608Metric_Pad1.08x0.95mm_HandSolder
C55, C56: 100nF 50V; C_0603_1608Metric_Pad1.08x0.95mm_HandSolder
D2, D4, D8, D9, D10, D11, D12, D13: B560C; D_SMC
D5: BZX384C6V8; D_SOD-323
D36, D37, D38, D39, D40, D41, D42, D43: LED; LED_0603_1608Metric
J3, J5, J6: Screw_Terminal_01x06; PhoenixContact_MSTBA_2,5_6-G-5,08_1x06_P5.08mm_Horizontal
R9, R10, R11, R12, R13, R14, R15, R16, R17, R18, R19, R20, R21, R22, R23, R24, R26: 4.7k; R_0603_1608Metric
R25: 750; R_0603_1608Metric
R53: 10k; R_0603_1608Metric_Pad0.98x0.95mm_HandSolder
R54: 16.2k 1%; R_0603_1608Metric_Pad0.98x0.95mm_HandSolder
R55: 10k 1%; R_0603_1608Metric_Pad0.98x0.95mm_HandSolder
R56, R57: 1.5k 1%; R_0603_1608Metric_Pad0.98x0.95mm_HandSolder
R58, R60: NP; R_0603_1608Metric_Pad0.98x0.95mm_HandSolder
R59, R61: 0; R_0603_1608Metric_Pad0.98x0.95mm_HandSolder
R84, R85, R86, R87, R88, R89, R90, R91: 2.2k; R_0603_1608Metric_Pad0.98x0.95mm_HandSolder
U1, U14: DRV8876; IC_DRV8876PWPR; Manufacturer Part DRV8876PWPR; LCSC Part Name 3.5A 有刷直流电机驱动芯片 5.5V
U8, U9, U10, U11: BTS7008; TSSOP-14-1EP_4.4x5mm_P0.65mm; Manufacturer Part BTS7008-2EPA; LCSC Part Name 12V智能高端功率开关

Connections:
+3.3V: R53.1, R55.1, R58.1, R60.1; also elsewhere on the board
+24V: C52.2, C54.2, C55.1, C56.1, C57.1, C58.1, C59.1, C60.1, J3.1, J5.1, J6.1, U1.11 (VM), U8.15 (VS), U9.15 (VS), U10.15 (VS), U11.15 (VS), U14.11 (VM); also elsewhere on the board
/outputs2/OUT1M0: J6.3, U14.8 (OUT1)
/outputs2/OUT1M1: J6.5, U1.8 (OUT1)
/outputs2/OUT2M0: J6.4, U14.10 (OUT2)
/outputs2/OUT2M1: J6.6, U1.10 (OUT2)
/outputs2/OUT_0: C62.1, D2.1 (K), J3.3, R84.1, U11.12 (OUT0), U11.13 (OUT0), U11.14 (OUT0)
/outputs2/OUT_1: C61.1, D4.1 (K), J3.4, R85.1, U11.8 (OUT1), U11.9 (OUT1), U11.10 (OUT1)
/outputs2/OUT_2: C64.1, D9.1 (K), J3.5, R86.1, U8.12 (OUT0), U8.13 (OUT0), U8.14 (OUT0)
/outputs2/OUT_3: C63.1, D8.1 (K), J3.6, R87.1, U8.8 (OUT1), U8.9 (OUT1), U8.10 (OUT1)
/outputs2/OUT_4: C66.1, D11.1 (K), J5.3, R88.1, U9.12 (OUT0), U9.13 (OUT0), U9.14 (OUT0)
/outputs2/OUT_5: C65.1, D10.1 (K), J5.4, R89.1, U9.8 (OUT1), U9.9 (OUT1), U9.10 (OUT1)
/outputs2/OUT_6: C68.1, D13.1 (K), J5.5, R90.1, U10.12 (OUT0), U10.13 (OUT0), U10.14 (OUT0)
/outputs2/OUT_7: C67.1, D12.1 (K), J5.6, R91.1, U10.8 (OUT1), U10.9 (OUT1), U10.10 (OUT1)
DEN0: R10.1; also elsewhere on the board
DEN1: R14.1; also elsewhere on the board
DEN2: R18.1; also elsewhere on the board
DEN3: R22.1; also elsewhere on the board
DRV_OUT0: R9.1; also elsewhere on the board
DRV_OUT1: R12.1; also elsewhere on the board
DRV_OUT2: R13.1; also elsewhere on the board
DRV_OUT3: R16.1; also elsewhere on the board
DRV_OUT4: R17.1; also elsewhere on the board
DRV_OUT5: R20.1; also elsewhere on the board
DRV_OUT6: R21.1; also elsewhere on the board
DRV_OUT7: R24.1; also elsewhere on the board
DSELn: R11.1, R15.1, R19.1, R23.1; also elsewhere on the board
EN_M0: U14.1 (EN/IN1); also elsewhere on the board
EN_M1: U1.1 (EN/IN1); also elsewhere on the board
FAULTMn: R53.2, U1.4 (nFAULT), U14.4 (nFAULT); also elsewhere on the board
GND: C48.2, C49.2, C51.2, C55.2, C56.2, C57.2, C58.2, C59.2, C60.2, C61.2, C62.2, C63.2, C64.2, C65.2, C66.2, C67.2, C68.2, D2.2 (A), D4.2 (A), D5.2 (A), D8.2 (A), D9.2 (A), D10.2 (A), D11.2 (A), D12.2 (A), D13.2 (A), D36.1 (K), D37.1 (K), D38.1 (K), D39.1 (K), D40.1 (K), D41.1 (K), D42.1 (K), D43.1 (K), J3.2, J5.2, J6.2, R25.1, R54.2, R56.2, R57.2, R59.2, R61.2, U1.7 (IMODE), U1.9 (PGND), U1.15 (GND), U1.17 (EP), U8.1 (GND), U9.1 (GND), U10.1 (GND), U11.1 (GND), U14.7 (IMODE), U14.9 (PGND), U14.15 (GND), U14.17 (EP); also elsewhere on the board
IPROPIM0: C49.1, R57.1, U14.6 (IPROPI); also elsewhere on the board
IPROPIM1: C48.1, R56.1, U1.6 (IPROPI); also elsewhere on the board
ISENSE: R25.2, R26.2, U8.4 (IS), U9.4 (IS), U10.4 (IS), U11.4 (IS)
ISENSE_PROT: D5.1 (K), R26.1; also elsewhere on the board
unnamed: D36.2 (A), R84.2
unnamed: D37.2 (A), R85.2
unnamed: D38.2 (A), R86.2
unnamed: D39.2 (A), R87.2
unnamed: D40.2 (A), R88.2
unnamed: D41.2 (A), R89.2
unnamed: D42.2 (A), R90.2
unnamed: D43.2 (A), R91.2
unnamed: C53.2, U1.13 (CPH)
unnamed: C53.1, U1.14 (CPL)
unnamed: R60.2, R61.1, U1.16 (PMODE)
unnamed: C54.1, U1.12 (VCP)
unnamed: C51.1, R54.1, R55.2, U1.5 (VREF), U14.5 (VREF)
unnamed: R14.2, U8.3 (DEN)
unnamed: R15.2, U8.5 (DSEL)
unnamed: R13.2, U8.2 (IN0)
unnamed: R16.2, U8.6 (IN1)
unnamed: R18.2, U9.3 (DEN)
unnamed: R19.2, U9.5 (DSEL)
unnamed: R17.2, U9.2 (IN0)
unnamed: R20.2, U9.6 (IN1)
unnamed: R22.2, U10.3 (DEN)
unnamed: R23.2, U10.5 (DSEL)
unnamed: R21.2, U10.2 (IN0)
unnamed: R24.2, U10.6 (IN1)
unnamed: R10.2, U11.3 (DEN)
unnamed: R11.2, U11.5 (DSEL)
unnamed: R9.2, U11.2 (IN0)
unnamed: R12.2, U11.6 (IN1)
unnamed: C50.2, U14.13 (CPH)
unnamed: C50.1, U14.14 (CPL)
unnamed: R58.2, R59.1, U14.16 (PMODE)
unnamed: C52.1, U14.12 (VCP)
PH_M0: U14.2 (PH/IN2); also elsewhere on the board
PH_M1: U1.2 (PH/IN2); also elsewhere on the board
nSLEEPMn: U1.3 (nSLEEP), U14.3 (nSLEEP); also elsewhere on the board

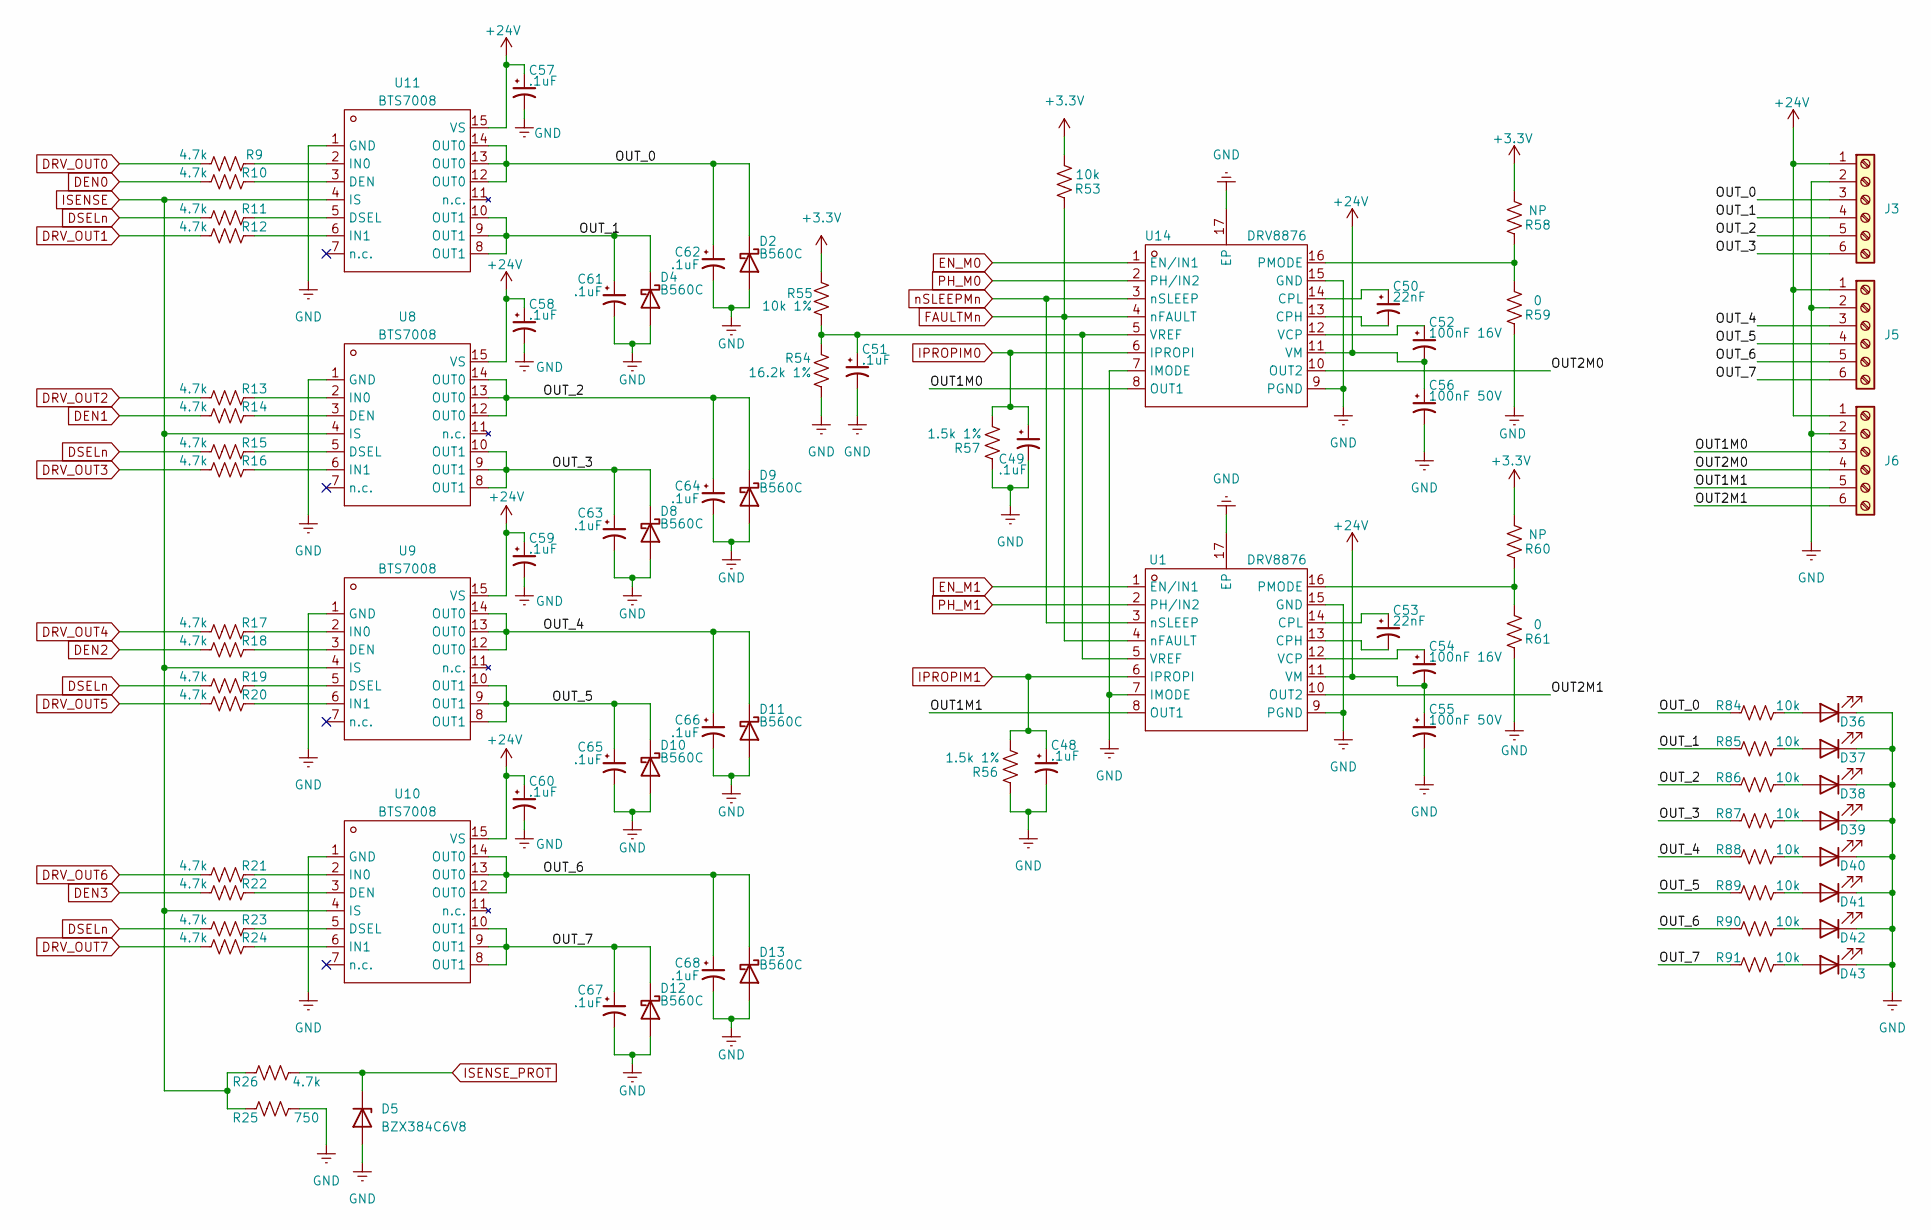
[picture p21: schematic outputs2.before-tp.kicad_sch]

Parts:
C48, C49, C51, C57, C58, C59, C60, C61, C62, C63, C64, C65, C66, C67, C68: .1uF; C_0603_1608Metric_Pad1.08x0.95mm_HandSolder
C50, C53: 22nF; C_0603_1608Metric_Pad1.08x0.95mm_HandSolder
C52, C54: 100nF 16V; C_0603_1608Metric_Pad1.08x0.95mm_HandSolder
C55, C56: 100nF 50V; C_0603_1608Metric_Pad1.08x0.95mm_HandSolder
D2, D4, D8, D9, D10, D11, D12, D13: B560C; D_SMC
D5: BZX384C6V8; D_SOD-323
D36, D37, D38, D39, D40, D41, D42, D43: LED; LED_0603_1608Metric
J3, J5, J6: Screw_Terminal_01x06; PhoenixContact_MSTBA_2,5_6-G-5,08_1x06_P5.08mm_Horizontal
R9, R10, R11, R12, R13, R14, R15, R16, R17, R18, R19, R20, R21, R22, R23, R24, R26: 4.7k; R_0603_1608Metric
R25: 750; R_0603_1608Metric
R53, R84, R85, R86, R87, R88, R89, R90, R91: 10k; R_0603_1608Metric_Pad0.98x0.95mm_HandSolder
R54: 16.2k 1%; R_0603_1608Metric_Pad0.98x0.95mm_HandSolder
R55: 10k 1%; R_0603_1608Metric_Pad0.98x0.95mm_HandSolder
R56, R57: 1.5k 1%; R_0603_1608Metric_Pad0.98x0.95mm_HandSolder
R58, R60: NP; R_0603_1608Metric_Pad0.98x0.95mm_HandSolder
R59, R61: 0; R_0603_1608Metric_Pad0.98x0.95mm_HandSolder
U1, U14: DRV8876; IC_DRV8876PWPR; Manufacturer Part DRV8876PWPR; LCSC Part Name 3.5A 有刷直流电机驱动芯片 5.5V
U8, U9, U10, U11: BTS7008; TSSOP-14-1EP_4.4x5mm_P0.65mm; Manufacturer Part BTS7008-2EPA; LCSC Part Name 12V智能高端功率开关

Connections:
+3.3V: R53.1, R55.1, R58.1, R60.1; also elsewhere on the board
+24V: C52.2, C54.2, C55.1, C56.1, C57.1, C58.1, C59.1, C60.1, J3.1, J5.1, J6.1, U1.11 (VM), U8.15 (VS), U9.15 (VS), U10.15 (VS), U11.15 (VS), U14.11 (VM); also elsewhere on the board
/outputs2/OUT1M0: J6.3, U14.8 (OUT1)
/outputs2/OUT1M1: J6.5, U1.8 (OUT1)
/outputs2/OUT2M0: J6.4, U14.10 (OUT2)
/outputs2/OUT2M1: J6.6, U1.10 (OUT2)
/outputs2/OUT_0: C62.1, D2.1 (K), J3.3, R84.1, U11.12 (OUT0), U11.13 (OUT0), U11.14 (OUT0)
/outputs2/OUT_1: C61.1, D4.1 (K), J3.4, R85.1, U11.8 (OUT1), U11.9 (OUT1), U11.10 (OUT1)
/outputs2/OUT_2: C64.1, D9.1 (K), J3.5, R86.1, U8.12 (OUT0), U8.13 (OUT0), U8.14 (OUT0)
/outputs2/OUT_3: C63.1, D8.1 (K), J3.6, R87.1, U8.8 (OUT1), U8.9 (OUT1), U8.10 (OUT1)
/outputs2/OUT_4: C66.1, D11.1 (K), J5.3, R88.1, U9.12 (OUT0), U9.13 (OUT0), U9.14 (OUT0)
/outputs2/OUT_5: C65.1, D10.1 (K), J5.4, R89.1, U9.8 (OUT1), U9.9 (OUT1), U9.10 (OUT1)
/outputs2/OUT_6: C68.1, D13.1 (K), J5.5, R90.1, U10.12 (OUT0), U10.13 (OUT0), U10.14 (OUT0)
/outputs2/OUT_7: C67.1, D12.1 (K), J5.6, R91.1, U10.8 (OUT1), U10.9 (OUT1), U10.10 (OUT1)
DEN0: R10.1; also elsewhere on the board
DEN1: R14.1; also elsewhere on the board
DEN2: R18.1; also elsewhere on the board
DEN3: R22.1; also elsewhere on the board
DRV_OUT0: R9.1; also elsewhere on the board
DRV_OUT1: R12.1; also elsewhere on the board
DRV_OUT2: R13.1; also elsewhere on the board
DRV_OUT3: R16.1; also elsewhere on the board
DRV_OUT4: R17.1; also elsewhere on the board
DRV_OUT5: R20.1; also elsewhere on the board
DRV_OUT6: R21.1; also elsewhere on the board
DRV_OUT7: R24.1; also elsewhere on the board
DSELn: R11.1, R15.1, R19.1, R23.1; also elsewhere on the board
EN_M0: U14.1 (EN/IN1); also elsewhere on the board
EN_M1: U1.1 (EN/IN1); also elsewhere on the board
FAULTMn: R53.2, U1.4 (nFAULT), U14.4 (nFAULT); also elsewhere on the board
GND: C48.2, C49.2, C51.2, C55.2, C56.2, C57.2, C58.2, C59.2, C60.2, C61.2, C62.2, C63.2, C64.2, C65.2, C66.2, C67.2, C68.2, D2.2 (A), D4.2 (A), D5.2 (A), D8.2 (A), D9.2 (A), D10.2 (A), D11.2 (A), D12.2 (A), D13.2 (A), D36.1 (K), D37.1 (K), D38.1 (K), D39.1 (K), D40.1 (K), D41.1 (K), D42.1 (K), D43.1 (K), J3.2, J5.2, J6.2, R25.1, R54.2, R56.2, R57.2, R59.2, R61.2, U1.7 (IMODE), U1.9 (PGND), U1.15 (GND), U1.17 (EP), U8.1 (GND), U9.1 (GND), U10.1 (GND), U11.1 (GND), U14.7 (IMODE), U14.9 (PGND), U14.15 (GND), U14.17 (EP); also elsewhere on the board
IPROPIM0: C49.1, R57.1, U14.6 (IPROPI); also elsewhere on the board
IPROPIM1: C48.1, R56.1, U1.6 (IPROPI); also elsewhere on the board
ISENSE: R25.2, R26.2, U8.4 (IS), U9.4 (IS), U10.4 (IS), U11.4 (IS)
ISENSE_PROT: D5.1 (K), R26.1; also elsewhere on the board
unnamed: D36.2 (A), R84.2
unnamed: D37.2 (A), R85.2
unnamed: D38.2 (A), R86.2
unnamed: D39.2 (A), R87.2
unnamed: D40.2 (A), R88.2
unnamed: D41.2 (A), R89.2
unnamed: D42.2 (A), R90.2
unnamed: D43.2 (A), R91.2
unnamed: C53.2, U1.13 (CPH)
unnamed: C53.1, U1.14 (CPL)
unnamed: R60.2, R61.1, U1.16 (PMODE)
unnamed: C54.1, U1.12 (VCP)
unnamed: C51.1, R54.1, R55.2, U1.5 (VREF), U14.5 (VREF)
unnamed: R14.2, U8.3 (DEN)
unnamed: R15.2, U8.5 (DSEL)
unnamed: R13.2, U8.2 (IN0)
unnamed: R16.2, U8.6 (IN1)
unnamed: R18.2, U9.3 (DEN)
unnamed: R19.2, U9.5 (DSEL)
unnamed: R17.2, U9.2 (IN0)
unnamed: R20.2, U9.6 (IN1)
unnamed: R22.2, U10.3 (DEN)
unnamed: R23.2, U10.5 (DSEL)
unnamed: R21.2, U10.2 (IN0)
unnamed: R24.2, U10.6 (IN1)
unnamed: R10.2, U11.3 (DEN)
unnamed: R11.2, U11.5 (DSEL)
unnamed: R9.2, U11.2 (IN0)
unnamed: R12.2, U11.6 (IN1)
unnamed: C50.2, U14.13 (CPH)
unnamed: C50.1, U14.14 (CPL)
unnamed: R58.2, R59.1, U14.16 (PMODE)
unnamed: C52.1, U14.12 (VCP)
PH_M0: U14.2 (PH/IN2); also elsewhere on the board
PH_M1: U1.2 (PH/IN2); also elsewhere on the board
nSLEEPMn: U1.3 (nSLEEP), U14.3 (nSLEEP); also elsewhere on the board

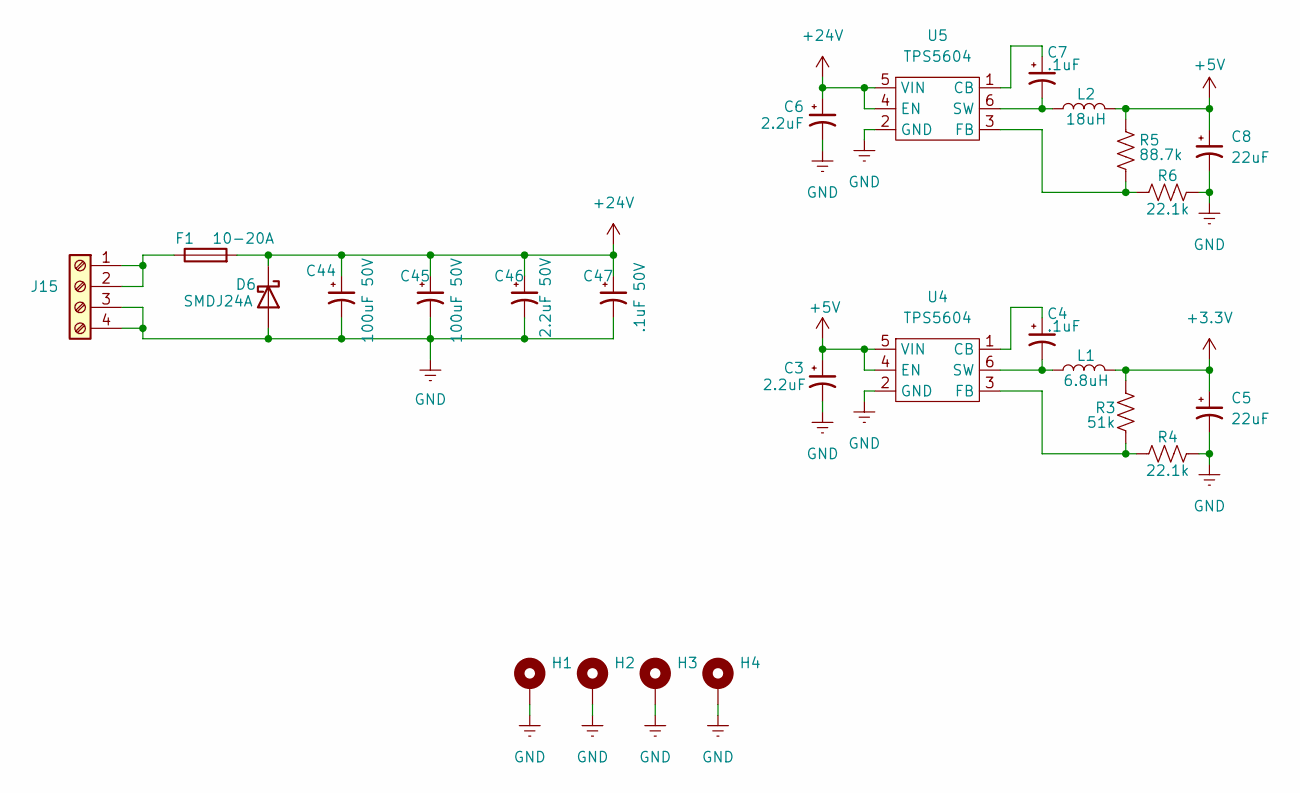
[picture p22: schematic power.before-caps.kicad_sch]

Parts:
C3, C6: 2.2uF; C_0805_2012Metric_Pad1.18x1.45mm_HandSolder
C4, C7: .1uF; C_0603_1608Metric_Pad1.08x0.95mm_HandSolder
C5, C8: 22uF; C_0603_1608Metric_Pad1.08x0.95mm_HandSolder
C44, C45: 100uF 50V; C_0805_2012Metric_Pad1.18x1.45mm_HandSolder
C46: 2.2uF 50V; C_0805_2012Metric_Pad1.18x1.45mm_HandSolder
C47: .1uF 50V; C_0805_2012Metric_Pad1.18x1.45mm_HandSolder
D6: SMDJ24A; D_SMC
F1: 10-20A; Fuseholder_Blade_Mini_Keystone_3568
H1, H2, H3, H4: MountingHole_Pad; MountingHole_3.2mm_M3_DIN965_Pad_TopBottom
J15: Screw_Terminal_01x04; PhoenixContact_MSTBA_2,5_4-G-5,08_1x04_P5.08mm_Horizontal
L1: 6.8uH; L_0805_2012Metric_Pad1.05x1.20mm_HandSolder; Part Number CB2016T6R8M
L2: 18uH; L_0805_2012Metric
R3: 51k; R_0603_1608Metric_Pad0.98x0.95mm_HandSolder
R4, R6: 22.1k; R_0603_1608Metric_Pad0.98x0.95mm_HandSolder
R5: 88.7k; R_0603_1608Metric_Pad0.98x0.95mm_HandSolder
U4, U5: TPS5604; SOT-23-6

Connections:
+3.3V: C5.1, L1.2, R3.1; also elsewhere on the board
+5V: C3.1, C8.1, L2.2, R5.1, U4.4 (EN), U4.5 (VIN); also elsewhere on the board
+24V: C6.1, C44.1, C45.1, C46.1, C47.1, D6.1 (K), F1.2, U5.4 (EN), U5.5 (VIN); also elsewhere on the board
GND: C3.2, C5.2, C6.2, C8.2, C44.2, C45.2, C46.2, C47.2, D6.2 (A), H1.1 (1_1), H2.1 (1_1), H3.1 (1_1), H4.1 (1_1), J15.3, J15.4, R4.1, R6.1, U4.2 (GND), U5.2 (GND); also elsewhere on the board
unnamed: F1.1, J15.1, J15.2
unnamed: C4.1, U4.1 (CB)
unnamed: R3.2, R4.2, U4.3 (FB)
unnamed: C4.2, L1.1, U4.6 (SW)
unnamed: C7.1, U5.1 (CB)
unnamed: R5.2, R6.2, U5.3 (FB)
unnamed: C7.2, L2.1, U5.6 (SW)


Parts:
C3, C6: 2.2uF; C_0805_2012Metric_Pad1.18x1.45mm_HandSolder
C4, C7: .1uF; C_0603_1608Metric_Pad1.08x0.95mm_HandSolder
C5, C8: 22uF; C_0603_1608Metric_Pad1.08x0.95mm_HandSolder
C44, C45: 100uF 50V; CP_Elec_8x10
C46: 2.2uF 50V; C_0805_2012Metric_Pad1.18x1.45mm_HandSolder
C47: .1uF 50V; C_0805_2012Metric_Pad1.18x1.45mm_HandSolder
D6: SMDJ24A; D_SMC
F1: 10-20A; Fuseholder_Blade_Mini_Keystone_3568
H1, H2, H3, H4: MountingHole_Pad; MountingHole_3.2mm_M3_DIN965_Pad_TopBottom
J15: Screw_Terminal_01x04; PhoenixContact_MSTBA_2,5_4-G-5,08_1x04_P5.08mm_Horizontal
L1: 6.8uH; L_0805_2012Metric_Pad1.05x1.20mm_HandSolder; Part Number CB2016T6R8M
L2: 18uH; L_0805_2012Metric
R3: 51k; R_0603_1608Metric_Pad0.98x0.95mm_HandSolder
R4, R6: 22.1k; R_0603_1608Metric_Pad0.98x0.95mm_HandSolder
R5: 88.7k; R_0603_1608Metric_Pad0.98x0.95mm_HandSolder
U4, U5: TPS5604; SOT-23-6

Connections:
+3.3V: C5.1, L1.2, R3.1; also elsewhere on the board
+5V: C3.1, C8.1, L2.2, R5.1, U4.4 (EN), U4.5 (VIN); also elsewhere on the board
+24V: C6.1, C44.1, C45.1, C46.1, C47.1, D6.1 (K), F1.2, U5.4 (EN), U5.5 (VIN); also elsewhere on the board
GND: C3.2, C5.2, C6.2, C8.2, C44.2, C45.2, C46.2, C47.2, D6.2 (A), H1.1 (1_1), H2.1 (1_1), H3.1 (1_1), H4.1 (1_1), J15.3, J15.4, R4.1, R6.1, U4.2 (GND), U5.2 (GND); also elsewhere on the board
unnamed: F1.1, J15.1, J15.2
unnamed: C4.1, U4.1 (CB)
unnamed: R3.2, R4.2, U4.3 (FB)
unnamed: C4.2, L1.1, U4.6 (SW)
unnamed: C7.1, U5.1 (CB)
unnamed: R5.2, R6.2, U5.3 (FB)
unnamed: C7.2, L2.1, U5.6 (SW)

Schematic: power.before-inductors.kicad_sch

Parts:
C3, C6: 2.2uF; C_0805_2012Metric_Pad1.18x1.45mm_HandSolder
C4, C7: .1uF; C_0603_1608Metric_Pad1.08x0.95mm_HandSolder
C5, C8: 22uF; C_0603_1608Metric_Pad1.08x0.95mm_HandSolder
C44, C45: 100uF 50V; CP_Elec_8x10
C46: 2.2uF 50V; C_0805_2012Metric_Pad1.18x1.45mm_HandSolder
C47: .1uF 50V; C_0805_2012Metric_Pad1.18x1.45mm_HandSolder
D6: SMDJ24A; D_SMC
F1: 10-20A; Fuseholder_Blade_Mini_Keystone_3568
H1, H2, H3, H4: MountingHole_Pad; MountingHole_3.2mm_M3_DIN965_Pad_TopBottom
J15: Screw_Terminal_01x04; PhoenixContact_MSTBA_2,5_4-G-5,08_1x04_P5.08mm_Horizontal
L1: 6.8uH; L_0805_2012Metric_Pad1.05x1.20mm_HandSolder; Part Number CB2016T6R8M
L2: 18uH; L_0805_2012Metric
R3: 51k; R_0603_1608Metric_Pad0.98x0.95mm_HandSolder
R4, R6: 22.1k; R_0603_1608Metric_Pad0.98x0.95mm_HandSolder
R5: 88.7k; R_0603_1608Metric_Pad0.98x0.95mm_HandSolder
U4, U5: TPS5604; SOT-23-6

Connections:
+3.3V: C5.1, L1.2, R3.1; also elsewhere on the board
+5V: C3.1, C8.1, L2.2, R5.1, U4.4 (EN), U4.5 (VIN); also elsewhere on the board
+24V: C6.1, C44.1, C45.1, C46.1, C47.1, D6.1 (K), F1.2, U5.4 (EN), U5.5 (VIN); also elsewhere on the board
GND: C3.2, C5.2, C6.2, C8.2, C44.2, C45.2, C46.2, C47.2, D6.2 (A), H1.1 (1_1), H2.1 (1_1), H3.1 (1_1), H4.1 (1_1), J15.3, J15.4, R4.1, R6.1, U4.2 (GND), U5.2 (GND); also elsewhere on the board
unnamed: F1.1, J15.1, J15.2
unnamed: C4.1, U4.1 (CB)
unnamed: R3.2, R4.2, U4.3 (FB)
unnamed: C4.2, L1.1, U4.6 (SW)
unnamed: C7.1, U5.1 (CB)
unnamed: R5.2, R6.2, U5.3 (FB)
unnamed: C7.2, L2.1, U5.6 (SW)

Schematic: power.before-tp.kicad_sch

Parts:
C3, C6: 2.2uF; C_0805_2012Metric_Pad1.18x1.45mm_HandSolder
C4, C7: .1uF; C_0603_1608Metric_Pad1.08x0.95mm_HandSolder
C5, C8: 22uF; C_0603_1608Metric_Pad1.08x0.95mm_HandSolder
C44, C45: 100uF 50V; CP_Elec_8x10
C46: 2.2uF 50V; C_0805_2012Metric_Pad1.18x1.45mm_HandSolder
C47: .1uF 50V; C_0805_2012Metric_Pad1.18x1.45mm_HandSolder
D6: SMDJ24A; D_SMC
F1: 10-20A; Fuseholder_Blade_Mini_Keystone_3568
H1, H2, H3, H4: MountingHole_Pad; MountingHole_3.2mm_M3_DIN965_Pad_TopBottom
J15: Screw_Terminal_01x04; PhoenixContact_MSTBA_2,5_4-G-5,08_1x04_P5.08mm_Horizontal
L1: 6.8uH; L_Sunlord_SWPA4030S; Part Number CB2016T6R8M
L2: 18uH; L_Sunlord_SWPA4030S
R3: 51k; R_0603_1608Metric_Pad0.98x0.95mm_HandSolder
R4, R6: 22.1k; R_0603_1608Metric_Pad0.98x0.95mm_HandSolder
R5: 88.7k; R_0603_1608Metric_Pad0.98x0.95mm_HandSolder
U4, U5: TPS5604; SOT-23-6

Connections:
+3.3V: C5.1, L1.2, R3.1; also elsewhere on the board
+5V: C3.1, C8.1, L2.2, R5.1, U4.4 (EN), U4.5 (VIN); also elsewhere on the board
+24V: C6.1, C44.1, C45.1, C46.1, C47.1, D6.1 (K), F1.2, U5.4 (EN), U5.5 (VIN); also elsewhere on the board
GND: C3.2, C5.2, C6.2, C8.2, C44.2, C45.2, C46.2, C47.2, D6.2 (A), H1.1 (1_1), H2.1 (1_1), H3.1 (1_1), H4.1 (1_1), J15.3, J15.4, R4.1, R6.1, U4.2 (GND), U5.2 (GND); also elsewhere on the board
unnamed: F1.1, J15.1, J15.2
unnamed: C4.1, U4.1 (CB)
unnamed: R3.2, R4.2, U4.3 (FB)
unnamed: C4.2, L1.1, U4.6 (SW)
unnamed: C7.1, U5.1 (CB)
unnamed: R5.2, R6.2, U5.3 (FB)
unnamed: C7.2, L2.1, U5.6 (SW)

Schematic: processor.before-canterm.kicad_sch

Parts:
C1, C2, C11, C12: 22pF; C_0603_1608Metric
C9, C10, C13, C14, C15, C71, C72, C73: .1uF; C_0603_1608Metric
C16: 1nF; C_0603_1608Metric
C69, C70: 10nF; C_0603_1608Metric
D1, D3: BAT54C; SOT-23
D44, D46: 1N4148W; D_SOD-123
D45, D47: LED; LED_0603_1608Metric
J1: AVR-ISP-6; PinHeader_2x03_P2.54mm_Vertical_SMD
J4: Screw_Terminal_01x04; PhoenixContact_MSTBA_2,5_4-G-5,08_1x04_P5.08mm_Horizontal
L3: 10uH; C_0603_1608Metric
Q3, Q4: 2N7002; SOT-23
R1, R7: 10k; R_0603_1608Metric_Pad0.98x0.95mm_HandSolder
R2: 120; R_0603_1608Metric_Pad0.98x0.95mm_HandSolder
R8, R93, R97: 330; R_0603_1608Metric_Pad0.98x0.95mm_HandSolder
R27: 4.7k; R_0603_1608Metric_Pad0.98x0.95mm_HandSolder
R92, R95: 100k; R_0603_1608Metric_Pad0.98x0.95mm_HandSolder
SW2: B3U-1000P; SW_SPST_B3U-1000P
U2: ATmega1284P-A; TQFP-44_10x10mm_P0.8mm
U3: MCP2515; QFN-20-1EP_4x4mm_P0.5mm_EP2.5x2.5mm
U6: MCP2562-E-MF; DFN-8-1EP_3x3mm_P0.65mm_EP1.6x2.56mm
Y1: 16MHz; WE-XTAL_CFPX-180
Y2: 12MHz; WE-XTAL_CFPX-180

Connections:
+3.3V: C9.1, C15.1, C72.1, C73.1, D1.3, D3.3, J1.2 (VCC), L3.1, R1.1, R7.1, R93.2, R97.2, U2.5 (VCC), U2.17 (VCC), U2.38 (VCC), U3.18 (VDD), U6.5 (Vio); also elsewhere on the board
+5V: J4.3, U6.3 (VDD); also elsewhere on the board
/processor/CS_CAN: U2.40 (PB0), U3.16 (~CS)
/processor/INT_CAN0: U2.11 (PD2), U3.11 (~INT)
/processor/RST: C13.1, J1.5 (~RST), R7.2, SW2.1 (A), U2.4 (~RESET)
/processor/RX0: C69.1, U2.9 (PD0); also elsewhere on the board
/processor/TX0: C70.1, U2.10 (PD1); also elsewhere on the board
AMUX0: D1.1, U2.37 (PA0); also elsewhere on the board
CS_IN0: U2.41 (PB1); also elsewhere on the board
DEN0: U2.43 (PB3); also elsewhere on the board
DEN1: U2.44 (PB4); also elsewhere on the board
DEN2: U2.33 (PA4); also elsewhere on the board
DEN3: U2.32 (PA5); also elsewhere on the board
DRV_OUT0: U2.19 (PC0); also elsewhere on the board
DRV_OUT1: U2.20 (PC1); also elsewhere on the board
DRV_OUT2: U2.21 (PC2); also elsewhere on the board
DRV_OUT3: U2.22 (PC3); also elsewhere on the board
DRV_OUT4: U2.23 (PC4); also elsewhere on the board
DRV_OUT5: U2.24 (PC5); also elsewhere on the board
DRV_OUT6: U2.25 (PC6); also elsewhere on the board
DRV_OUT7: U2.26 (PC7); also elsewhere on the board
DSELn: U2.31 (PA6); also elsewhere on the board
EN_M0: U2.14 (PD5); also elsewhere on the board
EN_M1: U2.16 (PD7); also elsewhere on the board
FAULTMn: U2.12 (PD3); also elsewhere on the board
GND: C1.2, C2.2, C9.2, C10.2, C11.2, C12.2, C13.2, C14.2, C15.2, C16.2, C71.2, C72.2, C73.2, D44.2 (A), D46.2 (A), J1.6 (GND), J4.4, Q3.2 (S), Q4.2 (S), R8.1, R92.1, R95.1, U2.6 (GND), U2.18 (GND), U2.28 (GND), U2.39 (GND), U3.8 (VSS), U6.2 (VSS), U6.8 (SHDN), U6.9 (PAD); also elsewhere on the board
INT_B0: U2.42 (PB2); also elsewhere on the board
IPROPIM0: D3.2, U2.35 (PA2); also elsewhere on the board
IPROPIM1: D3.1, U2.34 (PA3); also elsewhere on the board
ISENSE_PROT: R27.2; also elsewhere on the board
MISO0: J1.1 (MISO), U2.2 (PB6), U3.15 (SO); also elsewhere on the board
MOSI0: J1.4 (MOSI), U2.1 (PB5), U3.14 (SI); also elsewhere on the board
unnamed: C69.2, D44.1 (K), Q3.1 (G), R92.2
unnamed: D45.2 (A), R93.1
unnamed: D45.1 (K), Q3.3 (D)
unnamed: C70.2, D46.1 (K), Q4.1 (G), R95.2
unnamed: D47.2 (A), R97.1
unnamed: D47.1 (K), Q4.3 (D)
unnamed: J4.2, R2.2, U6.6 (CANL)
unnamed: R8.2, SW2.2 (B)
unnamed: C14.1, U2.29 (AREF)
unnamed: C10.1, C71.1, L3.2, U2.27 (AVCC)
unnamed: C16.1, D1.2, R27.1, U2.36 (PA1)
unnamed: C12.1, U2.8 (XTAL1), Y2.1
unnamed: C11.1, U2.7 (XTAL2), Y2.3
unnamed: C2.1, U3.7 (OSC1), Y1.3
unnamed: C1.1, U3.6 (OSC2), Y1.1
unnamed: U3.20 (RXCAN), U6.4 (RXD)
unnamed: U3.19 (TXCAN), U6.1 (TXD)
unnamed: R1.2, U3.17 (~RESET)
PH_M0: U2.13 (PD4); also elsewhere on the board
PH_M1: U2.15 (PD6); also elsewhere on the board
SCLK0: J1.3 (SCK), U2.3 (PB7), U3.12 (SCK); also elsewhere on the board
nSLEEPMn: U2.30 (PA7); also elsewhere on the board

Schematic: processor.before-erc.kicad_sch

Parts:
C1, C2, C11, C12: 22pF; C_0603_1608Metric
C9, C10, C13, C14, C15, C71, C72, C73: .1uF; C_0603_1608Metric
C16: 1nF; C_0603_1608Metric
C69, C70: 10nF; C_0603_1608Metric
D1, D3: BAT54C; SOT-23
D44, D46: 1N4148W; D_SOD-123
D45, D47: LED; LED_0603_1608Metric
D48: SP0502BAHT; SOT-23
J1: AVR-ISP-6; PinHeader_2x03_P2.54mm_Vertical_SMD
J4: Screw_Terminal_01x04; PhoenixContact_MSTBA_2,5_4-G-5,08_1x04_P5.08mm_Horizontal
J20: UART 3V3 (FTDI pinout); PinHeader_1x06_P2.54mm_Vertical
L3: 10uH; C_0603_1608Metric
Q3, Q4: 2N7002; SOT-23
R1, R7: 10k; R_0603_1608Metric_Pad0.98x0.95mm_HandSolder
R2: 120; R_0603_1608Metric_Pad0.98x0.95mm_HandSolder
R8, R93, R97: 330; R_0603_1608Metric_Pad0.98x0.95mm_HandSolder
R27: 4.7k; R_0603_1608Metric_Pad0.98x0.95mm_HandSolder
R92, R95: 100k; R_0603_1608Metric_Pad0.98x0.95mm_HandSolder
R98, R99: 1k; R_0603_1608Metric
SW1: CHS-01TB; SW_DIP_SPSTx01_Slide_Copal_CHS-01B_W7.62mm_P1.27mm
SW2: B3U-1000P; SW_SPST_B3U-1000P
U2: ATmega1284P-A; TQFP-44_10x10mm_P0.8mm
U3: MCP2515; QFN-20-1EP_4x4mm_P0.5mm_EP2.5x2.5mm
U6: MCP2562-E-MF; DFN-8-1EP_3x3mm_P0.65mm_EP1.6x2.56mm
Y1: 16MHz; WE-XTAL_CFPX-180
Y2: 12MHz; WE-XTAL_CFPX-180

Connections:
+3.3V: C9.1, C15.1, C72.1, C73.1, D1.3, D3.3, J1.2 (VCC), L3.1, R1.1, R7.1, R93.2, R97.2, U2.5 (VCC), U2.17 (VCC), U2.38 (VCC), U3.18 (VDD), U6.5 (Vio); also elsewhere on the board
+5V: J4.3, U6.3 (VDD); also elsewhere on the board
/processor/CS_CAN: U2.40 (PB0), U3.16 (~CS)
/processor/INT_CAN0: U2.11 (PD2), U3.11 (~INT)
/processor/RST: C13.1, J1.5 (~RST), R7.2, SW2.1 (A), U2.4 (~RESET)
/processor/RX0: C69.1, R98.1, U2.9 (PD0)
/processor/RX0_EXT: D48.1 (K), J20.4, R98.2
/processor/TX0: C70.1, R99.1, U2.10 (PD1)
/processor/TX0_EXT: D48.2 (K), J20.5, R99.2
AMUX0: D1.1, U2.37 (PA0); also elsewhere on the board
CS_IN0: U2.41 (PB1); also elsewhere on the board
DEN0: U2.43 (PB3); also elsewhere on the board
DEN1: U2.44 (PB4); also elsewhere on the board
DEN2: U2.33 (PA4); also elsewhere on the board
DEN3: U2.32 (PA5); also elsewhere on the board
DRV_OUT0: U2.19 (PC0); also elsewhere on the board
DRV_OUT1: U2.20 (PC1); also elsewhere on the board
DRV_OUT2: U2.21 (PC2); also elsewhere on the board
DRV_OUT3: U2.22 (PC3); also elsewhere on the board
DRV_OUT4: U2.23 (PC4); also elsewhere on the board
DRV_OUT5: U2.24 (PC5); also elsewhere on the board
DRV_OUT6: U2.25 (PC6); also elsewhere on the board
DRV_OUT7: U2.26 (PC7); also elsewhere on the board
DSELn: U2.31 (PA6); also elsewhere on the board
EN_M0: U2.14 (PD5); also elsewhere on the board
EN_M1: U2.16 (PD7); also elsewhere on the board
FAULTMn: U2.12 (PD3); also elsewhere on the board
GND: C1.2, C2.2, C9.2, C10.2, C11.2, C12.2, C13.2, C14.2, C15.2, C16.2, C71.2, C72.2, C73.2, D44.2 (A), D46.2 (A), D48.3 (A), J1.6 (GND), J4.4, J20.1, J20.2, Q3.2 (S), Q4.2 (S), R8.1, R92.1, R95.1, U2.6 (GND), U2.18 (GND), U2.28 (GND), U2.39 (GND), U3.8 (VSS), U6.2 (VSS), U6.8 (SHDN), U6.9 (PAD); also elsewhere on the board
INT_B0: U2.42 (PB2); also elsewhere on the board
IPROPIM0: D3.2, U2.35 (PA2); also elsewhere on the board
IPROPIM1: D3.1, U2.34 (PA3); also elsewhere on the board
ISENSE_PROT: R27.2; also elsewhere on the board
MISO0: J1.1 (MISO), U2.2 (PB6), U3.15 (SO); also elsewhere on the board
MOSI0: J1.4 (MOSI), U2.1 (PB5), U3.14 (SI); also elsewhere on the board
unnamed: C69.2, D44.1 (K), Q3.1 (G), R92.2
unnamed: D45.2 (A), R93.1
unnamed: D45.1 (K), Q3.3 (D)
unnamed: C70.2, D46.1 (K), Q4.1 (G), R95.2
unnamed: D47.2 (A), R97.1
unnamed: D47.1 (K), Q4.3 (D)
unnamed: J4.2, R2.2, U6.6 (CANL)
unnamed: R8.2, SW2.2 (B)
unnamed: C14.1, U2.29 (AREF)
unnamed: C10.1, C71.1, L3.2, U2.27 (AVCC)
unnamed: C16.1, D1.2, R27.1, U2.36 (PA1)
unnamed: C12.1, U2.8 (XTAL1), Y2.1
unnamed: C11.1, U2.7 (XTAL2), Y2.3
unnamed: C2.1, U3.7 (OSC1), Y1.3
unnamed: C1.1, U3.6 (OSC2), Y1.1
unnamed: U3.20 (RXCAN), U6.4 (RXD)
unnamed: U3.19 (TXCAN), U6.1 (TXD)
unnamed: R1.2, U3.17 (~RESET)
PH_M0: U2.13 (PD4); also elsewhere on the board
PH_M1: U2.15 (PD6); also elsewhere on the board
SCLK0: J1.3 (SCK), U2.3 (PB7), U3.12 (SCK); also elsewhere on the board
nSLEEPMn: U2.30 (PA7); also elsewhere on the board

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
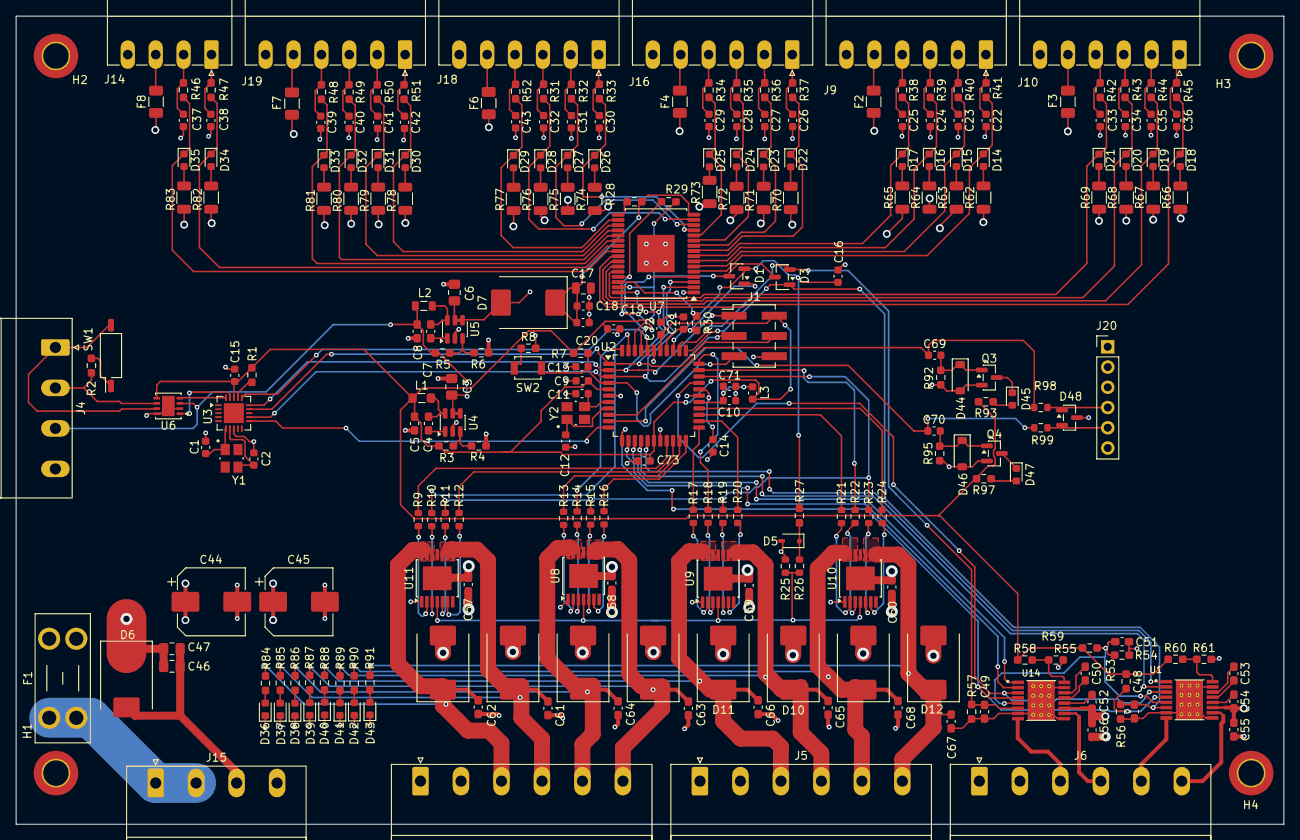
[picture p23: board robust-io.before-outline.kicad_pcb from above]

Board: 4 copper layers, 159.1 x 101.4 mm, 263 parts (0 on the bottom side), 187 nets.

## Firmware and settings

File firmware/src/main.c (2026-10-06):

/* Robust IO rev A firmware.
 * Foreground loop, 1 ms tick, UART console on J20, CAN protocol. See ../DESIGN.md. */
#include <avr/io.h>
#include <avr/interrupt.h>
#include <avr/wdt.h>
#include "board.h"
#include "hal/tick.h"
#include "hal/uart.h"
#include "hal/spi.h"
#include "hal/adc.h"
#include "drivers/hsd.h"
#include "drivers/motor.h"
#include "app/config.h"
#include "app/inputs.h"
#include "app/canproto.h"
#include "app/console.h"

static uint8_t reset_cause __attribute__((section(".noinit")));

/* Runs before C start-up: put every pin in the safe state, record why we
 * reset, and stop the watchdog so a watchdog reset cannot loop. */
void early_init(void) __attribute__((naked, used, section(".init3")));
void early_init(void)
{
    PORTC = PORTC_INIT; DDRC = DDRC_INIT;        /* outputs off first */
    PORTA = PORTA_INIT; DDRA = DDRA_INIT;
    PORTD = PORTD_INIT; DDRD = DDRD_INIT;
    PORTB = PORTB_INIT; DDRB = DDRB_INIT;

    reset_cause = MCUSR;
    MCUSR = 0;
    wdt_disable();

    /* PC2..PC5 are JTAG pins. The fuse should already disable JTAG; this is
     * the second guard. JTD must be written twice within four cycles. */
    MCUCR |= (1 << JTD);
    MCUCR |= (1 << JTD);
}

int main(void)
{
    config_load();

    tick_init();
    uart_init();
    spi_init();
    adc_init();
    motor_init();
    hsd_init();
    sei();

    delay_ms(20);                                 /* let the MC33978 and MCP2515 leave reset */
    inputs_init();
    config_apply();
    canproto_init(reset_cause);

    console_init(reset_cause);
    wdt_enable(WDTO_250MS);

    for (;;) {
        if (!console_reset_requested()) wdt_reset();
        console_task();
        hsd_task();
        motor_task();
        inputs_task();
        canproto_task();
    }
}

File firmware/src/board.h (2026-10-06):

/* Robust IO rev A - pin map and board constants.
 * Source: rev A netlist (U2 pad nets). See ../DESIGN.md section 2. */
#ifndef BOARD_H
#define BOARD_H

#include <avr/io.h>

#ifndef F_CPU
#define F_CPU            12000000UL   /* Y2 */
#endif
#define MCP2515_F_OSC    16000000UL   /* Y1 */
#define UART_BAUD        115200UL

/* Port A */
#define ADC_CH_AMUX      0            /* PA0  MC33978 AMUX */
#define ADC_CH_ISENSE    1            /* PA1  BTS7008 IS, shared */
#define ADC_CH_IPROPI0   2            /* PA2  motor 0 current */
#define ADC_CH_IPROPI1   3            /* PA3  motor 1 current */
#define DEN2_BIT         PA4          /* U9,  outputs 4, 5 */
#define DEN3_BIT         PA5          /* U10, outputs 6, 7 */
#define DSEL_BIT         PA6          /* shared, low = channel 0 of each device */
#define NSLEEP_BIT       PA7          /* DRV8876 nSLEEP, shared */

/* Port B */
#define CS_CAN_BIT       PB0
#define CS_IN_BIT        PB1
#define INT_IN_BIT       PB2          /* INT2, MC33978 INT_B, active low */
#define DEN0_BIT         PB3          /* U11, outputs 0, 1 */
#define DEN1_BIT         PB4          /* U8,  outputs 2, 3. Also SPI SS: keep as output */
#define SPI_MOSI_BIT     PB5
#define SPI_MISO_BIT     PB6
#define SPI_SCK_BIT      PB7

/* Port C: DRV_OUT0..7 on PC0..PC7, high = output on.
 * PC2..PC5 are JTAG pins: JTAGEN fuse must be unprogrammed. */
#define HSD_COUNT        8

/* Port D */
#define INT_CAN_BIT      PD2          /* INT0, MCP2515 INT, active low */
#define FAULTM_BIT       PD3          /* INT1, DRV8876 nFAULT, shared, active low */
#define PH_M0_BIT        PD4
#define EN_M0_BIT        PD5          /* OC1A */
#define PH_M1_BIT        PD6
#define EN_M1_BIT        PD7          /* OC2A */

/* Reset-state port values: everything off, chip selects high. */
#define PORTA_INIT       0x00
#define DDRA_INIT        ((1<<DEN2_BIT)|(1<<DEN3_BIT)|(1<<DSEL_BIT)|(1<<NSLEEP_BIT))
#define PORTB_INIT       ((1<<CS_CAN_BIT)|(1<<CS_IN_BIT))
#define DDRB_INIT        ((1<<CS_CAN_BIT)|(1<<CS_IN_BIT)|(1<<DEN0_BIT)|(1<<DEN1_BIT)| \
                          (1<<SPI_MOSI_BIT)|(1<<SPI_SCK_BIT))
#define PORTC_INIT       0x00
#define DDRC_INIT        0xFF
#define PORTD_INIT       ((1<<PD0)|(1<<PD1)|(1<<INT_CAN_BIT))   /* RX pull-up, TX idle high, INT pull-up */
#define DDRD_INIT        ((1<<PD1)|(1<<PH_M0_BIT)|(1<<EN_M0_BIT)|(1<<PH_M1_BIT)|(1<<EN_M1_BIT))

/* Scaling */
#define ADC_VREF_MV          3300UL   /* AVCC reference */
#define ISENSE_R_OHM         750UL    /* R25 */
#define BTS7008_KILIS        5400UL   /* datasheet typ; +/-4 % at 5.5 A, +/-30 % at 100 mA */
#define ISENSE_SETTLE_MS     2        /* datasheet worst case 0.4 ms at small load */
#define ISENSE_FAULT_MV      3000UL   /* fault current is >= 4.4 mA = 3.3 V on 750 ohm */
#define HSD_OFF_HIGH_MV      1000UL   /* off-state diagnosis current is 1.9..3.5 mA = 1.4..2.6 V */
#define HSD_LIMIT_MA_DEFAULT  5000     /* software trip level per output; set per channel with 'limit' */
#define HSD_TRIP_MS_DEFAULT  100      /* time over the limit before the output is switched off */
#define IPROPI_R_OHM         1500UL   /* 1000 uA per amp into 1.5k = 1.5 V per amp */
#define MOTOR_ITRIP_MA       1360     /* set by VREF divider, not firmware */

/* Configuration defaults (see app/config.c; all can be changed and saved) */
#define CFG_DEFAULT_NODE        0
#define CFG_DEFAULT_RATE_KBIT   250
#define CFG_DEFAULT_TIMEOUT_MS  500      /* host timeout, 0 disables */
#define CFG_DEFAULT_DEBOUNCE_MS 20
#define CFG_DEFAULT_WET_MA      16       /* MC33978 wetting current, power-on default */
#define CFG_DEFAULT_SLEW        10       /* motor duty change, percent per 10 ms */
#define CFG_DEFAULT_IDLE_MS     1000     /* motor drivers sleep after this long at zero */

/* MC33978 */
#define MC33978_INPUTS       22       /* bits 0..13 = SG0..SG13, bits 14..21 = SP0..SP7 */
#define MC33978_SPI_MODE     0        /* CHECK at bring-up: datasheet text says latch on rising edge.
                                         If the SPI check fails, try mode 1. */
#define MCP2515_SPI_MODE     0

#endif

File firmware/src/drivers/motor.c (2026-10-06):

#include <avr/io.h>
#include "board.h"
#include "hal/adc.h"
#include "hal/tick.h"
#include "drivers/motor.h"

#define WAKE_MS   2u        /* datasheet tWAKE max 1 ms */
#define STEP_MS   10u

static int8_t   target[2], actual[2];
static bool     awake, latched, hold;
static uint8_t  fault_count;
static uint16_t fault_ma[2];
static uint8_t  slew = CFG_DEFAULT_SLEW;
static uint16_t idle_ms = CFG_DEFAULT_IDLE_MS;
static uint32_t t_wake, t_idle, t_step;

/* Phase-correct 8-bit PWM, no prescaler: 12 MHz / 510 = 23.5 kHz.
 * Motor 0: EN on OC1A (PD5), PH on PD4. Motor 1: EN on OC2A (PD7), PH on PD6.
 * EN low = brake (both low-side on). */
static void hw_duty(uint8_t m, int8_t percent)
{
    uint8_t mag  = (uint8_t)(percent < 0 ? -percent : percent);
    uint8_t duty = (uint8_t)(((uint16_t)mag * 255u) / 100u);
    uint8_t ph   = (m == 0) ? PH_M0_BIT : PH_M1_BIT;
    if (percent < 0) PORTD &= (uint8_t)~(1 << ph);
    else             PORTD |= (uint8_t)(1 << ph);
    if (m == 0) OCR1A = duty;
    else        OCR2A = duty;
}

static void hw_sleep(bool asleep)
{
    if (asleep) PORTA &= (uint8_t)~(1 << NSLEEP_BIT);
    else        PORTA |= (1 << NSLEEP_BIT);
}

void motor_init(void)
{
    OCR1A  = 0;
    TCCR1A = (1 << COM1A1) | (1 << WGM10);
    TCCR1B = (1 << CS10);
    OCR2A  = 0;
    TCCR2A = (1 << COM2A1) | (1 << WGM20);
    TCCR2B = (1 << CS20);
    hw_sleep(true);
}

void motor_config(uint8_t s, uint16_t idle)
{
    slew = (s == 0) ? 1 : (s > 100 ? 100 : s);
    idle_ms = idle;
}

bool motor_command(uint8_t m, int8_t percent)
{
    if (m > 1) return false;
    if (latched) return false;
    if (percent > 100)  percent = 100;
    if (percent < -100) percent = -100;
    target[m] = percent;
    return true;
}

void motor_stop_all(void)
{
    target[0] = target[1] = actual[0] = actual[1] = 0;
    hw_duty(0, 0); hw_duty(1, 0);
    hw_sleep(true);
    awake = false;
}

void motor_hold_awake(bool on) { hold = on; }

void motor_clear_fault(void)
{
    /* The drivers were put to sleep when the fault latched, which clears them. */
    latched = false;
}

static int8_t step_toward(int8_t a, int8_t t)
{
    int16_t d = (int16_t)t - a;
    if (d >  slew) d =  slew;
    if (d < -slew) d = -slew;
    return (int8_t)(a + d);
}

void motor_task(void)
{
    uint32_t now = tick_ms();

    if (awake && (uint32_t)(now - t_wake) >= WAKE_MS && motor_fault_pin()) {
        if (!latched) {
            fault_ma[0] = motor_current_ma(0);
            fault_ma[1] = motor_current_ma(1);
            if (fault_count < 255) fault_count++;
            latched = true;
        }
        motor_stop_all();
        return;
    }
    if (latched) return;

    bool want = target[0] || target[1] || actual[0] || actual[1] || hold;
    if (want && !awake) {
        hw_sleep(false);
        awake = true;
        t_wake = t_idle = t_step = now;
        return;
    }
    if (!awake || (uint32_t)(now - t_wake) < WAKE_MS) return;

    if ((uint32_t)(now - t_step) >= STEP_MS) {
        t_step = now;
        for (uint8_t m = 0; m < 2; m++) {
            if (actual[m] != target[m]) {
                actual[m] = step_toward(actual[m], target[m]);
                hw_duty(m, actual[m]);
            }
        }
    }

    if (want) {
        t_idle = now;
    } else if ((uint32_t)(now - t_idle) >= idle_ms) {
        hw_sleep(true);
        awake = false;
    }
}

int8_t   motor_target(uint8_t m)       { return m < 2 ? target[m] : 0; }
int8_t   motor_actual(uint8_t m)       { return m < 2 ? actual[m] : 0; }
bool     motor_asleep(void)            { return !awake; }
bool     motor_fault_pin(void)         { return !(PIND & (1 << FAULTM_BIT)); }
bool     motor_fault_latched(void)     { return latched; }
uint8_t  motor_fault_count(void)       { return fault_count; }
uint16_t motor_fault_ma(uint8_t m)     { return m < 2 ? fault_ma[m] : 0; }

uint16_t motor_current_ma(uint8_t m)
{
    uint16_t mv = adc_read_mv(m == 0 ? ADC_CH_IPROPI0 : ADC_CH_IPROPI1);
    return (uint16_t)((uint32_t)mv * 1000UL / IPROPI_R_OHM);
}

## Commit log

2026-09-14 Initial commit: Robust IO KiCad project
    [inputs.kicad_sch, outputs2.kicad_sch, power.kicad_sch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]
2026-10-01 routed inputs and outputs
    [inputs.kicad_sch, outputs2.kicad_sch, power.kicad_sch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]
2026-10-01 mostly routed
    [power.kicad_sch, processor.kicad_sch, robust-io.kicad_pcb]
2026-10-05 Rev A: release to fab (JLCPCB, 5 PCB / 2 assembled)
    Board
    - Outline set to exactly 160 x 100 mm; plane zones resized to match
    - UART brought out on J20 (1x6 SMD, FTDI pinout) with series
    resistors R98/R99 and TVS D48
    - J1 and J20 changed to SMD headers (C52016780, C41417363)
    - L1/L2 moved to Sunlord SWPA4030S footprints; regulator tracks rerouted
    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
    [inputs.before-erc.kicad_sch, inputs.before-tp.kicad_sch, inputs.before-u7-soic.kicad_sch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]
2026-10-05 updated docs and added some previews/schematics
2026-10-22 2 boards built and bringup in process, no major issues so far
